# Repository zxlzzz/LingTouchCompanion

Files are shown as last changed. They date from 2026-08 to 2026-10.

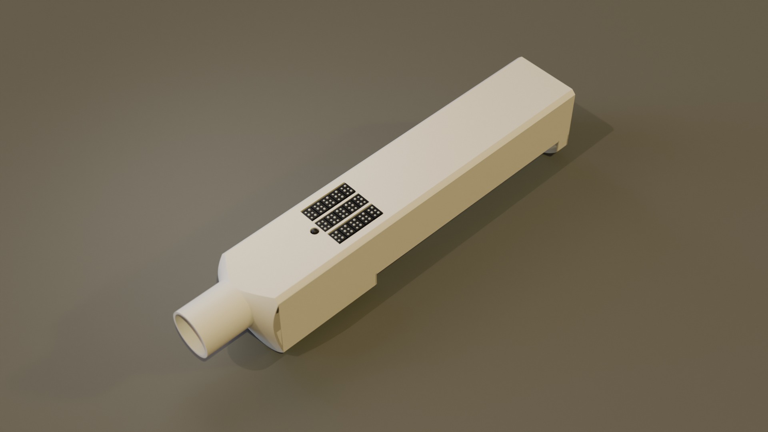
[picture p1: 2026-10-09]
BrailleModule_Video/ArrayPreview/EnclosureOverview.png

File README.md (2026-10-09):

# 灵触·随行 · LingTouch Companion

将视觉信息转换为触觉阵列反馈的辅助感知项目。当前实验使用手机摄像头、电脑端深度推理和 ESP32-S3，输出为 15 个六点模组，共 90 个触点。

给 Claude 的近期工作与审阅入口见 [CLAUDE.md](CLAUDE.md)。其中 PCB 布局和渲染外观仍待修正，验证记录不代表已经验收。

## 项目入口

| 目录 | 用途 |
|---|---|
| [visionss/](visionss/README.md) | 当前实验：米制深度、俯视栅格、BLE 传输与日志 |
| [single_point/](single_point/README.md) | 共用实验通路的单点告警对照条件 |
| [firmware/](firmware/README.md) | ESP32-S3 固件、引脚与通信协议 |
| [app/frontend/](app/frontend/README.md) | uni-app 手机应用 |
| [app/backend/](app/backend/README.md) | 地图、命令解析与视觉帧转发服务 |
| [vision/](vision/README.md) | 旧图像平面视觉管线，保留作回退 |
| [3mf/](3mf/README.md) | 前件、后件与两件式手柄的模型、完整生成代码及必要输入 |
| [PCB 修订稿](PCB_REDESIGN_2026-10-08/README.txt) | 五页原理图及实际板、98×98 mm 测试板的未布线布局草稿 |
| [阵列编排与渲染](BrailleModule_Video/ArrayPreview/README.md) | 离线网页编排与 Cycles 渲染流程，外观仍待修正 |

## 运行实验

在仓库根目录、配置好依赖的 Python 环境中运行：

```powershell
python visionss/phone_server.py
```

本机已验证环境为 `D:\anaconda\envs\LING\python.exe`。模型准备、手机连接与操作见 [实验说明](visionss/README.md)。

## 浏览器工具

| 文件 | 用途 |
|---|---|
| [depth_preview.html](depth_preview.html) | 图片深度预览；先运行 `python visionss/depth_server.py` |
| [ble_mobile_controller.html](ble_mobile_controller.html) | 手机 BLE 点阵控制，使用 ROT180 映射 |
| [ble_testbench.html](ble_testbench.html) | 点阵与帧数据调试，保留旧 PROD 映射 |

BLE 页面需要浏览器提供 Web Bluetooth；两种映射不同，须与实际装配方向对应。

离线标定和距离验证见 [TOPDOWN_VALIDATION.md](TOPDOWN_VALIDATION.md)，工具为 `validate_distance.py`、`check_balloon_depth.py` 和照片复制脚本 `prep_new_pics.py`。

模型、测试照片、实验输出、论文材料和本地协作记录不随 Git 上传；源码、HTML 工具与必要配置保留在仓库中。

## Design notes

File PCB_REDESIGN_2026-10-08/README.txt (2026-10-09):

灵触随行｜原理图与两款 PCB 摆件稿
基准：2026-10-08 读取的云端 test / PCB1_5；交付日期：2026-10-09。

审阅状态（2026-10-09 更新）
这两块板仍是待修正的布局草稿，尚不适合直接开始布线。后续复查已撤回“布局优化完成”的结论：
- U49的R7/R8反馈端焊盘距FB脚约9.6/11.5mm，两板均沿用该排列，需要重新组织反馈区。
- J1 USB与U53充电芯片中心距离，实际板约53mm、测试板约68mm，需要复查充电路径与局部摆放。
- 测试板的U50/L2等仍位于ESP下方，不利于探测、观察和返修；至少4mm净高尚未实物确认。
- 模组插座型号、插拔空间、螺钉头与支柱占位尚未落实。二维不重叠不能证明实物装配可行。
这些是后续检查指出的待解决项，本文件包尚未按它们修改。validation.json保留此前数字核对记录，
不表示上述问题已经解决，也不代表完整DRC、制造、载流或装配签核。

文件
Revised_Schematic.epro：嘉立创原生工程，包含全部五页修订原理图。
Actual_Placement.epro2：实际板，191.7065 × 35.7505 mm。
Test98_Placement.epro2：测试板，98 × 98 mm。
actual_placement.png、test_placement.png：正反面布局预览；背面已按从板底观察的方向翻转。
schematic_1 至 schematic_5：嘉立创导出的五页原理图预览。
validation.json：网络、布局、导出文件核对记录。

云端位置
项目 test；原理图 Revised_Schematic_20261008。
实际板 Actual_Placement_20261008；测试板 Test98_Placement_20261008。
两个 PCB 均为新增副本，原 PCB1_5 保留。实际板关联修订原理图；测试板是同一电路的独立 PCB 版本。
两板均保留六层：内层1 GND 平面、内层4 VCC 平面，其他四层供后续布线。
本稿仅摆件，未布线、未铺铜；Q1 封装自带的4个过孔保留。

原理图修改
1. 分为输入与充电、电源轨、ESP与控制、驱动1–8、驱动9–16五页；以功能框和明确网络名组织。
2. 增加 R40/R41/R42：SER、SRCLK、RCLK 的47kΩ下拉，避免上电阶段信号悬空。
3. 增加可选 J_NTC 接口。默认不焊，R22仍为51kΩ，温度检测仍处于禁用配置。
   若以后接100kΩ/B4100电池温度传感器，须同时把R22改为82kΩ；当前文件未替你改成该装配方案。
4. 保留现有16级595＋ULN、15个正式模组和U48实验位，保留既定电源、反向阻断、欠压与OE门控架构。
   U48、SW1、J_test、J_NTC按可选位标记不进BOM，焊盘全部保留；两板器件集合相同，共179件。
5. 主要电源选值保持当前版本：U49的R1=6.65kΩ、L1=1µH、MODE电阻30.1kΩ；VCC约3.53V；
   U50输出约2.00V、L2=2.2µH；U51固定5V、L3=1µH；IP2326约8.3V/1A配置。
   R23的0.5Ω仅位于充电芯片VIN滤波支路，L4主电流入口仍直接接VIN_C。

布局考虑
实际板保留原板框、U31–U45/U48的位置与方向，短边不加宽；ESP两排插座间距仍为25.4mm。
ESP与两排插座作为整体旋转180°并向板端平移，让天线伸到板外。充电接口和拨动开关移离天线端。
电源按各转换器局部成组，输入旁路、开关电感和控制小器件分区；595与ULN分布在正反面。
测试板保留全部16组，按4×4展开，留出模组插座与焊接空间；电源和ESP位于板的另一侧，外设接口靠边。
两板均保留原来的电池大焊盘、Q1封装过孔、每组595去耦与模组电容。
USB端C66与充电端C65分别保留局部旁路。后续VIN_C、电池入口和线圈电源的线宽/铜面仍须按实际电流完成布线。

已核对与仍待确认
已核对：179件一致；1062项已连接引脚的网络对应；原模组固定位置；ESP间距；板框尺寸；
焊盘间距、板边间距、跨面通孔与器件外形、安装孔；原生导出中的器件、封装和层设置；保存后重新打开。
原理图检查保留一组触觉模组的ATTRMATCHCODE警告，来自原有借用器件属性。模组应按真实触觉模组选用，不能按借用料号采购。
PCB原生DRC在后台未返回结果；上述核对不等于整板DRC或制造签核。当前未进行满载、温升、环路或BLE实测。

装配尺寸待确认：底板表面到ESP开发板底部最低器件需至少4mm净高，给其下约3mm高的L2留出余量。
该净高尚未得到实物确认；检查本稿时请优先核对排母高度。触觉模组插座仍须按原模组引脚尺寸选型，不能默认使用普通2.54mm排母。
本次未改固件。保留16级链，启用输出前应正确清零全部16级；最终固件适配另行处理。

主要查证资料
YD-ESP32-S3厂商尺寸与引脚资料：https://github.com/vcc-gnd/YD-ESP32-S3
IP2326手册：https://m5stack-doc.oss-cn-shenzhen.aliyuncs.com/1132/IP2326.pdf
RT6253A手册：https://www.richtek.com/assets/product_file/RT6253A=RT6253B/DS6253AB-04.pdf
TPS63070/701手册：https://www.ti.com/lit/ds/symlink/tps63070.pdf

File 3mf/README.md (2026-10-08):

# Complete 3D model generators

This folder contains the retained printed front, final rear, two-object handle,
all required source inputs and their generation code. Keep this folder together.
The desktop originals and former repository-root model directories are not
required. Installed dependencies are separate from the portable source set.

From the repository root, reproduce and verify all models with the local runtime:

```powershell
./3mf/.runtime/structural-runtime/Scripts/python.exe -B 3mf/regenerate.py --require-baseline
```

On another machine, use Python 3.11 and install the retained dependency versions:

```powershell
python -m pip install -r 3mf/requirements.txt
python 3mf/regenerate.py --require-baseline
```

Final model files:
- [Printed front](Headset_WOAD_Front_2026-10-03/camera_mount/Front_CS30_Mount_Print.3mf)
- [Printed rear](Headset_Rear/revised/Rear_Revised_Print_Ready.3mf)
- [Rear with head/battery references](Headset_Rear/revised/Rear_Revised_Wearing.3mf)
- [Two-object handle print project](Handle/Handle_Print.3mf)
- [PCB with U31-U45 and U48 socket models removed](PCB/3D_PCB1_5_2026-09-15_no_U31-U45_U48_headers.step)

The PCB STEP copy has its own [regeneration and verification instructions](PCB/README.md).

The original manual handle 3MF already has two model objects. Both are retained
with their original local meshes, component links, build transformations, assembly
metadata, printing settings and thumbnails. No new cut or inferred assembly pose
is introduced. The unchanged generated handle archive is byte-identical to the
supplied desktop `1.3mf`; the printed front is likewise byte-identical to its
supplied final source. Both geometries remain mesh-based because 3MF carries no
CAD construction history.

Entry points for later edits:
- Front: `Headset_WOAD_Front_2026-10-03/camera_mount/build.py`, `modify_front()`.
- Rear: `Headset_Rear/build.py` and `Headset_Rear/revised/build.py`.
- Handle: `Handle/build.py`, `modify_part()` for `housing` or `cover`, in each
  original native mesh coordinate frame (millimetres).

Front-only, rear-only and handle-only `regenerate.py` scripts live in the
corresponding folders. `--verify` validates edited front/handle meshes against
the generated outputs; `--require-baseline` also requires unchanged source
identity. The rear construction retains the original array-hash, topology,
contact-surface and preserved-region checks.

Required geometry inputs are in `Headset_Inputs`, `Headset_Rear/inputs` and
`Handle/inputs`. `requirements.txt` is shared. `.runtime` contains this machine's
reusable dependency environment and is excluded from Git; use its Python directly
or `python -m pip`, since moved virtual-environment launcher scripts may retain
their original installation paths. No existing intermediate is required.
Generated `geometry` and `checks` folders may be removed after running.
Digital identity confirms reproduction of the supplied data, not physical fit.

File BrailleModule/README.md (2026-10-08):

# Braille module - static exterior model

This folder is independent of `3mf/`. The model follows the supplied module PDF
and Hsinlung's material instructions: a black housing and slightly grey white
tactile dots. It includes the housing, lower collar/carrier, locating tab,
twelve stamped terminals and six individually named dots.

## Files

- `BrailleModule.blend`: editable Blender 4.5 scene, materials and preview lighting.
- `BrailleModule.glb`: portable model with materials and separate parts; no studio objects.
- `BrailleModule.step`: millimetre CAD assembly with the same parts and colours.
- `Preview.png`, `Preview_Back.png`, `Preview_Top.png`, `Preview_Dots.png`: rendered views.
- `parameters.json`, `build.py`, `requirements.txt`: retained editable generator.
- `inputs/Braille_Module_Reference.pdf`: unchanged supplied reference.
- `inputs/Touchpoint_Reference.jpg`: supplied physical-module photograph.
- `Verification.json`: geometry, dimensions and export readback checks.

## Dimensions and interpretation

The PDF explicitly dimensions the body as 8.2 x 6 mm, with a height of 20 mm
excluding the terminals. The maximum base width is 10.82 mm, including the
asymmetric tab. Terminals extend 3.8 mm below the base. Their pitch is 1.25 mm,
tail width 0.30 mm and sheet thickness 0.10 mm. The 4.96 mm drawing dimension
spans the inner faces of the two terminal sheets, giving 5.06 mm centre spacing.
The two rows use the 2.05 and 2.65 mm opposite-view end offsets and are staggered.

Unmarked dimensions, including dot diameter/pitch, recesses, collar height and
terminal shoulders, are reconstructed from drawing proportions. Shell wall and
cap thickness are visual construction choices. These are recorded separately
from dimensioned values in `parameters.json`. The interior actuator mechanism
is not established by this document and has not been invented in the model.
Actual lower carrier colour and plating appearance remain unverified.

All six dots have spherical-cap heads, matching the curved tips in the PDF
and the two raised points in the supplied photograph. The former flat-topped
visible cylinders have been replaced. The 0.45 mm cap height is an exterior
estimate, not an explicitly dimensioned value: the PDF's 0.4-0.5 mm figure is
the raised-point height above the housing. Cap diameter and dot spacing retain
the initial model values. Housing, base, terminals, positions and materials
remain unchanged.

All six dots are in the same retracted static state, with their apices flush
with the 20 mm tactile face and their curved sides inside the openings. There
are no keyframes or raised-dot states. In a top view with the locating tab at the top, dots 1/2/3
form the left column and 4/5/6 the right column, following PDF page 6. Each dot
has its own origin and can later move along its local +Z axis. Terminal names
`Pin_01` through `Pin_12` are geometry indices, not a verified electrical map.

Blender and GLB store metre coordinates, with Blender displaying millimetres.
STEP uses millimetres. The overall assembly is 10.82 x 6 x 23.8 mm.

## Regenerate

On this machine, from the repository root:

```powershell
& '3mf/.runtime/structural-runtime/Scripts/python.exe' -B 'BrailleModule/build.py'
```

This uses the existing modelling runtime without writing model outputs into
`3mf/`. On another machine, install `requirements.txt` in a Python 3.11
environment and run `python -B build.py`. `--no-render` skips the preview images.

Verification checks each CAD solid and tessellated mesh, reloads the STEP/GLB,
checks the overall dimensions and ensures all six dot apices remain flush. It does
not establish exact agreement of unmarked details with the physical module.

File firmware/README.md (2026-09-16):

# ESP32-S3 触觉固件

通过 SPI 驱动15个六点模组，BLE接收15字节触觉帧。

## 烧录

Arduino IDE 安装 **esp32 by Espressif Systems**，选择 **ESP32-S3 Dev Module**，打开 [当前 V2.8 固件](braille_15module_prod/braille_15module_prod.ino) 并烧录。

`braille_15module_reverse/` 为旧 V2.3 版本，保留作历史参考，不是当前默认入口。

## 引脚与协议

| 信号 | GPIO |
|---|---|
| SER / SRCLK / RCLK | 11 / 12 / 10 |
| OE# / SRCLR# | 9 / 8 |
| 按钮 | 6 |

BLE 服务 `FFE0`：写入特征 `FFE1` 接收15字节，每字节低6位对应一个模组；通知特征 `FFE3` 中，`0x01` 为刷新完成，`0x04` 为按键扫描请求。

V2.8 默认全量刷新约220 ms。电脑端实验通路见 [visionss](../visionss/README.md)；浏览器调试可使用根目录两个 BLE 工具，注意其 ROT180 / PROD 映射差异。

[PCB历史摘要](PCB历史检查摘要.md) 与 [早期改版记录](pcb_v2_revision.md) 仅供追溯，不代表当前生产板状态。

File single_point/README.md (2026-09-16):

# 单点告警对照条件

共用 [实验视觉通路](../visionss/README.md) 的拍摄、深度推理、调度、日志和 BLE，仅将空间栅格输出替换为二值告警。

在仓库根目录运行：

```powershell
python single_point/alert_server.py
```

默认 HTTPS 8761；加 `--no-ble` 可不连接设备运行。终端操作与空间触觉条件一致。

`alert_pipeline.py` 检测前方0.5–2.5 m、左右各0.35 m、离地0.10–1.80 m范围；占据比例阈值0.035，至少8点。触发时点亮 M11 整个模组，输出位置由 `visionss/experiment_server.py` 中的 `ALERT_MODULE` 定义。

正式实验前需用实际障碍物核对阈值与检测范围。

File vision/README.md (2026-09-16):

# 旧视觉管线

早期图像平面相对深度 / 边缘检测方案，保留作回退。当前米制深度实验使用 [visionss](../visionss/README.md)。

## 运行

依赖见 [requirements.txt](requirements.txt)。以下命令在仓库根目录运行：

```sh
python vision/phone_server.py --no-ble
python vision/main.py --mode edge --camera 0 --debug
```

`phone_server.py` 提供手机拍摄与 BLE 通路；去掉 `--no-ble` 可连接设备。`main.py` 支持 `depth` / `edge` 模式及文件、串口、HTTP等输出，完整参数见 `--help`。

## 工具

| 文件 | 用途 |
|---|---|
| `live_preview.py` | 摄像头实时预览 |
| `bench_test.py` | 驱动链调试 |
| `export_sample.py` / `generate_comparison.py` | 样本导出与对比图 |
| `calibrate_balloon_color.py` / `color_bias_test.py` | 旧颜色检测与偏差验证 |
| `frame_converter.py` / `scan_link.py` | 15字节帧转换与 BLE 连接 |

旧串口等输出路径与当前 BLE 固件不一定使用相同帧格式，接硬件前核对对应输出实现。生成数据位于 `data/`，不提交。

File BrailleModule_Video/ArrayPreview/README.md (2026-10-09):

# Array preview and Cycles production rendering

`index.html` is the offline point-pattern editor and interactive preview. Final pictures and video come from **Cycles in `EnclosedArray.blend`**. Browser shadows, aperture shading and materials are preview approximations.

## Review status — 2026-10-09

Hsinlung has viewed these stills and judged the appearance insufficiently realistic. Raised and retracted dots are similarly bright, and the module top does not match the supplied physical references. The files below are retained for review, not approved production output. No full animation is approved.

The latest discussion proposes matching the photograph on one module first: camera and state, grazing directional light and ambient fill, separate retracted depth and raised exposure, then dot subsurface appearance and top-face shading. Fine texture follows those checks. This revision has not been implemented. A suggested −0.3 mm rest offset is an unmeasured trial value; shifting the whole existing animation would also lower its raised exposure.

`assets/textures/Plastic003/` retains Hsinlung's selected procedural material candidate, with its source, CC0 license and hashes. Its maps are not applied to the current scene. The unselected Plastic012A download was removed. See the repository's `CLAUDE.md` for the wider review handoff.

## Current stills

- `PinCloseup.png`: the browser's tactile-array preset, with the checker pattern.
- `SwitchPreview.png`: the browser's enclosed-switch preset.
- `EnclosureOverview.png`: the browser's whole-handle preset.

These replace the preceding browser screenshots: 1920 × 1080, 192 samples, environment lighting, depth of field and light monochrome grain. Revised stills require Hsinlung's acceptance before a full shot is rendered. No full animation has been rendered during this migration.

## Edit and render

Open `index.html`, edit or import a 10-row × 9-column sequence, then choose **导出 JSON**. The page is self-contained and needs no network. `launch.cmd` optionally serves it at `http://127.0.0.1:8867/`.

Run the retained runtime from the repository root:

```powershell
# Update the existing scene and render three review stills.
& '3mf/.runtime/structural-runtime/Scripts/python.exe' -B 'BrailleModule_Video/ArrayPreview/render_cycles.py' stills

# Import a newly exported browser sequence and rebuild the stills.
& '3mf/.runtime/structural-runtime/Scripts/python.exe' -B 'BrailleModule_Video/ArrayPreview/render_cycles.py' stills --sequence 'C:/path/frames.json'

# Only after still approval: render lossless 16-bit PNG sequences.
& '3mf/.runtime/structural-runtime/Scripts/python.exe' -B 'BrailleModule_Video/ArrayPreview/render_cycles.py' render

# Compose PNG sequences into H.264 MP4 with changing monochrome grain.
& '3mf/.runtime/structural-runtime/Scripts/python.exe' -B 'BrailleModule_Video/ArrayPreview/render_cycles.py' compose
```

`prepare` updates the existing scene without rendering. `verify` checks the saved animation. `--shot near|switch|whole|all` selects a shot; `--width`, `--height`, `--samples` control quality. `--frame` selects a still frame. `--fps` and `--tail` configure the timeline during preparation. Defaults: 1920 × 1080, 192 samples, 30 fps, one second after the final JSON command.

`assets/sequence.json` is the active sequence. The current five-frame sequence is exactly the browser's built-in demo: off, checker, cross, all on, off. The review still uses frame 46, 1.5 seconds into the sequence: 45 raised points at maintained height. This is an appearance demo, not an experiment log. Timestamps are milliseconds; the first timestamp becomes time zero. JSONL, a `{frames: [...]}` object, a single record and a single 10 × 9 matrix are also accepted.

Full shots write `frames/<shot>/frame_0001.png` onward. Composition writes `Array_near.mp4`, `Array_switch.mp4` and `Array_whole.mp4`. The Blender runtime includes the FFmpeg encoder; no separate installation is needed. Optional `--ffmpeg` selects an external encoder. The original PNGs remain unmodified during composition.

## Scene and material sources

The existing assembly is retained: 15 modules, 90 independently moving complete pins, the two original handle meshes and the bullet-head switch. Original vertices, topology, module placements and handle placements are preserved. Three-segment bevel modifiers round module edges by 0.06 mm and handle edges by 0.18 mm. Smaller shader bevels soften microscopic highlights.

Blender's bundled `interior.exr` is packed into the world, with one soft window light. The grey tabletop extends beyond the camera frustum. Module black plastic uses dielectric reflection with no metallic or emissive shading. `assets/textures/MouldDetail.png` is extracted from `../inputs/Touchpoint_Reference.jpg`: perspective correction, pin/rim masking and removal of broad lighting. Grayscale detail controls narrow roughness variation and microscopic bump rather than baking photographed highlights into the black colour. `../inputs/PhysicalMotionReference.mp4` is also the visual reference. The photograph has limited detail; this is an appearance reconstruction, not a measured PBR scan.

Ivory PLA printing detail keeps the browser's existing settings: 0.2 mm side layers, 0.42 mm diagonal top paths, 0.0035 mm side relief and 0.0014 mm top relief. These are visual settings. All image assets needed by Cycles are packed into the .blend.

The three cameras use `viewer3d.js` `setView` directions, bounds fitting and horizontal field of view, adapted to 16:9. Focus is on the tactile face, switch nose or device centre; apertures are f/22, f/32 and f/8. Motion blur uses a half-frame shutter. Cameras stay fixed; dot motion supplies motion blur.

## Motion and mapping

`assets/motion.json` is the shared source: 0.7 mm peak, 0.45 mm hold, 33.333 ms rise, 66.667 ms peak pause, 50 ms settle and 50 ms retraction. These remain provisional visual settings informed by the supplied 30 fps clip. Fractional linear keyframes preserve short stages and let Cycles evaluate shutter subframes. Repeated identical commands leave an ongoing stroke alone. Mid-stroke commands reverse from the current height.

M1–M15 go left to right, then top to bottom. Each module's upper row is dots 3/2/1 and lower row is 6/5/4. The PCB arrangement stays three columns by five rows: approximately 11 mm horizontal and 6.5 mm vertical centre spacing, including the first column's 0.127 mm offset.

`CyclesVerification.json` records mesh preservation, references, cameras and animation checks. Motion is compared directly against the actual `controls.js` function, including mid-stroke reversals; all 90 saved animations are checked at fractional frames. This verifies migration and timing, not perceptual realism or manufacturing fit.

## Geometry and browser maintenance

`ModuleArray.blend`, `build_array.py` and `surface_finish.py` retain the source array. `build_enclosure.py` is only for an intentional geometry rebuild; it reapplies production materials and animation after exporting the preview GLB. Routine appearance or sequence changes use `render_cycles.py` on the existing scene.

The enclosure source stays `../../3mf/Handle/inputs/Handle_Original.3mf`, with 71,860 housing and 670 cover triangles. STEP offsets recover the assembly frame. The 30.7 mm array translation, original slots and 90 crown clearances are retained; see `EnclosureVerification.json`. These checks do not establish PCB mounting fit.

The switch retains the user-directed 20 mm height excluding terminals, and smooth 4.2 mm wide, 2.6 mm high bullet nose. Its tip stays 1.2 mm above the faceplate; it differs from the BOM's 25 mm TSA06131 variant. It is static and does not control BLE. Dimension provenance remains in `SwitchVerification.json` and `../inputs/Khon_TSA06131_Reference.pdf`.

Browser sources are `viewer3d.js`, `controls.js` and `index.template.html`. Run `npm run build` to regenerate the self-contained HTML. Dependencies remain pinned, with licenses in `vendor/`. The page has no real-hardware control.

When only the template, JSON or preview GLB changes, `node build_web.mjs --page-only` reuses the existing viewer bundle and updates the embedded page assets.

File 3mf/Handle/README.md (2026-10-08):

# Manual two-object handle recovery

`inputs/Handle_Original.3mf` is the unchanged manual source supplied on 2026-10-06.
SHA256: 25cd55ec492a72cccf81dd1d16a50490106574b93a2b63005601ec6ab786d6c6.
`Handle_Print.3mf` contains the original two separately selectable model objects;
no added split plane or new joint is constructed.

Run `python 3mf/Handle/regenerate.py --require-baseline` from the repository root.
`source.py` resolves the archive's external production-model links and all build
and component transforms. `build.py` recovers each native mesh and print mesh;
`export.py` preserves the whole source archive for an unchanged build. Verification
compares every vertex, triangle, transform and ZIP member, including print settings
and assembly metadata.

The housing has 35,944 vertices and 71,860 triangles. The cover has 329 vertices
and 670 triangles. Both have closed manifold meshes. The housing's original mesh
contains eight constituent solid components; the cover contains one. These
source components are retained exactly, without welding or automatic repairs.
This is an exact recovery of the source model objects, not a new physical
connectivity or manufacturing certification.

For future changes, edit `modify_part()` in `build.py`, using each original native
mesh frame. `--verify` accepts deliberate edits while reporting baseline changes;
`--require-baseline` requires the entire finished archive to remain identical.

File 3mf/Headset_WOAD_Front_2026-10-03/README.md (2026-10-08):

# Retained front and rear

This directory is part of the complete `3mf` source set. See [../README.md](../README.md)
for dependency setup, all final outputs and the combined regeneration command.
From the repository root:

```powershell
python 3mf/Headset_WOAD_Front_2026-10-03/regenerate.py --require-baseline
```

This rebuilds the retained rear and the actual printed front. Front-only entry:
`camera_mount/regenerate.py`. The front is edited through `modify_front()` in
`camera_mount/build.py`; it uses the source print axes with bed centre
(165, 160, 0) removed. The immutable finished front archive is retained in
`../Headset_Inputs/Front_CS30_Mount_Final.3mf`.

The unchanged front archive is reproduced byte for byte. Old camera/head fit
assemblies are not reused. The rear uses the anatomical tray/fill inputs in
`../Headset_Rear/inputs`, its construction scripts and provenance. Its wearing
reference also requires the original head STL and registration in
`../Headset_Inputs`. No deleted file or desktop original is required.

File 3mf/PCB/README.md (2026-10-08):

# PCB STEP with module sockets removed

Use `3D_PCB1_5_2026-09-15_no_U31-U45_U48_headers.step` for the modified PCB assembly.
The original 2026-09-15 export is retained unchanged under `inputs/`.

Only the 16 female socket models at U31-U45 and U48 are removed. U46 and U47
are chips in this export and remain unchanged. PCB copper, holes,
other components, colours and placements are preserved.

Regenerate from the repository root:

```powershell
python 3mf/PCB/remove_module_headers.py
```

The generator requires only Python's standard library. To repeat the CAD check,
install `cadquery-ocp==8.0.1.1.0` and run with `--verify`. This machine already
has that dependency in `3mf/.runtime/structural-runtime`.

Verification requires the original source SHA256, validates all STEP references,
and checks that all retained entity records except the root placement list are
byte-identical. The unused shared socket definition is also removed to prevent
it from appearing as an unattached object. CAD import confirms 179 to 163 top-level objects,
with unchanged solid/face/edge counts, volumes, centres and bounds for every
retained object. This edit changes the exported 3D assembly only.

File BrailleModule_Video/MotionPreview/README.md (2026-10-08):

# Module motion preview

Run `launch.cmd`, then open <http://127.0.0.1:8866/> in Chrome or Edge. If the
preview is already running, open that address directly. The launcher uses the
existing project Python runtime and serves this folder on the local computer.

Click the picture to focus it, then press **1–6** or the corresponding numeric
keypad keys. Each key controls its own dot: retracted → higher peak → lower
maintained position. Press the same key again to retract it. The six buttons
provide the same controls. **全部收回** retracts all dots; **显示编号** identifies
their positions. Held keys do not repeatedly toggle a dot.

The current visual settings are:

| Stage | Height / duration |
| --- | --- |
| Retracted | 0 mm |
| Rise | 33 ms, reaching 0.70 mm |
| High peak pause | 67 ms |
| Settle | 50 ms, reaching 0.45 mm |
| Maintained | 0.45 mm, until toggled off |
| Retract | 50 ms |

These heights and timings are provisional preview choices, not measured
manufacturer specifications. The three-stage behavior follows Hsinlung's
requirement. Both the browser and Blender scene read the same
`assets/motion.json` profile and use firm linear strokes, followed by a stable
hold. The fixed-camera preview uses actual 3D-rendered height samples
from the approved photographic scene, including changing occlusion, shadows,
and highlights. It displays one nearest rendered height per frame to retain a
single sharp moving contour. The dots lift along their axes without elastic
wobble. The six pins now use one neutral grey-white finish for the complete
round head and straight shaft, with a small smooth join instead of a sharp
shading boundary. Their camera-visible body colour is kept uniform following
Hsinlung's correction. The photographic lighting and housing remain intact.

`build_appearance.py` creates `AppearanceStudy.blend` from the archived
photographic setup; `build_motion.py` adds the existing motion to this corrected
appearance. `render_assets.py` renders the corresponding preview poses.

The approved static scene is archived in
`../Archives/PhotoStudy_2026-10-07/`, including `ReferenceStudy.blend` and its
photographic previews. The source `../PhotoStudy/` remains available.

`ModuleMotion.blend` contains the editable 3D scene and a 60 fps sample timeline
(frames 1–430): each dot rises in turn, all remain raised, then all retract.
Select the root object **BrailleModule** to find `Dot_1_height_mm` through
`Dot_6_height_mm` under Object Properties → Custom Properties. Their animation
curves can be adjusted in the Graph Editor; timeline playback applies the
existing height keys. The browser provides the live keyboard controls.

The [user-provided Dot Pad video](https://www.youtube.com/watch?v=iSmRM2PUBzA)
was inspected around 6–8 seconds for axial movement and changing hole
occlusion. Revision 2 primarily follows Hsinlung's supplied physical-module
video (`../inputs/PhysicalMotionReference.mp4`, 11.4 seconds, 30 fps). In that
clip, lift is visible between frames
69–70 (2.300–2.333 s) and 256–258 (8.533–8.600 s); release is visible between
frames 300–302 (10.000–10.067 s). These observations support short strokes
and firm stops. Camera movement, compression, and the frame rate prevent
precise measurement of the high-to-maintained drop. Its height difference and
timing remain provisional choices for the requested three-stage effect.

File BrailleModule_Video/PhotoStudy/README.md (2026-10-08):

# Photographic module study

One clean photographic material and lighting setup, with two camera views:

- `ReferenceStudy.png`: 1200 x 1600, composition based on the supplied physical-module photograph.
- `VideoCloseup.png`: 1920 x 1080, a closer horizontal view for assessing later video footage.
- `ReferenceStudy.blend`: editable, self-contained scene containing both cameras.
- `Verification.json`: geometry, source and render checks.
- `build.py`: reproducible scene setup.

The study uses the accepted model in `../BrailleModule.blend`. Its 22 component
meshes and local positions remain unchanged. All six dots stay retracted and
independent. There is no animation, dirt, wear or image compositing. The whole
assembly rests on its back broad face on a pale laminate table.

Clean moulded-polymer roughness and microrelief, grey-white smooth tactile
heads, directional lighting and the table's reflected light determine the
appearance. Perspective cameras and optical depth of field provide the two
views. The top's grey reflection does not represent a change to a metal shell.
These are appearance trials; single-image evidence does not establish the exact
physical material, roughness or lens of the reference.

References: the supplied `../inputs/Touchpoint_Reference.jpg`, the supplier PDF
for geometry, and [Dot Inc's supplied video](https://www.youtube.com/watch?v=iSmRM2PUBzA).
The video was inspected in the browser at 6, 12, 18, 25, 32, 45 and 51 seconds;
the low-angle view around 6 seconds was especially useful for surface highlights.
Dot Pad imagery informs photography only, not this module's design.

Rebuild from the repository root using the existing Blender runtime:

```powershell
& '3mf/.runtime/structural-runtime/Scripts/python.exe' -B 'BrailleModule_Video/PhotoStudy/build.py' --final
```

The original `BrailleModule/` and frozen parent-folder source files are preserved.

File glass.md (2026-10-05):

# 国赛眼镜硬件方案 v10（2026-10-02）

本文件记录当前硬件组成、用途和连接依据。部件类别与功能分工已基本明确；没有查到必须推翻整体架构的硬件冲突，但尚未完成整机验证。当前不继续搜索具体商品型号，也不展开固件、采集参数或算法实现。

## 已定方向

- 继续采用 **CS30＋Radxa ZERO 3W**，相机、主板、电池等都放在眼镜上。
- **预警和障碍分析都用这副眼镜的数据。计算位置仍在权衡：** 眼镜采集后经 Wi-Fi 发手机计算，或眼镜本地计算、只把结果发手机。两种做法眼镜上的器件相同；外壳散热按眼镜本地计算的满负荷预留，计算位置最后怎么定都不用改壳。
- **全机免焊：** 优先购买成品模块、成品电源及预制线束，需要焊接或装配的部分尽可能由卖家或代工完成；不自行制作电池组，不另做自研主控 PCB。
- **电池尚未定型，已查资料保留在第四节。** 整机以单个Type-C接口输入稳定5V供电为目标，优先5V/3A成品电源；内部向主板及相机分电的成品连接方案尚未定完整。成品候选、代工入口和续航估算用于后续比较，不代表已经选定或完成装机验证。
- **整机约300g可接受；电池位置不受限，必要时做成头环、电池放后脑。**
- 学生项目，支持一定的室外使用，不要求覆盖强烈日光下的所有场景。
- **声音和麦克风改用单独的蓝牙耳机，直接连手机；头戴件上不放麦克风、功放、喇叭。**

## 硬件分工与 WOAD 参考边界

| 部件 | 用途 | 是否另需驱动板 |
|---|---|---|
| CS30成品相机 | 获取深度、红外和彩色数据 | 已包含相机内部电路，不另加相机或红外发射驱动板 |
| ZERO 3W | 读取传感器、处理数据、通过Wi-Fi与手机通信 | 本身就是主控板；本地全部算法的性能尚未验证 |
| IMU模块 | 测量头部转动与倾斜，为姿态补偿提供数据 | 3.3V接口匹配的成品模块可直接接I²C，不另加电平转换板 |
| USB连接与供电分配件 | 连接相机和主板，并向各部分分电 | 需要匹配的成品连接方案；单个Type-C入口不等于内部无需分电 |
| 散热件、外壳、支架、线束 | 散热、固定器件、保持安装关系、保护连接 | 按实际器件和佩戴条件落实 |

[WOAD论文](https://www.nature.com/articles/s41467-025-58085-x)采用CS30、ARM板、用于压缩策略加速的FPGA，以及耳机和三颗贴肤振动马达。我们保留CS30＋ARM主板的基本分工；基础采集与传输不以增加FPGA为前提，但不能据此继承WOAD的整机功耗、延迟和续航结果。触觉输出沿用本项目已有的独立触觉装置，当前清单不新增额头/太阳穴振动马达。外接Wi-Fi天线暂为可选件。

## 一、眼镜上必须有的东西

| 器件 | 当前选型 / 数量 | 用途与安装要点 |
|---|---|---|
| 深度＋彩色相机 | **Synexens CS30 ×1** | 提供深度、红外和彩色数据。带壳约 **89.94×30×25mm、74g**；已有官方 STP。前部安装，**镜头整体下倾约20°**：按镜头离地约1.6m计算，深度视场（上下75°）下沿可见脚前约1m的地面，上沿高出水平线约17°；彩色视场（上下59.5°）上沿高出水平线约10°。这是几何覆盖估算，不是障碍检测保证；IMU能提供姿态补偿依据，但不能补回视野外的图像。**镜头正前方直接开孔，不加普通透明罩**，避免ToF内部反射干扰。平均约3W。 |
| 采集与无线主板 | **Radxa ZERO 3W ×1，2GB＋16GB eMMC、已焊排针；原候选SKU RS107-D2E16H1W15** | USB读取相机、读取IMU、Wi-Fi通信。采购时另核实双频无线硬件版本：官方说明早期AP6212仅2.4GHz，V1.12I为双频Wi-Fi 6，不能仅凭内存/SKU认定无线版本。板面 **65×30mm**。USB2.0 OTG口作供电口，USB3.0主机口接相机。主机口标称500mA不足以覆盖CS30平均约0.6A需求，相机需另安排供电路径。排针与杜邦头高度按实物留位，原估算含线弯约20mm。 |
| IMU | **ICM-42688-P成品模块 ×1；具体商品暂不定** | 保留已核对接口的 [LogicalEdges Qwiic板](https://www.elecrow.com/icm-42688-p-ultra-low-power-imu-breakout.html) 作为参考，不视为必购商品。若采用该接口，可用Adafruit 4397（Qwiic转杜邦母头，150mm）：红3.3V、黑GND、蓝SDA、黄SCL。拟接 **I2C4-M0：物理27脚SDA、28脚SCL**。IMU与相机固定在同一刚性支架上；不能靠IMU单独长期准确估计位移。 |
| 相机数据与独立供电 | **需要此功能；8086 Consultancy USB-C/PWR Splitter作为已研究候选** | [厂商接线表](https://lectronz.com/products/usb-c_pwr-splitter)：DATA口只通D+/D−与GND，CC为5.1k下拉，5V不与主机相通；DATA/POWER口带5V，CC为10k上拉，接CS30；POWER口进5V。仅用于5V设备，厂商明确其不属于标准USB方案，与本机组合尚未验证。它负责相机的数据/电源合路，不能单独解决整机一个入口向多路分电。 |
| USB线 | **支持USB2.0数据的成品线；数量、接头及长度随分电方案确定** | 相机数据链路不能使用仅充电线。主板与相机附近优先短线，弯头方向及插头占用空间按实际安装确认。 |

## 二、外壳先预留，具体安装待验证

| 器件 | 候选 | 当前状态 |
|---|---|---|
| 散热件 | **Radxa Heatsink 5519A ×1** | [官方适配ZERO 3W/3E的散热件](https://radxa.com/products/accessories/heatsink-5519a/)。完整尺寸以实物为准。有用户反映装了它仍明显发热；外壳散热按眼镜本地计算的满负荷预留，CS30 与 Radxa 都不整体封死。 |
| 外接 Wi-Fi 天线 | **Taoglas FXP830.07.0100C ×1，可选** | [官方产品](https://www.taoglas.com/product/freedom-fxp830-2-44-9-6-0ghz-flex-pcb-antenna-ipex-mhfi-2/)。FPC约42×7mm、100mm馈线、U.FL/IPEX MHF1，覆盖2.4/5GHz。是否装用由佩戴传输测试决定；使用时按[Radxa外置天线说明](https://docs.radxa.com/en/zero/zero3/accessories/zero3w-antenna)切换配置。避开电池及散热金属遮挡。 |

## 三、接线（全部插接，不焊）

### 电源与 USB

| 从 | 线 | 到 |
|---|---|---|
| 整机Type-C 5V入口 | 成品分电件，待定 | 主板与相机供电分支 |
| 主板5V分支 | 接头/线束待定 | Radxa USB2.0 OTG口（供电） |
| 相机5V分支 | 接头/线束待定 | 候选Splitter POWER口 |
| Radxa USB3.0 主机口 | C对C短线 | Splitter DATA 口 |
| Splitter DATA/POWER 口 | C对C短线 | CS30 |

此表是目标连接关系，不是已落实的完整单口供电装配方案。原PB2S两口分别给主板和相机供电的接法不再作为当前默认方案。外部电源、内部电流余量、充电与开关机方式留待供能讨论恢复后确定。

### Radxa 40针排针（物理脚号）

| Radxa 脚 | 接到 |
|---|---|
| 1（3.3V） | IMU（Qwiic 红） |
| 6（GND） | IMU（Qwiic 黑） |
| 27 | IMU SDA（Qwiic 蓝） |
| 28 | IMU SCL（Qwiic 黄） |

## 四、电池与供电选型资料（已研究，尚未定型）

以下保留本轮查到的可用资料及链接，核对日期为2026-10-01。研究比较以轻量成品电源和厂家整包代工为主；没有选定电池、下单或联系厂家。已有候选不因“暂不定型”而删除，也不把尚待核实的商品当成直接可用的最终方案。

### 4.1 对成品电源的要求

| 项目 | 本项目要求或比较方法 |
|---|---|
| 交付范围 | 厂家完成电芯组装、充电、保护、5V稳压输出、封装及测试，我们只插线和安装。单卖裸电芯、保护板或升压板不算完整交付。优先国内成品或接受少量打样的OEM。 |
| 输出电压 | 稳定5V；主板和当前相机供电链路不使用9V/12V。电源可以具备快充功能，但本机连接只用5V，不增加高压诱骗模块。 |
| 输出能力 | **优先5V/3A连续输出**，为启动、无线发射峰值留余量。这是电源能力筛选值，不是整机平均功耗15W。只有5V/2A的轻量款保留为条件候选，须确认实际峰值和低电量下仍有余量。 |
| Type-C行为 | 必须支持对外供电而非仅输入充电，能通过C对C线正常启动、持续运行；明确低负载自动关断、唤醒及低电量关机行为。无需电池数据通信或专有系统绑定。 |
| 内部分电 | 目标为一个整机Type-C入口，内部再分给主板及相机。现有8086 Splitter是相机数据/电源合路件，不是完整多路分电器；分电件需适配Type-C识别、线缆载流与电压降，并避免向主机USB电源回灌。 |
| 能量口径 | 同时记录电芯标称Wh和**5V端额定/实测输出Wh**；不能把3.6V或3.7V标称mAh直接按5V计算。比较实际输出时注明测试电流、模式和地区版本。 |
| 重量与形状 | 统计完整电源的电芯、保护、充电/稳压电路和外壳重量；线材与固定件另计后纳入整机。可用扁平或圆柱形、后脑头带安装；约300g是整机接受方向，电池暂无硬性80g指标。 |
| 保护与机械 | 成品应有过充、过放、过流、短路及温度保护说明，接口和封装适合随身固定。OEM提供完整尺寸、重量、接口位置、持续/峰值输出和测试报告。不能用裸电芯指标代替电源包指标。 |
| 暂非必需 | 不要求边充边用、UPS不断电、无线充电、9V/12V输出；未确认充电时输出连续性的产品按停机充电考虑。 |

要求依据：[Radxa 5V供电及接口说明](https://docs.radxa.com/en/zero/zero3/hardware-design/hardware-interface)、[CS30厂家对ARM主板外接供电的建议](https://tofsensors.com/products/rgbd-3d-camera)、[8086 Splitter连接表](https://lectronz.com/products/usb-c_pwr-splitter)。相机平均约0.6A；主板的实际瞬态负载仍需整机测量，不以旧的平均电流相加代替峰值检查。

### 4.2 已查成品候选

| 候选与来源 | 完整电源重量 / 外形 | 能量与5V输出 | 对本项目的价值与限制 |
|---|---|---|---|
| **[NITECORE NB10000 Gen4 国内版](https://www.nitecore.cn/product/nb10000gen4)** | **143±5g**，117×47×15mm，不含配件 | 电芯39Wh（等效10000mAh）；额定输出6800mAh@5V/3A，即**34Wh**；节能模式7200mAh@5V/1A，即36Wh。双USB-C，单口列有5V/3A，双口总输出5V/3A。 | 当前研究的轻量成品比较基准，未定为最终采购。扁平、比原PB2S组合轻；不能把22.5W快充功率当成5V档功率，也不能把36Wh节能模式数据套到任意负载。 |
| **[ISDT 艾斯特 PB40 mini / PB40C2M](https://www.isdt.co/pb4020mini.html?lang=hk)** | **165±10g**，64×47.5×28mm | 等效10000mAh，标称38.7Wh；额定6240mAh@5V/2A，即**31.2Wh**。双USB-C，输出规格含5V/3A。 | 较短、较厚，可比较后脑安装空间；双口同时输出上限、启停行为需按实际版本确认。不要与同页5000mAh的PB20 mini混淆。 |
| **[NITECORE Carbon Battery 6K 国内版](https://www.nitecore.cn/product/carbon_battery_6k)** | **88g**，直径22.8×90mm | 6000mAh/3.6V，即21.6Wh；国内页额定3500mAh@5V、典型1A，即**17.5Wh**。单USB-C充放电，最高**5V/2A**。 | 重量接近WOAD所称80g，圆柱适合头带侧后方；能量更少，且不满足优先3A的筛选值，只有负载验证有余量后才适合使用。海外资料曾列18.5Wh，本表统一采用国内17.5Wh口径。 |
| **XTAR PB2S＋两颗Vapcell N40，原方案比较基准**：[PB2S原始实测](https://lygte-info.dk/review/Review%20Charger%20Xtar%20PB2S%20UK.html)、[N40厂家规格](https://www.vapcelltech.com/h-pd-193.html) | 盒体原记录约85g，测试样品86g；N40约48g/颗，合计约**181–182g**。测试盒体125×58×27.7mm。 | 两颗N40典型合计8000mAh/3.6V，即28.8Wh电芯能量，**没有这套组合已确认的5V输出Wh**。被测PB2S在5V可带额定2A，过载约2.7A；这不等于额定3A。 | 可更换电芯、免焊，但盒体重，不再作为默认方案。实测USB-C输出仅5V，使用C口时高压档关闭；双口合计额定能力未核实。测试还显示充电时输出不能保持正常5V，因此不作为UPS。PB2S/PB2SL及批次参数不能混用。 |
| **[微雪 Solar Power Manager (B)](https://www.waveshare.com/product/modules/solar-power-manager-b.htm)** | 先前查到108×71×25.2mm、金属外壳；完整重量待确认 | 内置10000mAh电池、充电管理和5V/3A输出；可用输出Wh未确认。 | 属于开发商城的完整供电产品例子，体积没有比上述轻量成品更适合头戴；保留作备选，不因带太阳能输入而增加太阳能板。 |

国内渠道：[奈特科尔天猫旗舰店](https://nitecore.tmall.com/)、[京东旗舰店](https://nitecore.jd.com/)来自国内官网入口；ISDT保留上述官网及[PB40C2M国内评测/购买跳转](https://chargedb.cn/PB40C2M)作为购买线索，成交价与库存未核实。XTAR、Vapcell和微雪可按品牌型号在国内官方渠道核对。此前淘宝搜索页被浏览工具的站点安全规则拦截，**没有核验具体淘宝店铺、销量或在售价格**。

### 4.3 续航与重量比较

计算式：**续航小时≈5V输出可用Wh÷整机在5V入口的平均W**。以下4/5/6W只是比较情景，不是我们已经测得的整机功耗；手机自行供电，其耗电不包含在眼镜电源预算中。既然使用5V输出能量，就不再重复乘一次电池升压效率；实际线损、截止条件、模式及负载变化仍影响结果。

| 候选 / 计算所用能量 | 平均4W | 平均5W | 平均6W |
|---|---:|---:|---:|
| NB10000 Gen4，常规模式额定34Wh | 约8.5h | 约6.8h | 约5.7h |
| PB40 mini，额定31.2Wh | 约7.8h | 约6.2h | 约5.2h |
| Carbon Battery 6K，额定17.5Wh | 约4.4h | 约3.5h | 约2.9h |
| PB2S＋两颗N40，**假设**28.8Wh×90%=25.9Wh | 约6.5h | 约5.2h | 约4.3h |

各厂家额定能量的测试电流不同，上表用于初筛，不是统一条件实测排名。PB2S行的90%仅是假设；原7000mAh容量预算同样按3.6V与90%计算时是22.7Wh，不应误写为N40组合实测容量。NB10000的36Wh节能档只在相应输出模式和负载允许时另行考虑。

若争取10h，4W平均负载需要至少40Wh的实际输出能量，5W需要50Wh，另外还要留实际损耗余量。34Wh电源要达到10h，平均入口功耗需约不高于3.4W；所以换轻量成品可以改善重量和容量，但不能单凭10000mAh标签承诺10h。

原PB2S＋N40约181–182g，对比NB10000 Gen4约143g，可减约38–39g，标称电芯能量由28.8Wh增至39Wh。与74g相机合计后，原组合约255–256g，新候选约217g；距离300g分别剩约44–45g与83g供其他器件、线束和外壳使用，**均不是整机最终重量**。后脑安装借鉴WOAD的前后配重思路，改善重心而非减少总重。

### 4.4 整包代工入口及交付要求

| 厂家 / 原始链接 | 已查到的能力 | 尚未确认的条件 |
|---|---|---|
| **[深圳沃尔德新能源](https://www.wpbattery.com/dianchipackdingzhi/)** | 官网给出电芯与BMS选型、结构/外壳/接口设计、打样、送样测试及批量交付流程，并说明随样提供规格书与测试报告。 | 是否接本项目一两套完整5V电源、输出升压/充电集成范围、成品重量、开发费、起订量与交期。仅有“支持定制”不能算已答应小单。 |
| **[援通电子](https://www.batteryodm.com/ldc/57.html)** | 页面列出带保护、5V输出、Type-C充放电的电池包定制。 | 写有100组起订，其他位置又列不同数量；小样条件不清。不是当前少量样机的优先入口，不能将宣传报价直接用于预算。 |
| **[PAC Battery 9000mAh / 5V USB电池包](https://www.pacbattery.com/rechargeable-lithium-polymer-battery-pack-9000mah-5v-with-usb-port-for-power-bank.html)** | 提供USB 5V输出电池包例子，尺寸和容量可定制；表中电芯为3.7V、9000mAh。 | 完整重量、USB端额定电流/输出Wh、Type-C接口、起订量和完整充电交付条件未确认。表中电芯侧18A参数不能当成USB输出能力。 |
| **[CM Batteries定制服务](https://cmbatteries.com/custom-battery-packs/)** | 提供电池包设计、组装、保护和测试；部分[产品页](https://cmbatteries.com/project/high-temperature-3-7v-4000mah-21700-battery-pack/)有样品/小批量线索。 | 是否愿接本项目、完整5V稳压及Type-C充电输出、最低数量、费用和交付重量仍需询价，不等于已验证供应商。 |

后续给厂家询价时，交付对象应明确为**可直接插接的完整5V电源包**。询价内容包括：5V/3A连续输出及启动峰值能力、所需5V输出Wh、头带允许尺寸与接口方向、全包重量、保护项目、C对C启动/自动关断行为、充电方式、样品数量、开发费、单价、交期、配套线束和测试报告。电芯内部串并联由厂家按目标设计；我们不限定必须两颗18650，也不接受让我们自行焊接集成的“半成品”。目前没有联系或下单。

### 4.5 WOAD电池证据与其他方向

- **WOAD可借鉴的是安装方式，电池型号仍未知。** [图2a](https://www.nature.com/articles/s41467-025-58085-x/figures/2)展示后脑位置的长条包膜电池并标注12000mAh，正文称电池约80g、眼镜约400g、续航约11h。本轮已查正文、补充材料、审稿回复和仓库，未找到电芯型号、完整电源电路及重量口径。若假设按3.7V计算，12Ah为44.4Wh，除以80g得到555Wh/kg；这是对标注的条件核算，不是已确认电池参数。因此不把“80g、10h+”写成现成采购指标。[论文](https://www.nature.com/articles/s41467-025-58085-x)、[公开仓库](https://github.com/MMCNJUPT/WOAD)
- **[Vapcell P2160B](https://www.vapcelltech.com/h-pd-256.html)**：此前找到的带USB充放电圆柱电源方向，保留厂家入口。使用者约79g、约15.4Wh的[原始测量记录](https://www.reddit.com/r/Ultralight/comments/1huwxgz)仅作线索，不作为额定保证；完整输出能力未补齐，不列为首选。两颗分别供电也不能不考虑负载分配就相加承诺续航。
- **[DFRobot DFR0446 / MP2636](https://www.dfrobot.com/product-1613.html)**：此前研究过的小型充电升压模块。它本身不是完整电源，不能恢复为让用户自行集成的方案；只可供代工方评估内部实现，最终仍须交付完整包。
- **[Amprius SiMaxx SA80初步规格](https://amprius.com/documents/Amprius_Product_Portfolio_0824_website.pdf)**：此前查到高能量密度硅负极电芯方向，但裸电芯之外还需夹持、保护、充电、稳压与封装，小批量成品渠道未确认。保留[可穿戴电池项目实例](https://amprius.com/amprius-to-integrate-safe-cells-into-next-generation-u-s-army-wearable-battery-pack/)作技术线索，不列入本项目直接采购清单，也不能据此推定WOAD使用这种电芯。

当前比较方向仍是：以NB10000 Gen4作为轻量成品基准，PB40 mini比较短厚外形，Carbon Battery 6K比较更轻但能量较少的取舍；若成品形状不合适，再按同一完整电源要求比较OEM。最终选择待整机负载与安装安排确定。

## 五、硬件检查结果与边界

| 检查项 | 本轮结论 |
|---|---|
| 相机与主板 | USB数据接口匹配、ARM64 SDK有支持路径；不另加相机驱动板。候选Splitter和整机连续出帧尚未实测。 |
| IMU | 电平和拟用引脚能对应，不需要通用电平转换板；联合运行未验证。 |
| 无线版本 | 需核实ZERO 3W实物为支持5GHz的版本，不能只凭板名、内存容量或外接双频天线推定。 |
| 供电连接 | 单个Type-C入口的内部成品分电方案尚未闭合；第四节已保留供电要求、成品/OEM候选和估算，电池仍未定型，整机供电余量未实测。 |
| 重量与体积 | 约300g是可接受方向，不是当前实测总重；电源未定，不能冻结其占位。其余安装位置、接头空间、散热及线束固定需实物核对。 |
| 采购完整度 | 部件类别与功能分工基本齐全；IMU和线束的具体商品暂不继续搜索，不能称作已完整验证的下单清单。 |

**阶段结论：保留CS30＋ZERO 3W、IMU的硬件组成。部件用途已明确，暂未发现要求推翻架构的硬性冲突；这不等于整机已经验证无误。下一步硬件讨论集中于连接关系和结构安排，不展开固件，不因尚未装机而继续泛搜更多器件。**

## 六、接入时保留的验证项

- **实现路径：** 已下载并静态检查ARMv8 SDK 4.2.5.0，资料见 `glasses_refs/cs30_radxa/`；尚未在Radxa＋CS30实物运行。当前只记录有支持路径，不指定软件版本组合、采集参数或编码实现。
- **联合工作：** 相机持续出帧、IMU及无线通信需同时测试；单项能工作不代表整机通过。
- **结构与佩戴：** 已有CS30和Radxa官方STP；小模块、接头与线束高度按实物确认，并验证装壳后的散热和无线效果。相机与IMU保持刚性安装关系。

## 七、器件与采购参考（具体商品暂不继续搜索）

| 器件 | 数量 | 型号 | 在哪买 / 怎么搜 |
|---|---:|---|---|
| 深度＋彩色相机 | 1 | Synexens CS30（DFRobot SEN0673） | DFRobot；淘宝搜“Synexens CS30” |
| 主板 | 1 | Radxa ZERO 3W，2GB＋16GB eMMC，已焊排针，另核实双频无线版本 | [ARACE](https://arace.tech/products/radxa-zero-3w)；原SKU RS107-D2E16H1W15仅作候选信息 |
| 散热片 | 1 | Radxa Heatsink 5519A | ARACE 同店 |
| 成品电源及内部分电件 | 待定 | 单Type-C 5V输入，优先5V/3A；NB10000 Gen4、PB40 mini等作候选，详见第四节 | 成品/OEM，不自行制作电池组；购买与代工链接已保留，尚未定型 |
| 相机USB转接板 | 候选1 | 8086 Consultancy USB-C/PWR Splitter，不带圆口座 | [Lectronz](https://lectronz.com/products/usb-c_pwr-splitter)，待整体连接方案确认 |
| USB线 | 待定 | 支持USB2.0数据；接头、长度和数量随分电方案确定 | 成品短线/弯头线，核实可传数据 |
| IMU | 1 | ICM-42688-P成品板；Qwiic方案已查，具体商品暂不定 | [LogicalEdges参考板](https://www.elecrow.com/icm-42688-p-ultra-low-power-imu-breakout.html)，不锁定为必购 |
| IMU连接线 | 1 | 若选Qwiic板，可用Adafruit 4397（150mm） | 随实际模块接口配套 |
| 外接天线 | 1（可选） | Taoglas FXP830.07.0100C | 立创/Mouser |
| 耗材 | 若干 | M2 螺丝 | 淘宝 |

## 主要来源

- [CS30 手册：尺寸、重量、分辨率、功耗](https://dfimg.dfrobot.com/wiki/17502/SEN0673_rgbd-depth-camera_datasheet_V1.0.pdf)；[CS30 视场与测距范围](https://support.tofsensors.com/product/CS30.html)；[CS30 产品与 ARM 开发板供电说明](https://tofsensors.com/products/rgbd-3d-camera)
- [Synexens SDK 4.2.5.0 使用说明](https://support.tofsensors.com/sdk/4.2.5.0/docs/CN/SynexensSDK4_Instructions_for_use_v2.0-CN.pdf)
- [Radxa ZERO 3W 产品简介（SKU、主机口500mA）](https://dl.radxa.com/zero3/docs/hw/3w/radxa_zero_3w_product_brief.pdf)；[版本与无线说明](https://docs.radxa.com/zero/zero3/faq)；[Radxa官方40针接口表](https://docs.radxa.com/zero/zero3/hardware-design/hardware-interface)
- [RK3568系列引脚复用定义](https://github.com/torvalds/linux/blob/master/arch/arm64/boot/dts/rockchip/rk3568-pinctrl.dtsi)；[Radxa I2C4-M0 overlay](https://github.com/radxa-pkg/radxa-overlays/blob/main/arch/arm64/boot/dts/rockchip/overlays/rk3568-i2c4-m0.dts)。Radxa参考配置本地副本：`glasses_refs/cs30_radxa/radxa_zero3_reference.dtsi`。
- [WOAD论文：相机、ARM/FPGA分工与反馈硬件](https://www.nature.com/articles/s41467-025-58085-x)
- [8086 USB-C/PWR Splitter 接线表](https://lectronz.com/products/usb-c_pwr-splitter)
- [ICM-42688-P Qwiic 小板](https://www.elecrow.com/icm-42688-p-ultra-low-power-imu-breakout.html)；[Adafruit 4397](https://www.adafruit.com/product/4397)

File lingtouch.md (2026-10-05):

# 灵触·随行 项目现状（队友版）

更新日期：2026-09-16

这份文档只写已经做出来、测过、定下来的真实情况，供答辩准备和分工参考。答辩用的视觉方案正在重新设计，不在本文范围内；旧 PPT 里的视觉内容不作数。

---

## 1. 项目在做什么

灵触·随行是给视障者用的出行辅助设备：用摄像头看前方环境，把"前方哪里有障碍"转换成白杖手柄上一块可刷新的触觉点阵，用户用手摸就能知道前方障碍的大致布局。白杖本身保留，设备是在白杖之外补充"提前知道前面几米有什么"的信息。

- 参赛项目：中国国际大学生创新大赛。
- 分工：
  - 硬件、PCB、固件由项目负责人负责。
  - 摄像头/感知前端另有一名负责人。
- 触觉模组由外部厂家"无界"提供，模组内部机理和参数以对方（郦铖）的说法为准。

---

## 2. 需求依据：视障者访谈

做过 3 名视障人士的半结构化访谈。和设计直接相关的结论：

- 受访者出行只用高德导航加白杖，不用专门的助盲 App（不知道或不喜欢用）。
- 高德只给路线级信息（往哪走、在哪转弯），不告诉用户前方障碍怎么分布。这正是本项目要补的空缺。
- 受访者大多明确不喜欢把摄像头绑在胸前，主动提出希望做成眼镜形态。
- 受访的几位本身完全不戴眼镜，所以把摄像头集成进墨镜不存在"和原有眼镜冲突"的问题。
- 受访者出行时一手白杖、一手手机。

据此已经拍板：**摄像头形态改为智能眼镜。** 对眼镜的要求：
- 视场要大，最好能看到身体左右两侧。
- 一直开着，不需要人去触发。
- 可充电，单次能用一两个小时。

"过马路时看左右来车"作为已知诉求记录下来，但暂不作为核心：这类紧急情况用声音提示不一定比触觉差。

---

## 3. 触觉阵列（核心硬件）

### 3.1 阵列布局
- 15 个触觉模组，排成横 3 列 × 竖 5 行。
- 每个模组 6 个点，排成 2 行 × 3 列。
- 拼起来共 90 个点，按 **10 行 × 9 列** 使用。

### 3.2 实测几何（2026-09-07 用实物量的）
- 模组内点距 2.5mm，和标准盲文点距相同。
- 点凸起高度 0.5mm。
- 竖直方向：模组紧密相接，点距连续 2.5mm。
- 横向：模组之间有略小于 4mm 的缝，所以横向点距不均匀。这道缝把阵列天然分成**左、中、右三块**，手指一摸就能分出障碍偏哪边。

### 3.3 一个点是怎么升起、怎么保持的（无界提供的机理）
- 每个模组里有 **6 个独立的小线圈**（每个点一个），但只有 **1 根共用的记忆合金丝（SMA）**。
- **记忆合金是锁**：通电发热时锁松开，断电冷却后锁重新夹紧。
- **线圈只负责往上推针**，每个点单独控制。
- **针落下靠弹簧或磁铁**，不靠重力。倒过来拿做过实验，照样工作。

一次刷新分四步，时长写在固件里：

| 阶段 | 时长 | 记忆合金 | 线圈 | 作用 |
|---|---|---|---|---|
| A 解锁 | 10ms | 通电 | 断 | 锁松开 |
| B 推起 | 50ms | 通电 | 要凸起的点通电 | 把针推上去 |
| C 等锁夹紧 | 150ms | 断电 | 继续通电 | 记忆合金冷却，锁把针夹住 |
| D 全断 | 10ms | 断 | 断 | 所有输出关闭 |

- 一次完整刷新约 **220ms**。线圈连续通电 200ms，记忆合金通电 60ms。
- 刷新完所有电都断开，图案靠机械锁保持。
- 因为锁是整个模组共用的，**同一个模组里"部分点坏、部分点好"不可能是记忆合金或供电的问题**，只能是单个点本身的问题。

### 3.4 电气参数
- 线圈电阻：万用表实测约 15Ω 稍多。
- 厂家设计的供电（设计意图，不是过压）：
  - 线圈电源 **VCC 3.3V**，经驱动芯片压降后，线圈上约 2.5V。
  - 记忆合金电源 **VCCS 2.0V**，经驱动芯片压降约 0.9–1.1V 后，记忆合金上约 1.1V。
- 模组封装名 "HC-PM127" 只是借用的封装名，不是真实型号，查不到。

### 3.5 焊接注意
- 按无界的说法，模组引脚约 300°C 快速过一遍。
- 模组装上板之后不能再用热风枪，只能用烙铁点焊。

### 3.6 模组可靠性
- 早期板子上出现过部分点不动的情况。排查结论：模组内部的**逐点锁死机构卡住**，电气正常，外部修不了，已反馈给无界。

---

## 4. 驱动板

### 4.1 驱动架构
ESP32-S3 用三根线（数据、时钟、锁存）把数据推进 **16 片串联的移位寄存器（74HC595）**，每片后面接一片**达林顿驱动芯片（ULN2003 类）**。

- 每片移位寄存器用 7 路输出：6 路给线圈，1 路给记忆合金。16 片共 112 路独立输出。
- 板上有 16 个模组位：
  - 15 个正式使用。
  - 第 16 个是测试位，暂时没有用途。
- **所有输出独立、可以同时驱动，不做轮流扫描。** 原因：一个模组的 6 个点必须在同一次"锁松开"的窗口里一起设好；如果轮流扫描，一帧刷新要拉长到 0.4–0.9 秒，就不实时了。这个方案已经否决。
- **驱动芯片沿用达林顿**，没换成 MOS 管驱动。这是为了在等无界回复期间不改驱动方案、减少变量，并不是已经证明达林顿更好。

### 4.2 电源
- **电池**：两节 18650 串联（2S）。
  - 手上有魔力 P28A 和 P30B 两种电芯，各组了一个 2S 包，配杂牌 2S 保护板。
  - 保护板标称 20A 连续放电、10A 连续充电、25A 启动。
  - 电池内阻和保护板带载时的实际门限还没有可靠资料，待验证。
- **板上三路电源**，互相分开：
  - **线圈电源 VCC 3.3V**：大电流同步降压芯片 MPQ8633B（U49），配大容量固态电容。
  - **记忆合金电源 VCCS 2.0V**：单独一颗小降压芯片（U50）。
  - **ESP32 电源 5V**：升降压芯片 TPS63070（U51）。
- **充电**：USB-C（U53）。
- **峰值电流**：固件允许 90 路线圈同时通电，没有数量限制，所以电源按"全部点同时抬起"来设计，峰值在 15A 量级。
- **大容量储能必须用聚合物或固态电容**，普通电解电容内阻太大，这么大的电流下会造成严重压降。

### 4.3 板子版本历史
- **V1 暴露的问题**（V3 已针对性修改）：
  - 逻辑芯片的电源是从线圈电源经一颗磁珠分出来的，线圈一动作，逻辑电压就跟着塌。
  - 记忆合金电源用的 AMS1117 线性稳压，发热约 2.1W，会热关断。
  - 线圈电源没有本地去耦电容。
  - 90 个点里约 33 个点失效，当时没有办法区分是来料问题还是焊接问题。
  - 模组焊死，坏了没法单独更换。
  - 板子装进手柄时是旋转 180° 装的，软件里要做对应的映射翻转（见第 5 节）。
- **PCB1_4（上一版）**：
  - 模组在这块板上一次都没有成功升起过。
  - 出现过一次原因不明的过应力事件，之后实测多处异常：OE# 对地约 2.3Ω、VCC 对地约 58Ω、U11 发热。
  - 无法证明只坏了一处，已决定**不修，重新打板**。
- **V3（当前）**：
  - 原理图正在重画，最新网表日期 2026-09-12。
  - 2026-09-14～15 导出的 PCB 版本是 6 层板，Gerber 几何检查没有发现网络短路或断路。但这不等于载流、温升和实机已经验证通过。当时还发现电源主通路（电池入口、线圈电源降压输出、USB 充电输入）走线偏细，需要加粗。
  - 流程：画原理图 → 无界协助 → 打板 → 找人贴片焊接（含通路检查）→ 自己装模组。
  - 最慢预估约一个月：备料加打板一周、贴片两周、到手验证一周。**板子预计 11 月到。**

### 4.4 新板装配和验证顺序
1. 先焊所有 595（背面）、驱动芯片（正面）和电源部分。
2. 上电，通过测试接口 J_test，把移位寄存器链末端的输出读回来，验证整条链是通的。
3. 最后再焊模组。
- U49、U53、Q1 是底部焊盘封装，只能热风加锡膏焊，锡丝焊不了。

### 4.5 续航
- 目标：触觉部分单独做到 10 小时以上。
- 现状：
  - 没有实测过续航。
  - 固件没有电池电压采样，也没有低电判断和低电关机。
  - 线圈电源芯片 MPQ8633B 的 MODE 脚经 30.1kΩ 接地，按数据手册是"轻载强制连续、800kHz"模式。这个模式在不刷新的空闲时间里仍有明显损耗，对续航不利；改一颗电阻就能切到轻载省电模式，还没决定。
  - 记忆合金的工作电流还没量过。
- 待定：低电时关哪几路电源；线圈电源和记忆合金电源的上电、关断顺序；记忆合金电源要不要和线圈电源合并。

---

## 5. 固件与通信

当前固件版本 **V2.8**（仓库 `firmware/braille_15module_prod/`），用 Arduino IDE 选 ESP32-S3 Dev Module 烧录。

### 5.1 引脚
| 信号 | GPIO |
|---|---|
| 数据 SER / 时钟 SRCLK / 锁存 RCLK | 11 / 12 / 10 |
| 输出使能 OE# / 清零 SRCLR# | 9 / 8 |
| 按键 | 6 |

### 5.2 蓝牙协议
- 服务 UUID `FFE0`。
- **写入特征 `FFE1`**：每次写 15 个字节，一个字节对应一个模组，低 6 位是该模组 6 个点的凸起/平。
- **通知特征 `FFE3`**，事件类型：
  - `0x01` 刷新完成
  - `0x02` 模式切换
  - `0x03` 电池（只定义了编号，没有实现采样）
  - `0x04` 按键请求
- 驱动层每个字节的第 6 位控制该模组的记忆合金，由固件内部生成，手机不用管。

### 5.3 刷新行为
- 每收到一帧，15 个模组**全部刷新一遍**，不做变化检测，约 220ms。
- 刷新途中收到新的一帧，会**立刻中止**当前刷新、关闭输出，改刷新的一帧。
- 刷完通过 `FFE3` 发"刷新完成"。
- 断连后自动重新广播。
- 固件里有两个模式编号：快速避障、局部放大。按键目前只发出"按键请求"事件。

### 5.4 电脑端实验程序的节奏
- 默认约 1 秒发一帧。
- 等收到"刷新完成"再发下一帧；0.8 秒没收到算失败，连续 3 次失败自动暂停。

### 5.5 映射方向
板子是旋转 180° 装进手柄的，所以数据和实际点位之间有一层翻转映射。仓库里两个浏览器调试工具的映射不同：
- `ble_mobile_controller.html` 用 ROT180 映射，对应当前装配方向。
- `ble_testbench.html` 保留旧的 PROD 映射。

用错工具，点位会整个反过来。

---

## 6. 视觉（当前实验原型）

**这是现在真实跑通的原型链路，不是最终的眼镜方案。** 代码在仓库 `visionss/`。

### 6.1 链路
1. 手机（华为 Mate 50 Pro 主摄）挂在胸前 1.40m 高度拍照，上传到电脑。
2. 电脑用 **Depth Anything V2** 米制深度模型（metric hypersim vitl 权重）算出每个像素的距离。
3. 把深度图还原成三维点，在画面底部 25% 找地面并拟合出地面平面。
4. 用"真实相机高度 ÷ 拟合出的相机高度"做尺度校正（这个模型在真实照片上有系统性的尺度偏差）。
5. 保留离地 0.10–1.80m 的点，投影到俯视图，生成 10×9 占据栅格。
6. 转成 15 字节，经蓝牙发给点阵。

### 6.2 栅格的真实几何
- 前方 1 米以内不编码，交给白杖。
- 1 米之后每格 40cm × 40cm：10 行覆盖前方 1.0–5.0m，9 列覆盖左右各 1.8m。
- 输出时行序从远到近，发送前做左右镜像（配合穿戴方向）。
- **注意**：旧路演 PPT 里写过 ±2.0m、0.45m、0.5–5.0m，这些数字不对，已作废，以上面为准。

### 6.3 标定与实测精度
- 相机焦距标定 fx = 3260 像素：用 2.0m 外、宽 0.90m 的门扇测得，和手机主摄理论值偏差约 6%。
- **黑布地面**测试集，椅子距离估计误差：

| 真实距离 | 估计距离 | 误差 |
|---|---|---|
| 2m | 1.66m | −17.0% |
| 3m | 2.58m | −14.0% |
| 4m | 3.50m | −12.5% |
| 5m | 4.09m | −18.2% |

- **换成浅色地面**后，3 米处的椅子误差降到 **−2.1%**。
- 结论：误差主要来自深色、反光地面，让模型近距离的尺度判断失准，不是算法本身的问题。

### 6.4 已知限制（实验得出）
- **障碍物至少要约 0.5m 宽**。气球这类小目标产生的点数比判定门槛低约 3 倍，怎么调参数都检测不到。
- **地面必须浅色、不反光**，而且画面最下方（相机脚下那一段）也不能有深色材质。
- **判断一格有没有障碍要按"填充比例"**，不能按点数多少排序。离得越近点越密（点数和距离平方成反比），按点数排序会被近处地面垄断。
- 输出时左右各多扩一列，方便手指找到。

### 6.5 其他
- 手机浏览器拍摄只能拿到横向 4096×3072 画面，拿不到竖屏，由电脑端旋转。
- 仓库 `vision/` 是更早的图像平面方案，保留作备用，当前不用。

---

## 7. 手机 App

代码在 `app/`，前端 uni-app（Vue），后端 Node.js + Express。**目前是界面原型，多数设备功能是模拟的。**

- **页面**：首页、步行导航、地图、设备（蓝牙连接与点阵控制）、设备诊断。
- **地图**：前端配置的是高德，后端接口用的是百度，两边不一致。所有地图 Key 都是占位值，不能直接调用。
- **语音命令**：后端是规则匹配解析，大模型解析只预留了接口，没有接入。
- **设备状态**：电量固定从 78% 开始显示，连接和断开是模拟的。
- **视觉帧转发**：后端有接收视觉帧（HTTP）和推送给手机（WebSocket）的接口。但当前视觉实验程序是独立运行的，不经过这个后端。

---

## 8. 答辩相关

### 8.1 校内预答辩意见（2026-09-16）
老师提出：用户摸到"左侧 2 米有障碍"，很可能根本没有"2 米"的概念，这需要用户有很强的空间感。

项目负责人的立场：用户不需要准确知道 2 米在哪，知道大概近处有障碍、哪边有障碍就够了。PPT 里是否去掉具体距离、改用远近说法，还没定。

### 8.2 现有材料之间对不上的地方
来自 2026-09-16 的 140 题问辩手册，PPT、商业计划书、答辩稿三份材料在这些地方说法不一致，统一之前答辩时不要随口引用：

| 事项 | 材料 A | 材料 B |
|---|---|---|
| 系统架构 | PPT 第 16 页：眼镜 → 手机 → 点阵 | 计划书 2.1：肩部摄像头 → 树莓派 → 手机 → ESP32-S3 |
| 蓝牙帧长 | PPT：15 字节 | 计划书：18 字节（15 字节点阵 + 1 字节模式 + 2 字节序号） |
| 时间指标 | PPT：约 1Hz、220ms 全刷新、响应小于 100ms | 计划书：500ms 端到端、2–4Hz |
| 距离映射 | PPT：40cm 等距 | 计划书：近密远疏 |
| 高度范围 | 技术页：0.10–1.80m | 功能页：2m |
| 语音 | PPT 第 14 页：大模型已具备 | 计划书 2.1.5：当前规则匹配，大模型是后续方向 |

对照真实情况：
- 固件实际收的是 15 字节。
- 全量刷新约 220ms，实验程序约 1 秒一帧。
- 栅格是 40cm 等距，高度过滤 0.10–1.80m。
- 语音目前是规则匹配。

---

## 9. 资料在哪

| 内容 | 位置 |
|---|---|
| 全部代码（固件、视觉、App） | GitHub 仓库 `zxlzzz/LingTouchCompanion` |
| 固件 | `firmware/braille_15module_prod/`（V2.8） |
| 视觉实验程序 | `visionss/`，入口 `python visionss/phone_server.py` |
| 视觉标定与测距验证记录 | 仓库根目录 `TOPDOWN_VALIDATION.md` |
| 蓝牙调试网页 | `ble_mobile_controller.html`（当前装配方向）、`ble_testbench.html`（旧映射） |
| 手机 App | `app/frontend/`（HBuilderX 打开）、`app/backend/` |
| 原理图、网表、BOM | 立创 EDA 工程 |
| 模组内部问题 | 无界（郦铖） |

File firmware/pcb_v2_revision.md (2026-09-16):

# 灵触·随行 — PCB V2 改版报告

> 文档版本：**v3**（板子仍是 PCB V2；v3 指本报告的第三版）
> 建立日期：2026-08-10　｜　本版日期：2026-08-13
> 前版板：PCB1 / 181.93 × 36.26 mm / 4 层 / 2026-08-01 netlist / 2026-08-13 坐标文件
> 本版主要变更：电源架构按 **12V 电池母线** 重写；可测性砍到无示波器可执行的范围；充电移出本版；**新增 §11 增删清单**

---

## 0. 本文档的用途

记录 **V1 板暴露的问题** 与 **V2 必须落实的改动**，供画板时逐条勾选。

原则：**V2 的第一目标不是加功能，而是消除「不可测、不可换、不可验证」三个结构性缺陷。**

阅读约定：
- **[必改]** — 已确认成因，V2 必须解决
- **[待定]** — 依赖无界现场调研结果，暂不定稿
- **[预留]** — 零成本或近零成本的可改性设计

**画板时只看 §11。** §1–§10 是理由，§11 是动作。

---

## 1. V1 问题清单

### 1.1 已确认成因

| # | 问题 | 成因 | 证据 |
|---|---|---|---|
| P1 | VCCS 轨在刷新期间塌陷 | U50 (AMS1117, SOT-223) 输入 5V 输出 2.0V，压差 3V；step=8 时约 0.7A → 功耗 2.1W；θJA 60–100°C/W → 结温升 126–210°C，撞 150°C 热关断 | 计算 + 固件作者自注 "step>12 时可能超 AMS1117 1A 极限" |
| P2 | 逻辑电源随线圈脉冲波动 | netlist：`VCC`(线圈) → FB1 磁珠 → `VCC_LOGIC`(15× 595 pin16)。磁珠只滤高频不隔直流，线圈一通电逻辑轨跟着掉 | Netlist_PCB1_2026-08-01 |
| P3 | 主电源路径串了 0603 磁珠 | FB1 (L0603) 额定 0.5–2A、DCR 0.05–0.5Ω，下游挂 15 个模块线圈 | 同上 |
| P4 | 电源模组用排针插接 | J_BOOST / J_BOOST_IN / J_BUCK / J_BUCK_IN 四组 2.54 排针，插接式接触电阻在振动/按压/行走时变化 | 用户实测现象 |
| P5 | 无电源开关 | 设计遗漏，目前靠拔插电池 | — |
| P6 | 无充电接口 | **本版不处理**，见 §6 | — |
| P7 | 模块焊死不可换 | 6.5mm 水平 / 11mm 垂直中心距、12 脚通孔，拆一个必伤邻位与焊盘 | 坐标文件确认：U31–U45，X 间距 6.5mm、Y 间距 11mm |
| P8 | 焊接前无法验证模块好坏 | 无测试工装 | 90 点中约 33 点失效，无法区分来料 vs 焊接 |
| P9 | 无任何回读 / 自检能力 | 595 链单向，U15.9 (QH′) 悬空 | netlist：U15.9 无连接 |
| P10 | 物理装配方向与逻辑方向相反 | 板在手柄内 180° 旋转 → `MODULE_ROT180` 需在三处同步（vision/frame_converter.py、visionss/frame_converter.py、ble_testbench.html），叠加 posToChain 倒序 + 两次 bit remap。**且元件物理位置一并被翻**——SW1 图纸在阵列 −X 侧，实装落在拇指下方 | 已实现但脆弱 |
| P11 | VCC（线圈轨）零本地去耦 | C1–C15 全挂在 FB1 后的 VCC_LOGIC 上，C16–C30 挂 VCCS，VCC 一颗没有 | netlist 网络归属 |

### 1.2 高度怀疑但未证实

| # | 问题 | 依据 | 验证路径 |
|---|---|---|---|
| S1 | 自动布线导致地平面破碎、电源走线过细、去耦被放远 | V1 用嘉立创自动布线；脉冲负载下地弹与压降会放大 P1/P2 | V2 直接手工布电源和地 |
| S2 | 大量死点源于**焊接热损伤**而非来料次品 | SMA 相变温度远低于焊接 250–350°C；热可致记忆形状丧失、锁定机构软化变形卡死；能解释"同模块部分点坏部分点好" | 空间分布分析不可行（靠前编号为旧拆机件、靠后为新件，样本不同质）；替代切分 = 新件 vs 旧件失效率对比；根本验证依赖无界的焊接工艺参数 |
| S3 | VCCS/VCC 峰值电流预算不明 | 无电流采样手段，step 上限只能估算 | **无示波器，板上测不到**；只能向无界索取单点峰值电流规格 |

### 1.3 已排除、不再讨论

- 供电轨压降梯度 / 批次电流下垂
- bit 序映射错误
- VCCS 过压（**2.0V 是设计值，ULN 达林顿压降约 0.9V，SMA 实际得 1.1–1.2V，正确**）
- 线圈欠驱动（3.6V 无变化）
- 时序不足（phaseA/B 扫到 300/200、phaseC 到 500 无效）
- SMA 未解锁（每模块均验证解锁正常）
- 焊点问题（线圈电阻一致、SMA 电阻一致）

**结论：死点为模块内部锁定机构卡死/变形，外部不可恢复。** V2 不做任何软件补偿设计，该问题随模块连接方式一并解决。

---

## 2. V2 电源架构 [必改]

### 2.1 前提修正

**电池是 12V DC 输出（带 DC 公母头，可充可放）**，不是单节锂电。这推翻了 v1/v2 报告中"取消 5V 中间级"的写法——那条结论建立在"电池 3.7–4.2V、5V 需升压"的错误前提上。

12V 母线下，**全部轨均为降压，没有任何升压级**，P1 的成因（LDO 压差 3V 发热）与 5V 轨本身无关。

### 2.2 拓扑

```
12V 电池（DC 公母头，自带充放电）
  │
  └─ [SW2 自锁开关] ──→ [现成 DC-DC 模组 U51，VIN 12V]
                          │
                          ├─→ 5V / 3A ─┬─→ ESP32 DevKit 5V 脚（板载 LDO 兜底）
                          │            ├─→ [同步 Buck U52] VCCS 2.0V  ← SMA，脉冲
                          │            └─→ [同步 Buck U53] VCC  3.2V  ← 线圈，脉冲
                          │
                          └─ 3V3 / 3A ──→ VCC_LOGIC  ← 15× 595 逻辑
```

**为什么 ESP32 走 5V 脚而不是 3V3 脚：** 3V3 脚旁路板载 LDO 直连芯片，会与 USB 供电对顶（§6 要求装配后 USB 可插），且失去对 BLE 发射 300–500mA 台阶的缓冲。5V 脚保留板载 LDO，这两个问题都不存在。

**为什么两颗 Buck 输入取 5V 而不是 12V：** 压差小、电感小、效率高；U51 的 5V/3A 有余量（ESP32 峰值约 0.5A + 两轨折算输入约 1.2A ≈ 1.7A）。
> 需确认 U51 标称 3A 是持续还是峰值。若为峰值，改从 12V 直接给两颗 Buck 供电。

### 2.3 逐轨要求

| 轨 | 电压 | 来源 | 裕量 | 储能 |
|---|---|---|---|---|
| VCCS | 2.0V | **同步 Buck（禁用 AMS1117）** | 峰值按 step=12 约 1.2A → **选 3A 级** | 470–1000µF 低 ESR + 每模块就近 100nF（C16–C30 保留） |
| VCC | 3.2V | 同步 Buck | 3A 起（待线圈电阻实测确认） | 470–1000µF + **新增 15× 100nF 就近去耦（V1 为零，见 P11）** |
| VCC_LOGIC | 3.3V | U51 的 3V3 输出，**独立** | 几十 mA | 每颗 595 就近 100nF（C1–C15 保留，改挂新源） |
| ESP32 | 5V→板载3.3V | U51 的 5V 输出 | — | 模组自带 + 100µF |

**硬性约束：**
1. `VCC_LOGIC` **绝不再从 `VCC` 经磁珠分出**，FB1 删除。
2. 主电源路径**不串磁珠**。
3. 四轨回流在**电池负极单点汇合**，不在板中间共地路径。
4. VCCS 主干走线 ≥ 2mm 或直接铺铜。
5. **现成模组一律焊死**，通孔焊盘直插，禁止排针插接（P4 的直接成因）。

### 2.4 关于"自己画 vs 用成品"

- **U51（12V→5V/3V3）用手头现成模组**，板上画一排 2.54 通孔焊盘让它引脚直插焊死。不飞线。前提是先量准引脚间距与排布，画进封装库。
- **U52/U53（VCCS/VCC）自己画**，但**照数据手册参考设计原样抄**，元件值不做任何"优化"；立创商城对常用型号有验证过的参考电路。风险来自芯片厂而非本项目。

**不做"面积预留"。** 不确定性用器件裕量吸收，不用板上空地吸收。

### 2.5 备忘：电容电感的作用

- **电容 = 本地储能**。线圈瞬间抽 1A，稳压器环路响应需几 µs–几十 µs，这段时间由电容供给。容量够大、位置够近，轨就不塌。
- **电感 = 开关电源必需件**，非可选，值照手册取。
- **堆料不是线性变好**：电容超量后收益趋零，还会带来上电浪涌与环路不稳。稳定来自结构正确（轨分离、地平面完整、去耦就近、稳压器选型对）。

---

## 3. 可测性 [必改，已按"无示波器"砍定]

前提变更：**本项目无示波器，且不为此采购。** 所有依赖动态波形的检查项（电流采样电阻位、分散裸铜探针盘、ULN 输出测试点）**全部删除**——加了也读不出来。

保留四条，全部是万用表或固件能直接用的：

| # | 实物 | 数量 | 干什么 |
|---|---|---|---|
| T1 | U15.9 (QH′) → ESP32 空 GPIO | **1 根走线** | 上电发已知数据再读回，验证 15 颗 595 全焊好、链未断、位序正确 |
| T2 | 板边 2.54 排针 J_TEST | **6P × 1** | VCCS / VCC / VCC_LOGIC / 5V / GND / GND，万用表夹静态电压，也可挂鳄鱼夹 |
| T3 | 电池分压 R6/R7 → ADC | **2× 0603** | 固件持续记录电池电压，串口有时间轴可对 |
| T4 | NTC 热敏 RT1 + R8 → ADC | **2 件** | 贴 ULN 群中央。访谈把"偶尔触发"变成"持续刷新"，ULN 与稳压器从瞬时发热变连续发热，热限制目前空白（§5.4-3 仍挂着问无界）。**这是唯一一个没有仪器也能自己拿到新数据的检查项**，跑一次连续刷新就能测出来 |

> 目标：下一版若仍不稳，**半小时内定位**，而不是排查数周。

**模块焊前预检**不在主板上，见 §5.5。

---

## 4. 布线 [必改]

| 项 | 要求 |
|---|---|
| 布线方式 | **电源与地手工布**。信号可自动布线，但布完人工复查 SPI 时钟、SRCLR#、OE# |
| 层叠 | L1 信号 / **L2 完整 GND 平面（不得切割）** / L3 电源平面（VCC / VCCS / VCC_LOGIC 分区） / L4 信号 |
| 电源线宽 | VCCS、VCC 主干 ≥ 2mm 或铺铜区 |
| 去耦 | 电容紧贴芯片电源脚，到地平面过孔尽可能短 |
| 分区 | **驱动芯片跟着阵列走、电源集中在另一端，这个格局是对的，不动。** 不做任何"左右均衡分布"式的调整——那只会拉长信号线 |
| 方向 | **按最终装配方向布局，取消物理 180° 旋转**。SW1 直接画在拇指位置，不再靠脑内换算 |

**取消 180° 旋转的收益：** 消掉 `MODULE_ROT180` 三处同步、消掉 `posToChain` 倒序、消掉两次 bit remap 中至少一次，并消掉"图纸上是左、手上是右"的元件位置换算。纯布局问题，零成本。

---

## 5. 模块连接方式 [待定 — 唯一悬空项]

**V2 唯一无法在这边定稿的部分，其余章节均可先行画板。**

### 5.1 已知事实
- 模块 12 脚双排直插，间距实测约 **1.25mm**（需重新精确复测）
- **引脚不完全对齐**，部分引脚间距有偏差
- **针本身较软**
- 杜邦转 1.25 端子勉强可插，接触效果差

### 5.2 判断
引脚软 + 位置有偏差 → 该模块很可能本就是设计为焊接使用的。若设计为插接，引脚会做硬、对齐精度高、带防呆。

### 5.3 候选方案

| 方案 | 优点 | 风险 | 状态 |
|---|---|---|---|
| A. 1.25mm 排母 | 标准件、便宜、可换 | 簧片小、容差有限，软针可能插弯 | 值得用报废模块试插，成本几元 |
| B. Pogo pin 压接 | 容忍位置偏差、不插弯软针、完全可插拔 | 需机械压紧结构，窄手柄内难做 | 手柄内否决；**但工装上完全可行，见 §5.5** |
| C. 焊接 + 焊前测试工装 | 现实可行；解决 80% 痛点（怕的不是坏了不能换，是焊完才发现坏） | 单模块仍不可换 | **保底方案** |
| D. 主板/子板分体 | 隔离贵且难焊的部分，报废范围可控 | 切口必须在 **SPI 层**（子板含 15 模块 + 15×595 + 15×ULN，接口收敛到约 9–10 根）；切在模块引脚层需 105 根信号，不可行 | 视 A/B/C 结果决定 |

> 方案 D 的子板**不是"可换模块"，是"可换显示总成"**。若采用，连接器的 VCCS 与 GND 必须各占 3–4 针并联。
> 每模块做独立小板菊花链**不推荐**：15 块小板各自的 Z 向误差会破坏阵列共面度，指腹读取对平面度极敏感。

### 5.4 待现场确认（无界）
1. 模块物理装配方式：定位、共面度、面板开孔尺寸、模块与面板间隙
2. **焊接工艺参数：温度曲线、单点停留时间上限、散热措施** ← 直接决定 S2 与 V2 是否必须弃焊
3. 官方驱动时序：SMA 开启窗口、线圈保持时长、最小间隔、**连续工作热限制**
4. **电流规格：单点峰值、平均、同时可驱动上限** ← 电源预算的地基，且无示波器时只能靠此
5. 是否存在带连接器/座子的模块版本
6. 是否使用分组复用降低驱动芯片数
7. 锁定机构卡死的成因与预防、进料检测方式
8. 模块高度一致性公差

> 完整原理图大概率要不到，也不需要。改问"应用支持 / 参考设计如何处理 XX 问题"，成功率高得多。带上失效模块实物与精确失效档案前往。

### 5.5 焊前预检工装（排在无界调研之后）

**形态：** 独立小板，不上手杖、不进壳，台面夹具。
- 12 个 pogo pin 按模块引脚阵列排布，上方翻盖压板（合页 + 蝶形螺丝）
- 板上焊 1× 595 + 1× ULN + 一个 2.54 排针接口
- 排针接出 SER/SRCLK/RCLK/OE/SRCLR/VCC/VCCS/GND，**直接接主板的 ESP32**，不另配单片机
- 固件不用改，`set 1 3F` / `hold 1 XX` 现成可用

**流程：** 模块放入 → 压下压板 → 串口全点凸起 → **手摸哪几点没起来** → 记录 → 换下一颗。约 30 秒/颗。

**局限：** 无电学回读，只能手摸。SMA 与线圈通断可用万用表测，但"点起不起得来"是机械问题，电阻正常也可能卡死——正是那 33 个死点的形态。此工装价值是筛选，不是自动测试。

**pogo 选型：** 模块软针且位置有偏差，顶针须选**杯型/皇冠型带凹坑**头，套住针头而非顶在针侧面。

**是否做，取决于无界给出的连接方式。** 若最终弃焊，工装作废。
**现在唯一要做的动作：在 V2 板框旁预留一块拼板区位置**（邮票孔/V 割），画不画到时候再定。多花的成本仅为那点面积。

---

## 6. 接口与机械 [必改]

| 项 | 要求 |
|---|---|
| 电源开关 SW2 | 位置在**电池正极之后、U51 之前**；**自锁式**（拨动或按钮，非轻触）；额定 ≥1A；手柄上可盲操作（凸起、有段落感）；**形状/位置必须与 SCAN 键明显区分**；建议凹陷式或加护圈防误触 |
| 电源输入 | **DC 插座**（配电池的 DC 公母头），替代 V1 的 PH2.0 接口 CN1 |
| 充电 | **本版不做。** 电池组自带 DC 公母头可充放电，整组取出外充。板上不留充电电路与开孔 |
| 电池保护 | 确认 12V 电池组自带保护 |
| 调试口 | **装配状态下 USB 口可插**，否则每次改固件都要拆机 |
| 复位/BOOT | 装壳后仍可按到（开孔或引出） |
| 电池仓 | 可开、可换，不得用环氧泥封死。体积已确认可容纳；必要时壳体改扁哑铃型 |
| 机械 | 安装孔/定位柱、按键高度与壳体开孔、USB/开关位置 —— 全部在画板阶段一次定完 |

---

## 7. 用户访谈对硬件的影响

两次访谈（2026-08-10 n=1；第二位半盲受访者）中**真正落到板子上的只有两条**：

1. **实时反馈需求 → 持续刷新** [必改的热预算]
   即便延迟 1s 可接受，"持续刷新"与"偶尔触发"对电源是两种负载。ULN2803A 与稳压器的散热从**瞬时变连续**，热预算必须重做。VCCS 那颗 Buck 的裕量因此更不能省。**→ 这是 T4（NTC）存在的理由。**

2. **保守告警策略 → 同时凸起点数变少**
   电流均值下降，但**电流裕量仍按最坏情况（全阵列凸起）计算**，不得据此缩小。

**明确否决：板上不做音频通路**（无 codec / 功放 / I2S / 喇叭）。用户已是"一手手机、一手手杖、戴半边耳机"，语音必然从手机出；"偏好本地运行"指不上云，手机端即满足。板上加音频等于重复一套硬件，且与两位受访者一致强调的"简化"相悖。

**本版不做的（无 PCB 影响，转视觉/语音/壳体）：** 负障碍（井盖凹陷）检测、台阶提示、眼镜摄像头、伸缩杖、扁平哑铃握把、语音导航系统。

---

## 8. 本版明确不做的事

记录在案，避免下次重新讨论：

| 项 | 决定 | 理由 |
|---|---|---|
| 第 16 颗模块（状态指示） | **不做** | 位置未定，用途未定。位置需实际握持行走后才能定 |
| 振动马达 | **不做** | 同上，与第 16 模块是同一决策 |
| 第二颗辅助按键 | **仅留焊盘，可不贴片** | 功能未定，但按键是事后加不上去的东西 |
| 板上充电电路 | **不做** | 电池自带 DC 充放电 |
| 电流采样电阻位 | **不做** | 无示波器，读不出脉冲峰值；万用表串测只得平均值，无意义 |
| ULN 输出测试点（105 个） | **不做** | T1 自检已覆盖 595→ULN 链路；ULN 之后只能靠模块预检 |
| 板上音频 | **不做** | 见 §7 |

---

## 9. 待补数据

| 数据 | 用途 | 来源 |
|---|---|---|
| 单个线圈实测电阻 | 计算 VCC 轨电流 | 万用表（手上有） |
| 单个 SMA 实测电阻 | 计算 VCCS 轨电流 | 同上 |
| U51 模组引脚间距/排布 | 画通孔焊盘封装 | 游标卡尺 |
| U51 的 5V/3A 是持续还是峰值 | 决定两颗 Buck 输入取 5V 还是 12V | 模组规格书 |
| 模块引脚精确间距 / 两排间距 / 长度 / 直径 | 连接方案选型、pogo 工装 | 游标卡尺 |
| **单点峰值电流规格** | 电源预算（无示波器时的唯一来源） | 无界 |
| **连续工作热限制** | 持续刷新可行性 | 无界（或用 T4 自测） |

---

## 10. 遗留决策

- V1 那两块降压/升压模组是否还在手上？若在，刷新瞬间用万用表量 VCCS，可判断"模组不行"还是"接插不行"——这是"自绘 Buck vs 焊死成品模组"的分水岭
- V2 是继续插 DevKit 还是焊 WROOM 模组？（焊模组则 5V 轨与板载 LDO 一并消失，需自加 USB-UART 与自动下载电路，§6 调试口条目要重算）
- 第二颗按键最终是否贴片、放哪根手指下

---

# 11. 增删清单（相对现有 PCB1）

> **约定：** 删除器件即自然删除其相关网络；新增器件即自然新增其相关网络。只有**不由器件增删自然产生的连线**才在 §11.3 单独列出。

## 11.1 删除

| 位号 | 器件 | 封装 | 删除原因 |
|---|---|---|---|
| U50 | AMS1117-ADJ | SOT-223-3 | P1：压差 3V 热关断。VCCS 改同步 Buck |
| R4 | 620Ω | 0603 | U50 的 ADJ 分压，随 U50 一并删 |
| R5 | 1kΩ | 0603 | 同上 |
| C_LDO_IN | 100nF | 0603 | U50 输入去耦，随 U50 删 |
| C_LDO_OUT1 | 100µF | CAP-SMD_BD6.3 | U50 输出储能，由新 Buck 的储能取代 |
| C_LDO_OUT2 | 100nF | 0603 | 同上 |
| FB1 | GZ1608D601TF 磁珠 | 0603 | P2/P3：VCC_LOGIC 改独立取自 U51 的 3V3 |
| J_BOOST | 2P 排针 | HDR-TH_2P | 取消升压级（12V 母线下无需升压） |
| J_BOOST_IN | 2P 排针 | HDR-TH_2P | 同上 |
| J_BUCK | 2P 排针 | HDR-TH_2P | P4：改焊死通孔焊盘 |
| J_BUCK_IN | 2P 排针 | HDR-TH_2P | 同上 |
| J_TP_BAT | 2P 排针 | HDR-TH_2P | 由 J_TEST 统一取代 |
| J_TP_OUT | 2P 排针 | HDR-TH_2P | 同上 |
| CN1 | B2B-PH-K-S | CONN-TH_B2B-PH-K-S | 电池改 12V DC 公母头，换 DC 插座 |

**删除后自然消失的网络：** `5V`（重建于 U51，见下）、`VBAT`、`VBAT_P`、`$1N1352`（U50 ADJ 分压中点）。

## 11.2 新增

| 位号 | 器件 | 说明 |
|---|---|---|
| J_PWR | DC 电源插座 | 配 12V 电池的 DC 公头。规格待量（推测 DC-005 / 5.5×2.1，需实测） |
| SW2 | 自锁电源开关 | 额定 ≥1A，串在 J_PWR 正极与 U51 之间。盲操作可辨，与 SCAN 键形状/位置明确区分 |
| U51 | 现成 DC-DC 模组 | VIN 12V → 5V/3A + 3V3/3A。**画 2.54 通孔焊盘排，引脚直插焊死，不装排针、不飞线**。封装需按实测引脚间距自建 |
| U52 | 同步 Buck IC | 5V → VCCS 2.0V，3A 级。周边（电感、输入输出电容、反馈分压）**照数据手册参考设计原样抄**，不逐一预编号 |
| U53 | 同步 Buck IC | 5V → VCC 3.2V，3A 起。同上 |
| C_BULK_VCCS | 470–1000µF 低 ESR | VCCS 轨储能 |
| C_BULK_VCC | 470–1000µF 低 ESR | VCC 轨储能 |
| C31–C45 | 100nF × 15 | **VCC 轨本地去耦，每模块就近一颗**。修 P11（V1 此轨零去耦） |
| C_ESP | 100µF | ESP32 5V 轨储能 |
| （空位） | 0805/1206 空电容焊盘 | 每轨 2–3 个，不贴片 |
| J_TEST | 2.54 排针 6P | VCCS / VCC / VCC_LOGIC / 5V / GND / GND，板边 |
| R6, R7 | 0603 分压电阻 | 12V → ESP32 ADC。比值按 ADC 量程定（约 100k / 22k） |
| RT1 | NTC 热敏电阻 | 贴 ULN 群（U16–U30）中央 |
| R8 | 0603 | RT1 的分压搭档 |
| SW3 | 6×6 轻触 **仅留焊盘** | 第二颗按键，功能未定。**可不贴片**，但焊盘与 GPIO 走线必须画 |

**保留不动：** U1–U15（595）、U16–U30（ULN2803A）、U31–U45（模块）、C1–C15（595 去耦）、C16–C30（VCCS 去耦）、SW1（位置改，见 §11.4）、J_ESP_L / J_ESP_R。

## 11.3 需要额外拉的线（不由器件增删自然产生）

| # | 连线 | 说明 |
|---|---|---|
| W1 | **U15.9 (QH′) → ESP32 空 GPIO** | 595 链自检（T1）。V1 中 U15.9 悬空。GPIO 号待固件侧确认，避开 11/12/10/9/8/6 |
| W2 | **`VCC_LOGIC` 改源：U1–U15 的 pin16 与 C1–C15，从 FB1 后端改挂 U51 的 3V3 输出** | 修 P2。器件本身不变，只换上游。**这是本清单里最关键的一条改线** |
| W3 | **R6/R7 分压中点 → ESP32 ADC 脚** | 电池电压监测（T3） |
| W4 | **RT1/R8 分压中点 → ESP32 另一路 ADC 脚** | ULN 群温度监测（T4） |
| W5 | **SW3 一端 → ESP32 空 GPIO，另一端 → GND** | 第二颗按键预留，即使不贴片也要画 |
| W6 | **U52 / U53 的输入端接 U51 的 5V 输出**（而非 12V） | 见 §2.2 注；若 U51 的 3A 为峰值标称，改接 12V |
| W7 | **四轨（VCCS / VCC / VCC_LOGIC / 5V）的 GND 回流各走独立路径，在 J_PWR 负极单点汇合** | 布线约束，非网表连线。网表上仍是同一个 GND 网络，但铜箔路径必须分开 |

## 11.4 位置/布局改动（不涉及增删）

| 项 | 改动 |
|---|---|
| 全板方向 | **按最终装配方向布局**，取消物理 180° 旋转。消掉 `MODULE_ROT180`（三处代码）与 `posToChain` 倒序 |
| SW1 | 直接画在**拇指位置**（实装后拇指上方）。V1 图纸坐标 (−71.4, 51.6) 是旋转前的表述，V2 不再需要换算 |
| 阵列/驱动/电源分区 | **不动**。驱动跟阵列、电源集中在另一端，格局正确 |
| 板框 | 旁侧预留一块**工装拼板区**（邮票孔 / V 割），是否画到无界调研后再定 |

## 11.5 净变化统计

- **删除：** 14 个位号（1 LDO + 2 电阻 + 3 电容 + 1 磁珠 + 6 排针 + 1 电池座）
- **新增：** 约 20 个位号 + 两颗 Buck 的周边件（数量随选型定）
- **额外改线：** 7 条（W1–W7），其中 W2 是修 P2 的核心
- **可测性总增量：** 1 根走线 + 1 排 6 针 + 4 个 0603/热敏 —— 不影响布局

---

## 12. V2 勾选清单

### 电源
- [ ] 删 U50 / R4 / R5 / C_LDO_IN / C_LDO_OUT1 / C_LDO_OUT2
- [ ] 删 FB1 磁珠
- [ ] 删 J_BOOST / J_BOOST_IN / J_BUCK / J_BUCK_IN
- [ ] 删 CN1，改 J_PWR（DC 插座）
- [ ] 加 SW2 自锁电源开关（12V 正极后、U51 前）
- [ ] 加 U51 现成 DC-DC 模组，**通孔直插焊死**
- [ ] 加 U52（VCCS 2.0V 同步 Buck，3A 级）
- [ ] 加 U53（VCC 3.2V 同步 Buck，3A 起）
- [ ] **W2：VCC_LOGIC 改挂 U51 的 3V3**
- [ ] 加 C_BULK_VCCS / C_BULK_VCC（470–1000µF 低 ESR）
- [ ] 加 C31–C45（VCC 轨本地去耦，V1 为零）
- [ ] 每轨 2–3 个空电容焊盘
- [ ] W7：四轨回流单点汇合于 J_PWR 负极

### 可测性
- [ ] W1：U15.9 (QH′) → ESP32 GPIO
- [ ] J_TEST 6P 排针
- [ ] W3：R6/R7 → ADC
- [ ] W4：RT1/R8 → ADC（NTC 贴 ULN 群中央）

### 布线
- [ ] 电源与地手工布
- [ ] L2 完整 GND 平面不切割
- [ ] VCCS/VCC 主干 ≥2mm
- [ ] **按最终装配方向布局，取消 180° 旋转**
- [ ] SW1 画在拇指位置
- [ ] 自动布线结果人工复查 SPI / SRCLR# / OE#

### 接口机械
- [ ] SW3 焊盘 + W5（可不贴片）
- [ ] USB 调试口装配后可达
- [ ] 复位/BOOT 可达
- [ ] 电池可换
- [ ] 安装孔/定位柱/开孔尺寸一次定完
- [ ] 板框旁预留工装拼板区

### 待定
- [ ] **模块连接方式**（依赖无界现场调研）
- [ ] 是否采用主板/子板分体
- [ ] 线圈电阻、SMA 电阻实测值
- [ ] U51 引脚间距实测 + 3A 是持续还是峰值
- [ ] 继续插 DevKit 还是焊 WROOM 模组

---

## 13. 变更日志

| 日期 | 版本 | 内容 |
|---|---|---|
| 2026-08-10 | v1 | 初稿。确立 V2 三大目标（可测/可换/可验证）；定稿电源架构；记录 P1–P10 与 S1–S3；模块连接方式列为唯一悬空项 |
| 2026-08-13 | v2 | 补入第二次访谈；否决板上音频 |
| 2026-08-13 | **v3** | **电源架构按 12V 电池母线重写**（撤销"取消 5V 中间级"的错误结论，ESP32 走 5V 脚保留板载 LDO 兜底）；可测性按"无示波器"砍到四条，新增 NTC 热监测；充电移出本版；新增 P11（VCC 零去耦）；§8 明确本版不做项；**新增 §11 增删清单**（含 W1–W7 额外改线）；工装形态定稿并排到无界调研之后 |

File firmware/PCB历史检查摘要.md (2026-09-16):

# PCB 历史检查摘要

仅对应 2026-09-14～15 的 PCB1_5 导出，不代表当前投产版本。

- 六层分工：内层1 GND、内层4 VCC，其余四层走线。
- 9月15日 Gerber 几何检查未发现298个电路网络短接或断网；不等于载流、温升及实机验证通过。
- 当时主要问题是电源主通路细线：U49→L1→VCC、电池入口、USB→L4；另需关注局部开关/旁路回路及远端供电压降。后续排查以实际生产板和实测为准，勿套用旧版数值。
- 9月13日助手布局候选未采用，已删除。

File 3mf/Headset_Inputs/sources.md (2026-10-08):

# Required model inputs

- Front_CS30_Mount_Final.3mf is Hsinlung's actually printed front, supplied
  on 2026-10-06. SHA256:
  ef1406f50a50c62fd6e395560f89924b7d319fddc9b5e95bdd94fbafb40aea61.
  It contains the finished geometry, baked print pose and printing settings.
- Medium_Symmetry.stl is the unchanged scale-1 NIOSH ISO Medium Symmetry
  headform from RD-10130-2020-0. Dataset source:
  https://data.restoredcdc.org/rd/rd-10130-2020-0.zip
  prepare.py and datums.json regenerate its registered rear reference mesh.
- ../Headset_Rear/inputs/rear_tray.npz and rear_fill.npz preserve the anatomical
  tray and outer connector surface required by the final rear construction.
  Their provenance and expected generated array hashes are retained in
  ../Headset_Rear/source_provenance.json.

The rear/reference axes are X lateral, Y posterior, Z up. The front retains
its own print coordinates; current camera/head registration is not inferred.

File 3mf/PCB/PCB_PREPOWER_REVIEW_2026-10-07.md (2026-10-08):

# PCB1_5 pre-power review — working notes, 2026-10-07

## Next work and current state

- Hsinlung wants to finish assembling and powering the already-manufactured board. No modules, battery, switches, USB connector or ESP are installed; the remaining SMT parts are reportedly soldered. An adjustable bench supply is available. No physical readings have been received.
- Read-only file checks are complete. Hsinlung explicitly corrected the task: identify this board's limits, obstacles, bottlenecks and practical measurements. Do not turn this into reinforcement, microscopic rework or a replacement PCB project. No repair is a prerequisite to controlled no-load bring-up.
- ESP sockets, SW2 and the USB connector can be soldered. Keep connector installation distinct from connecting a powered USB cable or adding loads during bring-up. The earlier blanket instruction to leave these connectors uninstalled was withdrawn.
- Hsinlung rejected the PDF delivery and requested Markdown for the assistant's own record. Explain findings directly in chat; do not make him read this note to obtain an answer.
- Preserve PCB, schematic, firmware, rules and placement. This audit has not changed them. Keep U48 optional/DNP. No solder repair or firmware edit has been carried out.
- Hsinlung supplied further context: two boards are available, and the module supplier's SMA current is approximately 0.08 A, maximum approximately 0.10 A each. Use this supplier budget (1.2–1.5 A for fifteen), while checking its operating conditions in the single-module test. Do not continue claiming the SMA current is wholly unknown or that fifteen SMAs inherently exceed U50's 3 A rating.
- The earlier real-module escalation plan is superseded by power-path screening with dummy loads before installing the full array. A test on board B is evidence about B and the common design; it does not automatically certify board A.

## Evidence and completed checks

Board UUID: `ee18a5fa84dcc341`, 175 components. Use the **September 15 manufacturing Gerber**, not the earlier unrouted `ProDoc` export. Source directory: `C:/Users/Hsinlung/Downloads`.

| Source | SHA256 |
| --- | --- |
| `ProPrj_test_2026-09-14.epro2` | `3baab5a5025d5d3e656917474c9268d36992920da064ea37aa99657b85bb309a` |
| `Gerber_PCB1_5_2026-09-15.zip` | `05ad356413c3d1ee96b63992e6b6c71dc4399a9aab90f99d8689a383c067296d` |
| `InteractiveBOM_PCB1_5_2026-9-15.html` | `292f6bc0e3b4db20478ce4d166884625133faa2de81a93843aaad90f1235474a` |
| `BOM_Board1_PCB1_5_2026-09-15.xlsx` | `835757f2a68c90db508c8f68d1df4ac0ef328deade753dd56c229a862f4b7fb9` |

- All 175 BOM designators, values and manufacturer part numbers match the project schematic. Evaluate tactile modules as custom interfaces; their borrowed BOM connector identity does not describe their function.
- The 298 circuit-net pin partitions match `Netlist_Schematic1_2026-09-12.tel` and the Gerber flying-probe export. Additional `NET_*` labels are artificial NC labels, not additional functional circuit nets.
- Six copper layers and plated drill connections were reconstructed geometrically and associated with component pads: **no missing pad copper, cross-net shorts or disconnected circuit nets found**. Duplicate exported drill records were not treated as extra parallel holes.
- Inner1 is GND and Inner4 is VCC. Both exported planes contain large continuous copper areas. Outer-layer minimum inter-net spacing was approximately 0.108 mm; the scan found no labeled inter-net copper gap below 0.105 mm.
- All 16 HC595/ULN/module groups were checked for supplies, ground, clocks, reset, OE, cascade and seven output connections.
- Geometry used approximately 0.5 µm arc approximation. These checks do not establish actual solder quality, complete native DRC/DFM compliance, current capacity, loop stability, temperature or RF performance. Original file hashes were rechecked unchanged.
- Temporary parsers, downloaded datasheets and analysis dependencies were cleaned up. The working note and measurement image remain.

## Findings that need practical resolution

### Power current paths

- U49 SW → L1 input carries inductor current through approximately **0.18 mm** copper. The VCC plane cannot bypass this different-net series path.
- A cold strip estimate is on the order of **20 mΩ** for the narrow SW route, using nominal 35 µm outer copper. This is not a full parallel-network resistance measurement, pulse-temperature calculation or allowable-current rating. Overlapping Gerber strokes occupy the same copper and are not doubled copper thickness. Do not use this number alone to demand rework or declare the board unusable.
- L1's VCC pad has no local plated-hole array. Copper must reach the plane through external traces/holes. Nearby VCC vias use approximately 0.312 mm drill diameter. Actual finished copper and hole-wall plating have not been measured.
- Battery input, 5 V converter and charger switching paths also contain 0.18/0.23 mm segments. Do not propose reinforcing only SW → L1 and then claim all other high-current paths are cleared.
- Use trace calculations only to select voltage-drop and temperature measurements. They do not establish a safe current limit or prove the board unusable. Reinforcement proposals were outside the requested direction and have been stopped.
- Regulated VCC remaining nominal does not establish low dissipation in the U49 SW-to-L1 series trace. The feedback loop can compensate a resistive loss while the trace heats. Voltage observations are useful for localization after regulation/delivery deteriorates; they are not advance protection against trace failure. Dummy-load screening must also include actual load-current confirmation and local temperature monitoring; absence of a burnt trace is not a sufficient pass criterion.
- Actual Gerber aperture orientation places L1's pad at 4 mm wide by 5 mm high in the top projection. The former 6.87 mm / 18.8 mΩ estimate used the wrong rectangular orientation and was withdrawn. The resistive narrow section is roughly 7–8 mm. A centerline-only subtraction gives 8.37 mm but counts a vertical segment touching the long U49 pad along its edge; this is not a full resistance solution. Avoid false precision from simplified graph models.
- Manufacturing copper includes routes different from the project export. Geometric net association found no cross-net label conflicts. USB VIN_C follows a long 0.18 mm path through internal routing layers; VCCS also follows long fine traces and has no supply plane. Exact network resistance was not established, so do not present shortest-path estimates as complete parallel-network or thermal results.

### SW trace adjacent-plane check and rough thermal estimate

- Latest request: check whether U49 pin20 → L1 has adjacent copper and roughly assess the quoted 30/36/50-coil thermal limits. This does not authorize rework or redesign.
- Both parts and the SW route are on Bottom. The immediately adjacent plane is Inner4 (physical copper layer 5), VCC, not the opposite-side Inner1 GND plane.
- In the target PCB document (`ee18a5fa84dcc341`), select current records by ticket, not the last historical occurrence in the whole EPRU. `LAYER_PHYS` dielectric365 is 3.913 mil = 0.0993902 mm, material 3313 RC57%. Inner4 copper is 0.598 mil = 15.1892 µm; outer copper is 1.378 mil ≈35 µm. These are CAD stack settings, not measured finished-board dimensions.
- Reconstructed manufacturing `Gerber_InnerLayer4.G4` dark-plane region minus clear antipads before isolated pad flashes. The largest connected VCC region is 5852.316 mm². Along the main SW centerline, no missing plane was found. Approximately 97.3% of the 0.18 mm route footprint outside the two large pads overlaps this connected plane. Three antipad circles clip the footprint edges near x=−4.02148, −2.83513 and +0.69276 mm; they do not cut across the route. Nearby plane copper exists; it is not an isolated island or a whole-length keepout. Diagram: `PCB_SW_INNER4_2026-10-07.png`, common TOP projection.
- Using roughly 20 mΩ cold strip resistance and 0.17 A per coil, 24/30/36/50/90 simultaneously active coils draw 4.08/5.10/6.12/8.50/15.30 A. Including nominal 2.31 A p-p inductor ripple gives approximately 0.35/0.54/0.77/1.47/4.75 W ON-time strip loss; 20% duty gives approximately 0.069/0.107/0.153/0.294/0.950 W average, before temperature-driven resistance increase.
- Exploratory strip/FR4 conduction sensitivity used FR4 k=0.25–0.4 W/(m K), copper k=385, FR4 volumetric heat capacity 1.8 MJ/(m³ K) as an assumed typical value, copper temperature coefficient 0.00393/K. With the adjacent plane held at 25°C and ignoring end-pad cooling, 200 ms / 1 Hz pulse hotspot rises were ~42–71 K at 24 coils, ~71–127 K at 30, ~115–221 K at 36. This is a deliberately simplified comparison, not calibrated full-board simulation. End pads reduce these rises; plane/IC/inductor heating and antipads can increase them. Changing copper thickness or actual coil current materially changes the result.
- An infinite-length-strip/full-cross-section model substantially overstates the whole-plane steady heating for this short route; its numerical temperatures were discarded. At high temperatures all linear models also become invalid; their runaway numbers must not be presented as physical fusing temperatures.
- Engineering judgment for the requested rough estimate: thirty coils can plausibly reach about 100°C, with a broad approximate 80–160°C range under nominal 35 µm copper, room temperature, normal 200 ms / ~1 Hz pulses. This is a sensitivity envelope, not a guaranteed bound. Twenty-something coils are a lower-load validation region; thirty is a borderline test candidate. No established lifetime/current rating or sharp 36-coil damage / 50-coil fuse threshold follows. Fifty coils have much higher thermal risk (~2.75 times thirty-coil cold ON-time loss). Continuous-on/hold use is a different, more severe condition.
- Nearby plane copper spreads heat but does not electrically bypass the SW trace. Do not reduce local peak temperature to 20% merely because average duty is 20%; the short trace can heat substantially within 200 ms. Screen increasing dummy-load current while observing local temperature; no physical measurement has yet been received.
- Material references: [TI SNOA967A](https://www.ti.com/lit/an/snoa967a/snoa967a.pdf), [TI SNIA021](https://www.ti.com/lit/an/snia021/snia021.pdf). These support material conductivity / heat-flow considerations, not this board's estimated temperatures or coil-count limit.

### GPIO9 / OE compatibility

- U54 channel 2 connects 595 OE# to an intermediate node; channel 3 connects that node to GND. SEL2 is GPIO9; SEL3 is EN_MAIN. R11 pulls OE# up to VCC_LOGIC.
- With 3.3 V present and EN_MAIN high: **GPIO9 LOW disables outputs; GPIO9 HIGH enables outputs**. EN_MAIN low disables the series path.
- Current [V2.8 firmware](C:/Users/Hsinlung/Desktop/LingTouchCompanion/firmware/braille_15module_prod/braille_15module_prod.ino) sets GPIO9 HIGH in `initGPIO()`, then LOW in `sendRaw()` and at the end of setup. This is opposite to the new hardware's enable polarity. The initial HIGH can enable outputs before the first all-zero latch; actual startup behavior has not been measured.
- A compatible startup must keep output disabled while clearing the shift registers and latching zeros, then enable deliberately. SRCLR clears the shift register, not the output storage register. Firmware adaptation remains pending; no file was edited.
- `refreshGrouped()` enables SMA bit6 for every module in the batch, even if that module's requested coil data is zero. Default batch size is fifteen. `set N XX` therefore does not mean only N is electrically active.
- `moduleMask` is used by status printing and demo selection, but not by `refreshGrouped()`, ordinary `set`/`test`, raw frame processing or BLE refresh. It is not a functioning load-isolation control.
- `cmdHold()` blocks serial processing in second-long delays; `cmdEx()` blocks for its 400/300/600 ms cycles. The serial `stop` command cannot immediately interrupt these functions. Neither existing diagnostic is an appropriate first pulse test.
- Controlled bring-up needs correct OE polarity, disabled startup until zero is latched, actual coil-only/SMA-only/combined short-pulse selection, true module selection and a bounded pulse timeout. This analysis has not implemented those changes. External PSU output OFF remains the physical stop control during bench tests.
- Current firmware does not read PGOOD/GPIO14 or enable/sample the switched battery ADC through GPIO5/GPIO4. Hardware SMA gating still follows PGOOD; these features are not implemented software monitoring.
- The chain is U1 → … → U15 → U46. Groups 1–15 are U1–U15 → U16–U30 → U31–U45; group 16 is U46 → U47 → U48. The existing 15-byte reverse mapping addresses the first 15 groups correctly, but the 16th stage receives prior shifted data on later transfers. Keep U48 uninstalled until explicitly handled.

### Other observations

- U55 nominal startup is about **6.55 V** and falling shutdown about **5.74 V**, including R36 feedback. Do not describe this network as a verified 6 V cutoff or substitute for the external 2S protection board.
- Overlaying the official YD V1.4 dimensions places the antenna over the baseboard. GND/VCC planes occupy most of that projected region. BLE range remains unverified; this does not block no-load rail measurements.
- HC595 is powered at approximately 3.3 V. A 4.5 V per-pin test condition is not a complete 3.3 V loaded-VOH guarantee, nor a whole-chip current limit. Mixic ULN2003A has roughly 1 V saturation drop around 200 mA under the datasheet's drive conditions; actual module current and voltage need measurement.
- U50 RT6253A is a nominal 3 A converter shared by all fifteen SMAs. Hsinlung reports supplier SMA figures of approximately 0.08 A, maximum approximately 0.10 A each, giving 1.2–1.5 A total for fifteen. Rated-current mismatch is therefore not the present primary obstacle. Still check far-position voltage, driver loss, transient behavior and actual mechanical action. The 0.17 A coil budget is separate.
- ULN voltage loss applies to SMA as well as coils. A 3.53 V supply is not 3.53 V across a coil; a 2.00 V supply is not 2.00 V across the SMA. Measure each load between its own positive and switched return terminals. Test successful rise, reset/lock and holding after power is removed, not only a click or movement.
- Each ULN handles six coils plus an SMA, so package dissipation and repeated-pulse heat matter even when every channel is below its individual maximum. Six 0.17 A coils alone give roughly 1 W instantaneous ULN conduction loss if saturation is around 1 V; the intended 200 ms / 1 Hz pattern reduces time average but does not establish temperature.
- U52 is a 1.5 A maximum-continuous-current device on the ESP 5 V path, not a fifteen-module load path. YD's CJ6107 LDO also requires thermal verification; its 1 A typical headline is not a board-level continuous capability. At 0.30 A, an ideal 5-to-3.3 V drop alone dissipates about 0.51 W.
- The charging circuit disables battery-temperature sensing with R22 = 51k. BATM/BAT_GND are not connected for IP2326 cell balancing. The external 2S protection/balancing board must therefore be checked independently; charging to 8.3 V pack voltage does not alone establish safe individual-cell voltages.

## Assembly references and accessible measurement points

- **J3 = BAT+**, **J4 = GND**; both are backside circular solder pads, approximately 4 mm diameter. Main current must not use a single J_test pin.
- SW2: pin 1 GND, pin 2 switched control supply, pin 3 VBAT. Contacts 1–2 mean OFF; 2–3 mean ON. It switches control signals, so battery-input circuitry stays energized in OFF. SW1 is the separate optional button.
- ESP sockets: two 1 × 22, 2.54 mm pitch, 25.4 mm row spacing. USB end faces SW2/baseboard USB; antenna end faces the module area. Verify actual socket height and underside clearance before completing soldering.
- Tactile-module holes: two columns of six, 1.25 mm pitch, 4.96 mm column separation and 0.60 mm stagger. A standard 2.54 mm or aligned 2 × 6 header does not fit.
- C74–C79 pin 1 is VCC positive, pin 2 GND. C80 pin 1 is VBAT positive, pin 2 GND. D1/D2 pin 1 is cathode/GND. Backside viewing mirrors the top projection.
- [Measurement map](PCB_MEASURE_MAP_2026-10-07.png): viewed from TOP; J3/J4 are shown through the board. J_test's rightmost square pad is pin 1; numbers increase leftward.

| J_test | Net | J_test | Net |
| --- | --- | --- | --- |
| 1 | VCC | 12 | GND |
| 2 | GND | 13 | U1.SER |
| 3 | VCCS | 14 | GPIO13 |
| 4 | GND | 15 | GPIO4 / battery ADC |
| 5 | VCC_LOGIC | 16 | RCLK |
| 6 | ESP_3V3, before R19 | 17 | EN_MAIN |
| 7 | VBAT, after Q1 | 18 | 595 OE# |
| 8 | VIN_C, baseboard USB | 19 | GPIO9 / U54 SEL2 |
| 9 | GND | 20 | SRCLR# |
| 10 | V5S | 21 | U49 PGOOD |
| 11 | SRCLK | 22 | GND |

ESP `J_ESP_L`: pins 1/2 = 3.3 V, 12 = GPIO8/SRCLR, 15 = GPIO9/OE control, 16 = GPIO10/RCLK, 17 = GPIO11/SER, 18 = GPIO12/SRCLK, 20 = GPIO14/PGOOD, 21 = V5S, 22 = GND. `J_ESP_R` pin 1 = GND.

Each group: bit0–5 uses HC595 pins 15/1/2/3/4/5 → ULN inputs 1–6 → module pins 2/4/6/8/9/11. Bit6 uses HC595 pin 6 → ULN input 7 → module pin 3, SMA return. Bit7 unused. Module pins 1/5/7/10 = VCC; pin 12 = VCCS. ULN pin 8 = GND, pin 9 COM = VCC.

## Proposed bring-up sequence — no physical results yet

1. Verify solder bridges, fitted-part orientation, polarized parts and persistent near-zero rail-to-ground resistance. A changing resistance or brief continuity beep from charging capacitors is not alone evidence of a hard short.
2. With PSU output OFF, set 7.4 V / 0.10 A and SW2 OFF; connect J3 positive/J4 negative, then enable the supply. Check battery entry and EN_MAIN.
3. Switch PSU output OFF, set 0.30 A and SW2 ON, then enable again. Record steady input current and the rails below. Brief current limiting may be capacitive startup; sustained limiting or supply collapse is unresolved, not proof of a failed chip. Stop for sustained limiting, rapid heating or odor; do not blindly increase the limit.
4. After no-load VCC/V5S checks, power down and insert ESP, still without modules. A proposed 0.50 A input limit allows checking ESP startup, 3.3 V and VCCS. These PSU settings are test limits, not PCB current ratings.
5. Resolve OE startup compatibility before connecting one module. Verify one coil's short pulse, then SMA behavior and voltage drop/temperature. Existing `hold` defaults to 5 s and `ex` uses a 400 ms SMA window; neither is the initial validation command. Full simultaneous loading and charging need separate assessment.

Test objectives after no-load startup:
- A single-group test validates GPIO/OE, shift ordering, ULN outputs and real coil/SMA behavior; it does not prove fifteen-group power delivery.
- Increase coil load in stages using the intended 200 ms / approximately 1 Hz pulse sequence. Observe input collapse, VCC sag at near and far module supply holes, resets and repeated-pulse temperature rise. Add SMA overlap only after coil behavior is established. Do not substitute a prolonged all-on command for the intended duty cycle.
- The 15.3 A coil budget is regulator-output current, not bench-supply input current. Bench display and an ordinary multimeter may miss 200 ms transients; record this measurement limitation rather than claiming full-load validation from a normal average reading.
- Accessible DC comparison points include J3 versus C80 positive for battery-entry delivery and L1 VCC output versus C74 positive for VCC plane entry. Do not ask for live probing of U49's narrow SW pad; a meter reading there would not characterize the switching waveform anyway.
- USB charging is tested separately with a suitable protected 2S battery after basic power behavior is established. Do not connect charging USB while a conventional non-sinking PSU substitutes for the battery.

Nominal load estimates for sizing the test source, not measured or approved limits:
- Six coils per module: 1.02 A on VCC, fifteen modules: 15.3 A, approximately 54 W while energized at 3.53 V.
- Assuming 90% conversion efficiency at 7.4 V, fifteen coils groups alone require about 8.1 A at the battery input; around 5.74 V this becomes about 10.5 A. Add ESP, SMA and other losses. A lower-current bench supply cannot prove fifteen-group capability; its own current limiting must be distinguished from PCB failure.
- At 200 ms every second, ideal coil-rail average power is about 10.8 W. Do not use this average to judge startup, peak current, droop or transient heating.

Practical localization with common ground reference J4 and the same repeated test pattern:
| Observed behavior | Interpretation to investigate |
| --- | --- |
| PSU terminal voltage falls / current limit is reached | Source limit or test leads; not yet evidence of PCB failure |
| J3 remains stable but C80 positive/VBAT falls | Battery-entry/Q1/interconnect delivery path |
| VBAT remains stable but L1 VCC output falls | U49 conversion/input/return path, current limiting or transient response |
| L1 VCC output is stable but C74 positive falls | VCC-plane access path |
| C74 and near module VCC are stable, far module VCC falls | Distribution/connector delivery to the far position |
| Near 2 V falls with VBAT stable | U50 conversion capacity or transient response |
| Near 2 V is stable but far module pin12 falls | VCCS distribution or connector delivery |
| V5S stays stable but ESP 3.3 V falls/resets | Development-board input/LDO/3.3 V load path |
| Supplies are stable but bits or movements are wrong | OE/clock/cascade/mapping, driver voltage loss or module mechanics; isolate these next |

For functional testing, establish one coil and one SMA separately, then a whole six-coil group and the normal combined sequence. Compare near and far positions using a removable known module. Before a full real-module array, screen the power paths with dummy loads at increasing measured currents using the intended 200 ms / approximately 1 Hz pulse sequence. A continuous 15 A test is a different stress condition and cannot replace the intended-duty test.

Dummy-load boundaries:
- At 3.53 V, a nominal fifteen-group coil budget of 15.3 A corresponds to approximately 0.231 ohm and 54 W during ON time. These are sizing calculations, not a recommendation to immediately attach that resistance.
- A resistor alone is a static load. Controlled 200 ms pulses need an external timed load switch or a suitable dynamic electronic load; do not pretend manual contact or repeated PSU soft-start is an equivalent load transient.
- A central load at L1 output tests the converter, SW trace and inductor, but bypasses the VCC-plane entry/distribution paths. Distributed loads at actual supply positions can cover those paths; allocate current across the actual intended pins. Do not run fifteen amperes through one J_test or module pin or impose that current on a single capacitor-pad stub.
- Dummy load connected directly to supply/GND does not validate ULN output loss/heat, load inductance, flyback, SMA mechanics or the real connectors unless those paths are explicitly included.
- B passing does not prove A's solder quality or individual reliability. A also needs power-path screening, followed by real-array verification. Modules connected through sockets are removable; board failure does not inherently trap them, although a supply fault can damage attached modules.
- No dummy-load hardware has been selected, built or tested. Bench PSU capability, controlled pulse generation and suitable local temperature measurement remain unresolved equipment constraints for the full-current screen.

After power-path and real-array verification, finish with reduced battery voltage and the external protection board, then separate charging and finally the intended charging-plus-use condition.

| Point | SW2 OFF, no ESP | SW2 ON, no ESP | ON with ESP, no modules |
| --- | --- | --- | --- |
| J_test 7 VBAT | ~7.4 V | ~7.4 V | ~7.4 V |
| J_test 17 EN_MAIN | ~0 V | ~2.43 V | ~2.43 V |
| J_test 1 VCC | ~0 V after discharge | ~3.53 V | ~3.53 V |
| J_test 10 V5S | ~0 V after discharge | ~5 V | ~5 V |
| J_test 5/6 logic/raw 3.3 V | ~0 V | ~0 V | ~3.3 V |
| J_test 3 VCCS | ~0 V | ~0 V | ~2 V when PGOOD high |
| J_test 21 PGOOD | ~0 V | Usually ~0 V; pull-up unpowered | ~3.3 V when VCC good |

Without ESP, absent VCC_LOGIC/VCCS and an unlit D2 are expected. U54 is powered from ESP's 3.3 V; channel 4 passes PGOOD to EN_SMA only when EN_MAIN is high. D1 is a charging indicator. Keep USB cables disconnected while a normal bench PSU substitutes for the battery: the charger can drive current into BAT+, and the PSU is not known to sink current. USB-OTG and IN-OUT bypasses on the YD board are distinct; do not infer their states from each other.

SW2 OFF stops the enabled converters; it does not disconnect BAT+ from the board. Previously charged VCC/V5S capacitors may retain voltage, especially with no ESP or modules, so nonzero output voltage immediately after switching OFF is not by itself an enable fault. Check EN_MAIN and decay rather than requiring instantaneous zero. Before resistance measurements, confirm supply removal and discharged rails.

For undervoltage validation, start at 7.4 V and reduce the input slowly, recording EN_MAIN/PGOOD shutdown near the nominal 5.74 V falling threshold. Then raise it and record restart near 6.55 V. A fresh startup at 6.0 V is not expected with these thresholds; low-voltage load testing at 6.0 V must be reached by lowering an already-running supply. Use no modules for the first threshold sweep.

## Current electrical settings

| Circuit | Verified file settings / interpretation |
| --- | --- |
| U49 | MP8795HGLE-Z despite borrowed MPQ footprint name; L1 = 1 µH YSPI1365-1R0M; R7/R8 = 82.5k/16.9k, nominal 3.529 V; MODE R38 = 30.1k, about 800 kHz; R1 = 6.65k. Nominal valley OCP ~18 A, not a peak limit or protection for the thin traces. Ideal ripple at 7.4 V ~2.31 A. |
| U50 | RT6253AHGJ6F TSOT, 0.765 V reference; R9/R10 = 16.2k/10k, nominal 2.004 V; L2 = 2.2 µH. |
| U51/U52 | TPS630701 fixed 5 V, L3 = 1 µH; LM66100 reverse blocking, CE tied to V5S is intentional. |
| U55 | R34/R35/R36 = 150k/10k/390k; R6/R3 = 20k/10k; nominal comparator rising/falling thresholds 400/394.5 mV. |
| U53 | IP2326, R20 = 90k → nominal 1 A battery charge; R39 = 120k → ~8.3 V full charge; R21 = 120k → ~12 h timeout; R22 = 51k disables NTC; L4 = 2.2 µH. R23 = 0.5 Ω/0603 is only IC VIN filtering; L4 input directly uses VIN_C. Charging 2S at 1 A can draw about 2 A or more from 5 V, so charger-path capacity remains unresolved. |
| Local bypass | U49 C59/C60/C91; U50 C61/C62; U51 C63/C36. C71 = 1 µF on U49 internal VCC; C82 = 100 nF on U51 VAUX. |
| Bulk caps | Six 6SVPC330M, 330 µF/6.3 V, on VCC; C80 = 100 µF/16 V on VBAT. Nominal capacitance does not establish effective MLCC capacitance under DC bias. |
| Other interfaces | Q1 source = VBAT, drain = BAT+, intentional PMOS reverse-polarity topology. USB CC pull-downs R16/R17 = 5.1k. ADC divider R30/R15 = 100k/39k gives ~2.36 V at 8.4 V; U54 channel 1 controlled by GPIO5, default pulled low. |

## Manufacturer references used in the audit

- [MPS MP8795H](https://www.monolithicpower.com/en/documentview/productdocument/index/version/2/document_type/Datasheet/lang/en/sku/MP8795HGLE-Z/)
- [Richtek RT6253A/B](https://www.richtek.com/assets/product_file/RT6253A=RT6253B/DS6253AB-04.pdf)
- [TI TPS63070/701](https://www.ti.com/lit/ds/symlink/tps63070.pdf), [LM66100](https://www.ti.com/lit/ds/symlink/lm66100.pdf), [TMUX1511](https://www.ti.com/lit/ds/symlink/tmux1511.pdf), [TPS3700](https://www.ti.com/lit/ds/symlink/tps3700.pdf), [SN74HC595](https://www.ti.com/lit/ds/symlink/sn74hc595.pdf)
- [Injoinic IP2326, manufacturer-authored, M5Stack-hosted](https://m5stack-doc.oss-cn-shenzhen.aliyuncs.com/1132/IP2326.pdf)
- [Mixic ULN2003A, manufacturer-authored, LCSC-hosted](https://datasheet.lcsc.com/datasheet/pdf/54105fc0587bc762a1d5c58f9f51fcdc.pdf?productCode=C181730)
- [YJYCOIN YSPI1365, manufacturer-authored, LCSC-hosted](https://atta.szlcsc.com/upload/public/pdf/source/20221123/B5C8ED80AB877E8B7DB1203AF510D731.pdf)
- [TDK SPM5030VT](https://product.tdk.com/system/files/dam/doc/product/inductor/inductor/smd/catalog/inductor_automotive_power_spm5030vt-d_en.pdf)
- [YD-ESP32-S3 official hardware files](https://github.com/vcc-gnd/YD-ESP32-S3/tree/main/5-public-YD-ESP32-S3-Hardware%20info)
- [Espressif antenna/baseboard guidance](https://docs.espressif.com/projects/esp-hardware-design-guidelines/zh_CN/latest/esp32s3/pcb-layout-design.html)

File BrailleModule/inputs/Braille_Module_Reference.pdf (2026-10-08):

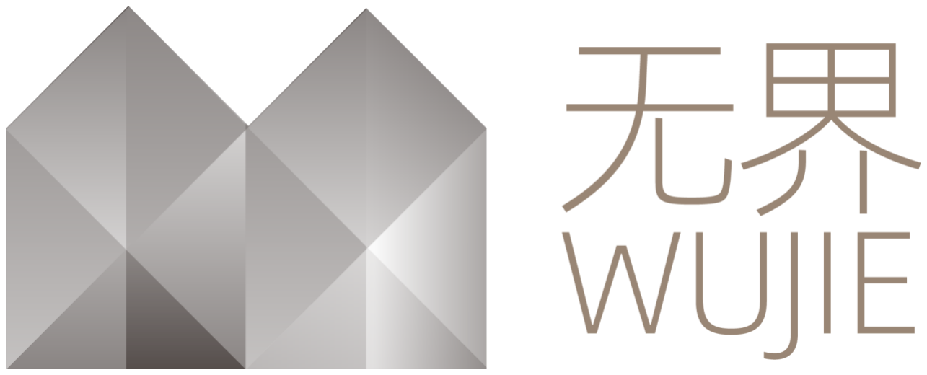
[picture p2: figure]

# 盲文显示模块技术参数和规格 记录人：郦铖

日期：2026/2/24

## 1 产品概述：

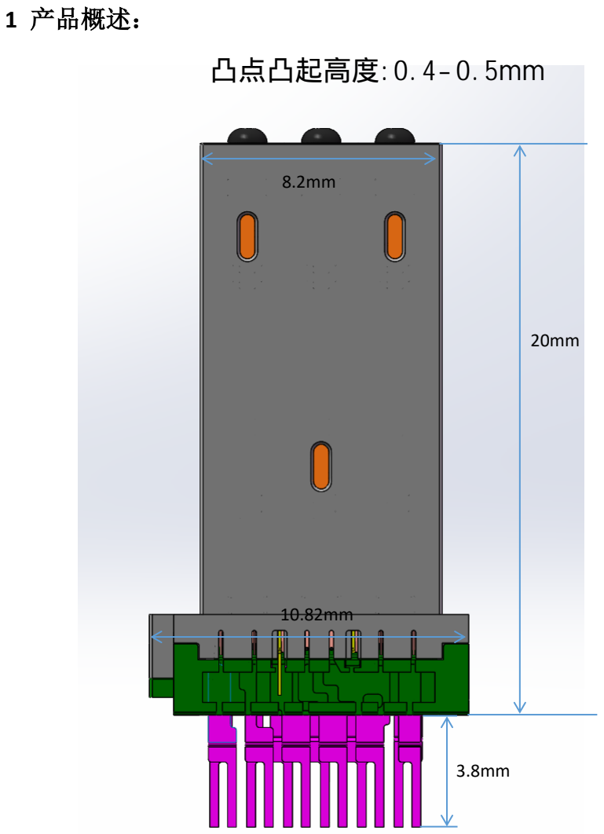
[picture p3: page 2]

20mm

8.2mm

10.82mm

3.8mm

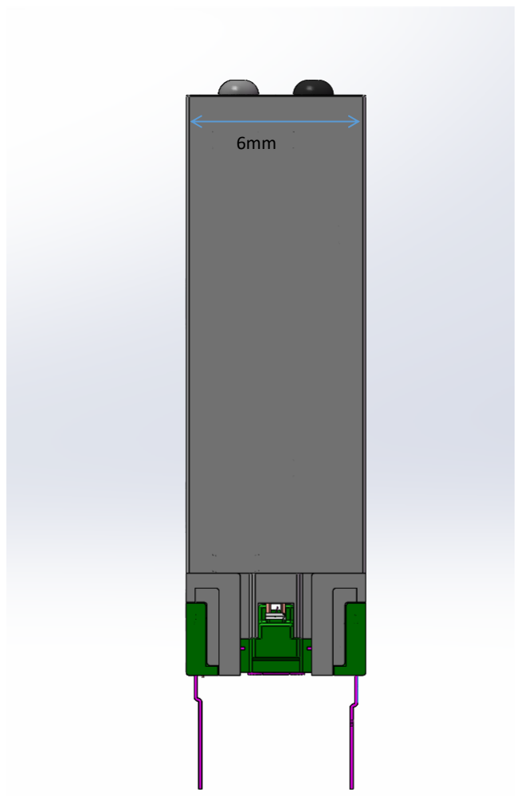
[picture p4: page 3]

6mm

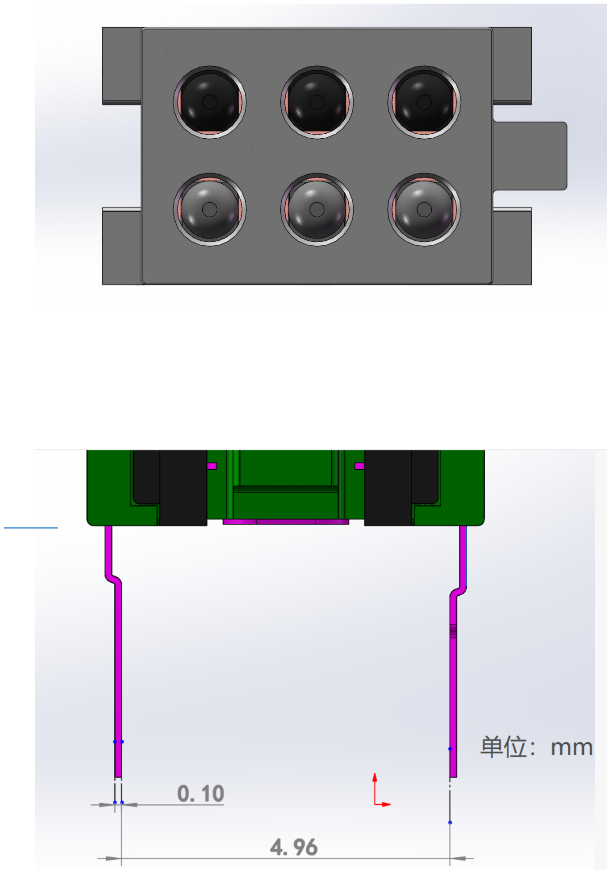
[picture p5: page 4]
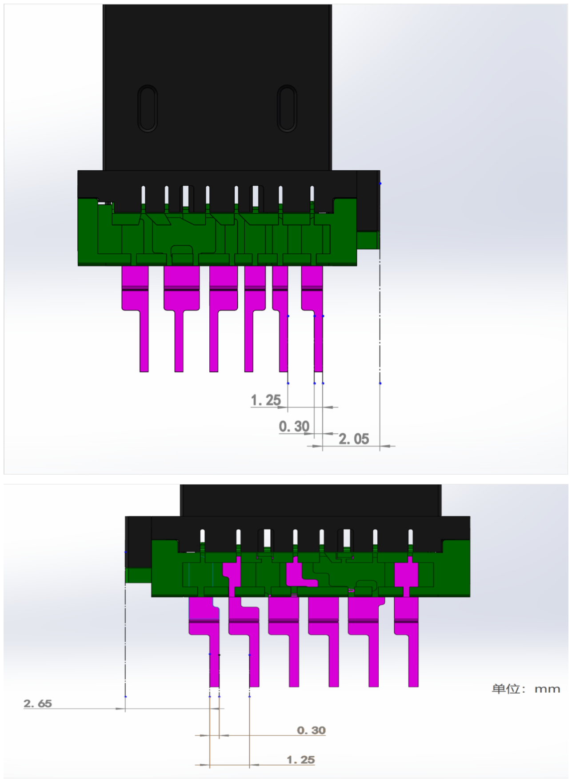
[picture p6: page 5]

1
2

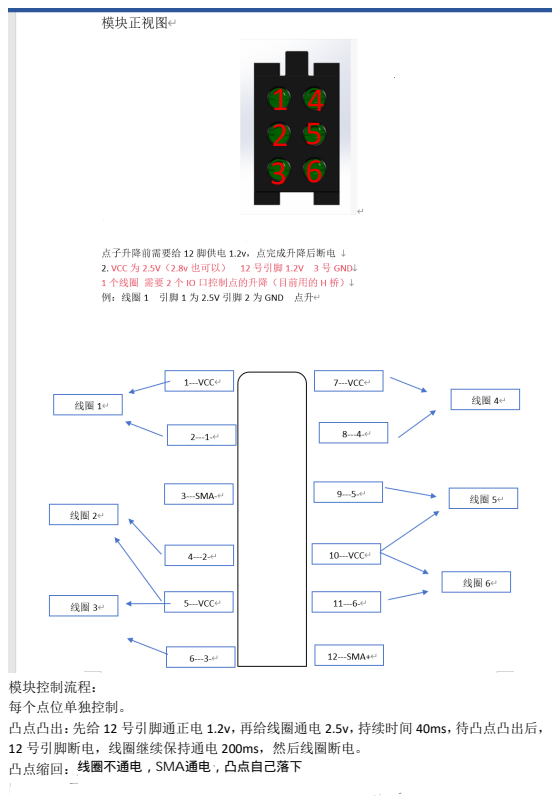
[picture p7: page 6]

模块控制流程：
每个点位单独控制。
凸点凸出：先给 12 号引脚通正电 1.2v，再给线圈通电 2.5v，持续时间 40ms，待凸点凸出后，
12 号引脚断电，线圈继续保持通电 200ms，然后线圈断电。
凸点缩回：先给 12 号引脚通正电 1.2v，再给线圈反向通电 2.5v，持续时间 40ms，待凸点缩
回后，12 号引脚断电，线圈继续保持通电 200ms，然后线圈断电。

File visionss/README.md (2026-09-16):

# 当前实验视觉通路

手机拍摄 → 米制深度 → 地面拟合 → 空间栅格或单点告警 → BLE。两种条件共用 `experiment_server.py`，输出映射分别位于 `topdown_pipeline.py` 和 `single_point/alert_pipeline.py`。

## 准备与启动

Python 依赖包括 PyTorch、NumPy、OpenCV、Pillow、Matplotlib、bleak、cryptography，以及 Depth Anything V2 自身依赖。本机使用 `D:\anaconda\envs\LING\python.exe`。

仓库根目录须另备 `Depth-Anything-V2/metric_depth/` 源码，权重放在：

```text
Depth-Anything-V2/metric_depth/checkpoints/depth_anything_v2_metric_hypersim_vitl.pth
```

以下命令均在仓库根目录执行：

```powershell
python visionss/phone_server.py            # 空间触觉，HTTPS 8760
python single_point/alert_server.py        # 单点告警，HTTPS 8761
```

加 `--no-ble` 可在不连接设备时运行。手机与电脑连接同一局域网，打开终端显示的 HTTPS 地址，接受本地证书并开始预览。

终端命令：`start [标签]` 开始连续试次，`stop` 停止，`snap` 单帧，`export` 保存一帧，`status` 查看状态，`q` 退出。

## 文件与工具

| 文件 | 用途 |
|---|---|
| `depth_runner.py` | 常驻加载深度模型 |
| `phone_camera.html` | 手机拍摄页面，由实验服务提供 |
| `frame_converter.py` / `scan_link.py` | 栅格转15字节、BLE连接与刷新确认 |
| `depth_server.py` | 配合根目录 `depth_preview.html`，默认本机 HTTP 8765 |
| `evaluate_obstacle_scenes.py` | 根据 manifest 重放场景，比较默认映射与指定配置 |
| `profiles/multi_obstacle_preview.json` | 多障碍预览配置；正式入口不自动启用 |

离线评估参数为 `--manifest <文件> --outdir <目录>`，可用 `--profile <文件>` 替换配置、`--infer` 重新推理。空间实验通过 `--topdown-profile <文件>` 显式加载配置。

## 输出与验证

默认周期约1秒；等待固件刷新完成后继续，连续3帧失败自动暂停。日志写入 `experiment_runs/`，默认不保存逐帧大文件。

输出为10行×9列，行从远到近；发送前做穿戴左右镜像。手机上传长边2048，转正后按宽度换算焦距；默认相机高度1.40 m。首次真机使用需核对旋转方向、视场和装配映射，离线回归不代替实机验证。

标定与地面材质限制见 [验证记录](../TOPDOWN_VALIDATION.md)。

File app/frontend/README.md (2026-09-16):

# 手机应用

基于 uni-app（Vue），提供导航、BLE 设备控制、语音交互与诊断页面。

## 运行

用 HBuilderX 打开 `app/frontend/`，选择运行到浏览器或手机；BLE 等设备功能需在支持的平台验证。

- `utils/request.js`：后端地址，默认 `http://localhost:3000`；真机访问需改为电脑可达地址。
- `api/map.js`：高德路线服务配置。
- `pages/navigation/navigation.vue`：高德地图 JS 配置。

两处地图 Key 均为无效占位值（`REPLACE_WITH_YOUR_...`），不能直接调用服务。使用前分别配置自己的高德 Web 服务 Key 和 JS API Key；不要把真实值提交到仓库。

## 页面

| 页面 | 用途 |
|---|---|
| `home` | 首页与入口 |
| `navigation` | 步行导航 |
| `map` | 地图页面 |
| `device` | BLE连接与触觉控制 |
| `diagnostic` | 设备诊断 |

后端说明见 [app/backend](../backend/README.md)。编译输出 `unpackage/` 不提交。

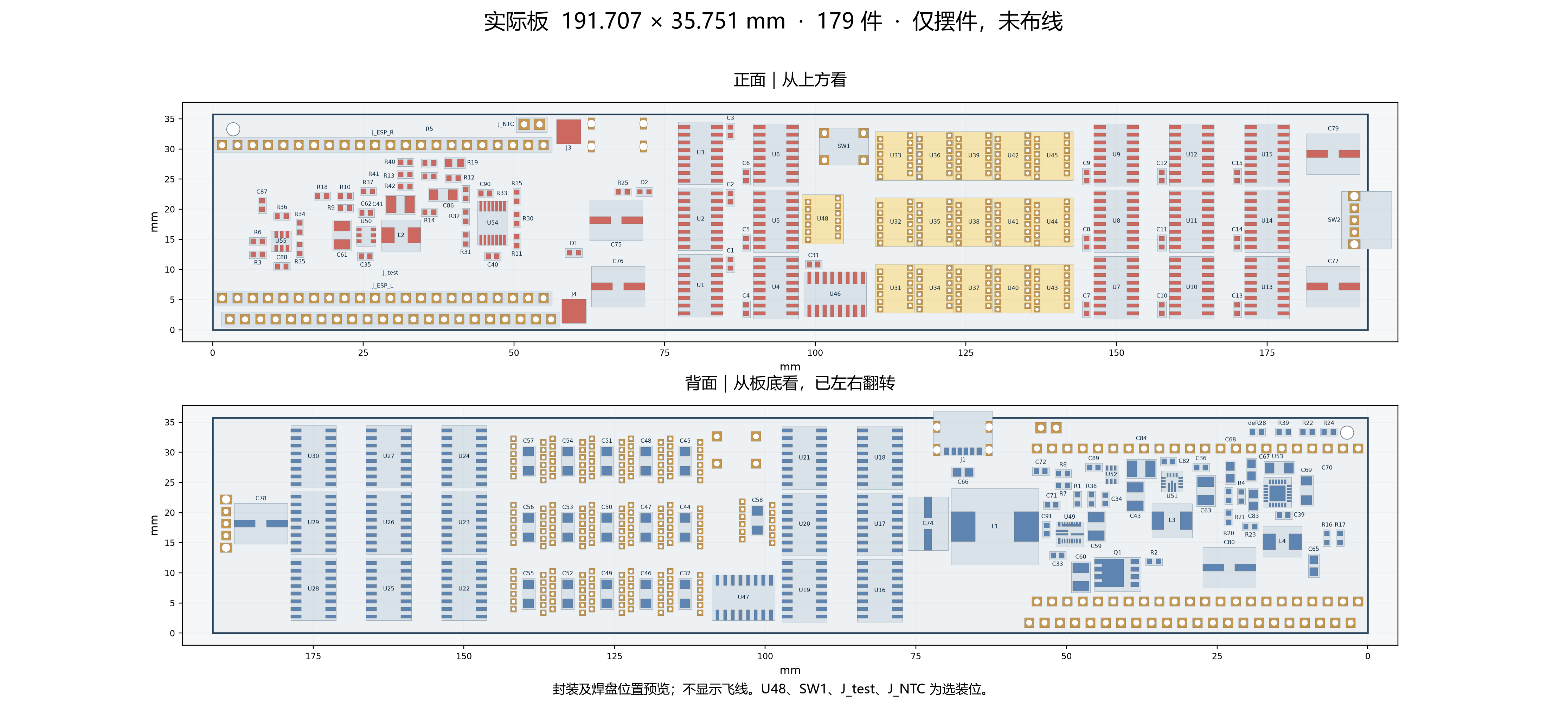
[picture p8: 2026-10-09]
PCB_REDESIGN_2026-10-08/actual_placement.png

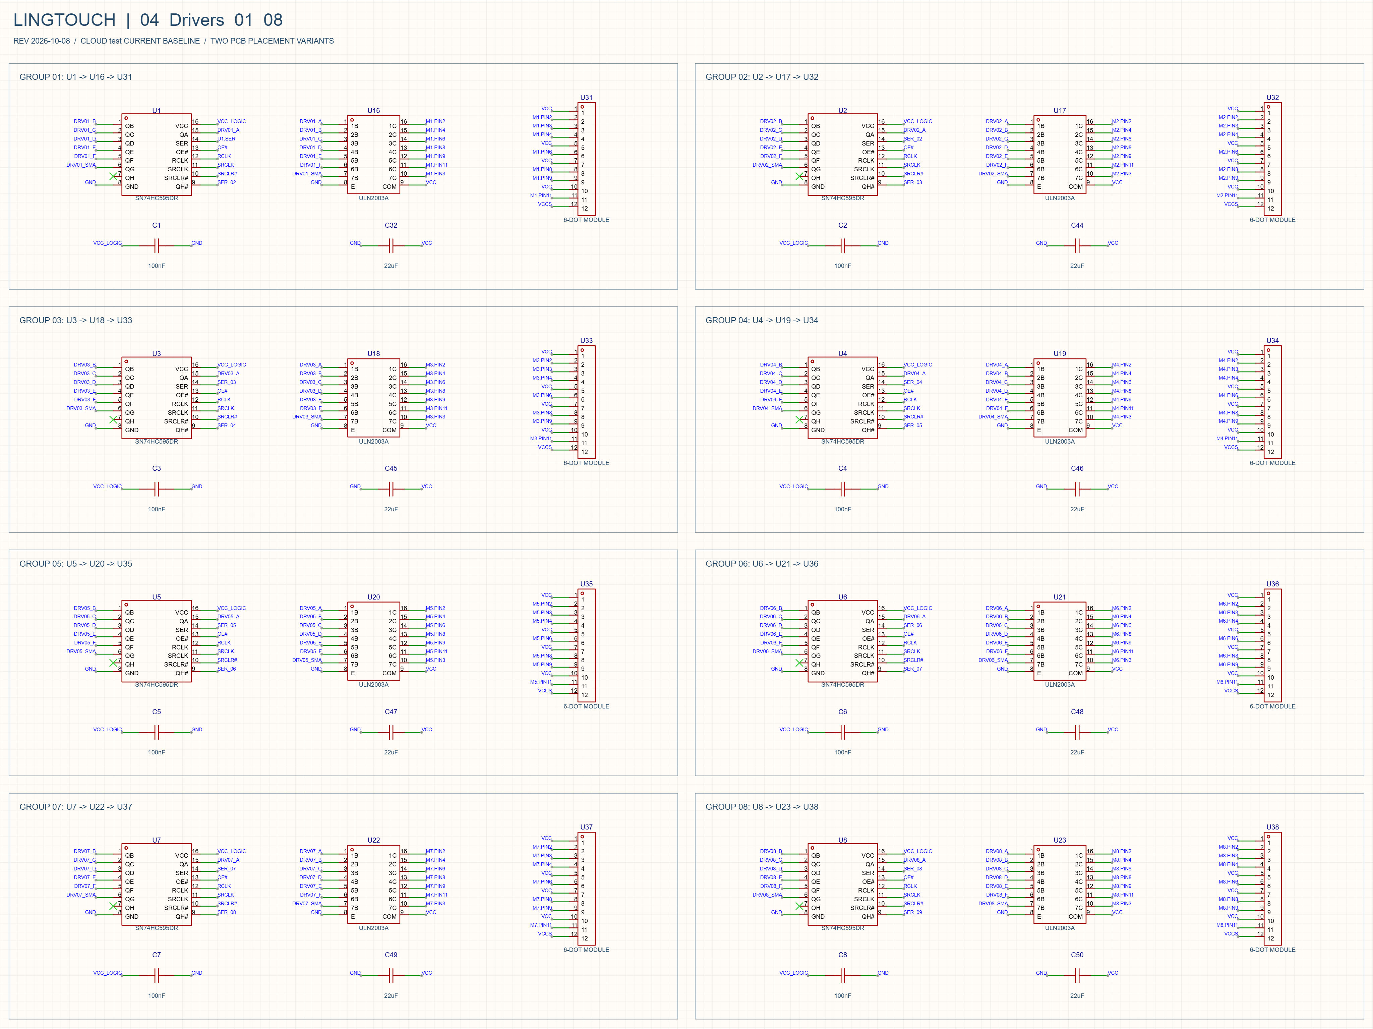
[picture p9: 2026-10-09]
PCB_REDESIGN_2026-10-08/schematic_4-04_Drivers_01_08.png

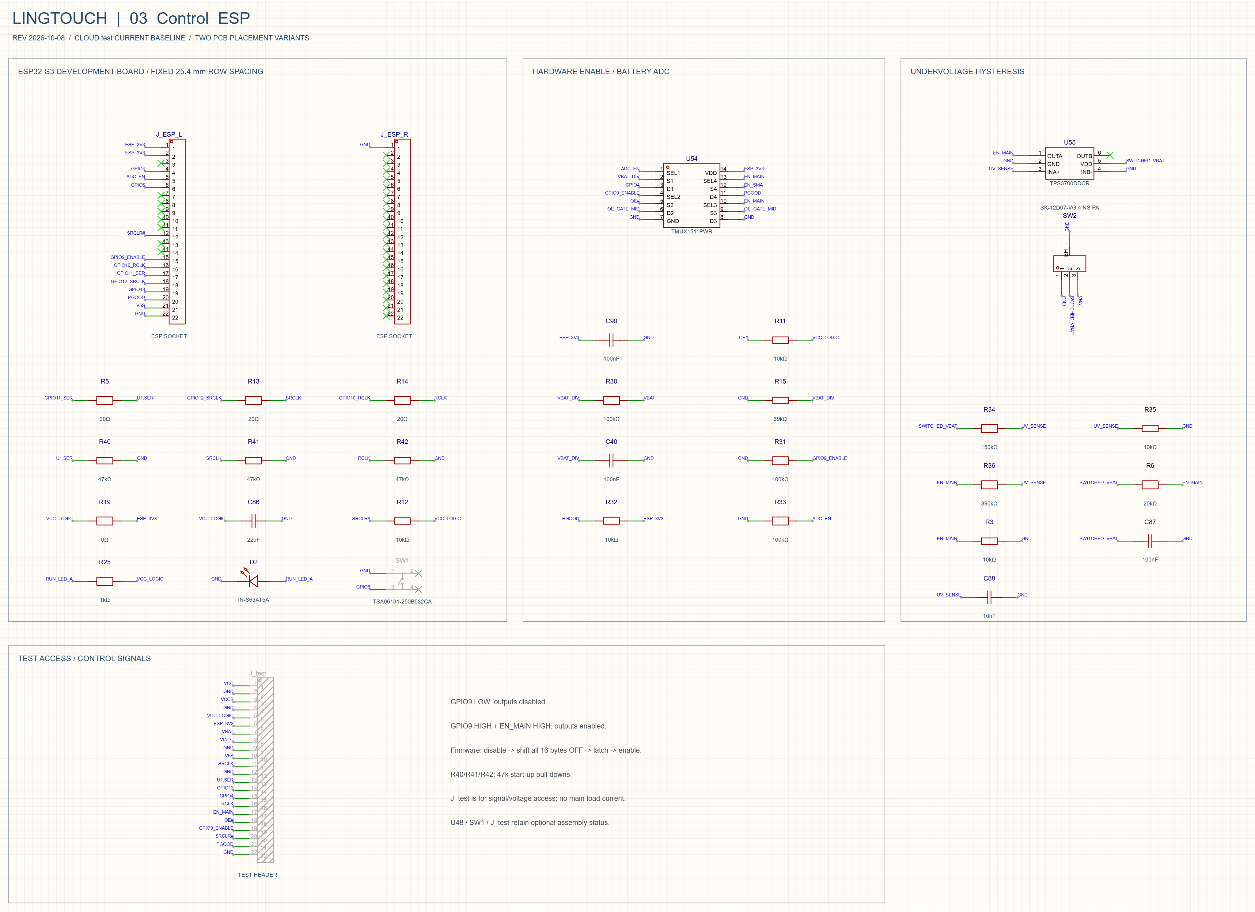
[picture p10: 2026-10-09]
PCB_REDESIGN_2026-10-08/schematic_3-03_Control_ESP.png

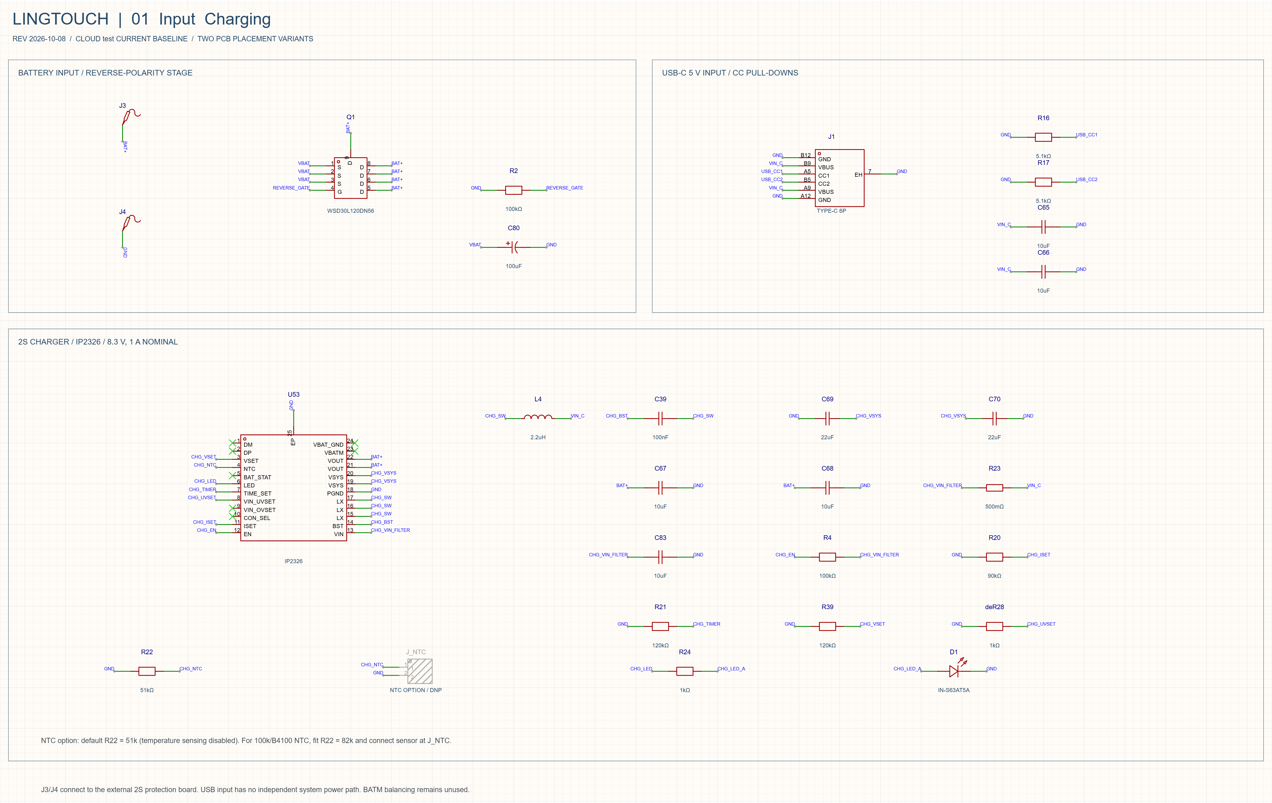
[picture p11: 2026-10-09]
PCB_REDESIGN_2026-10-08/schematic_1-01_Input_Charging.png

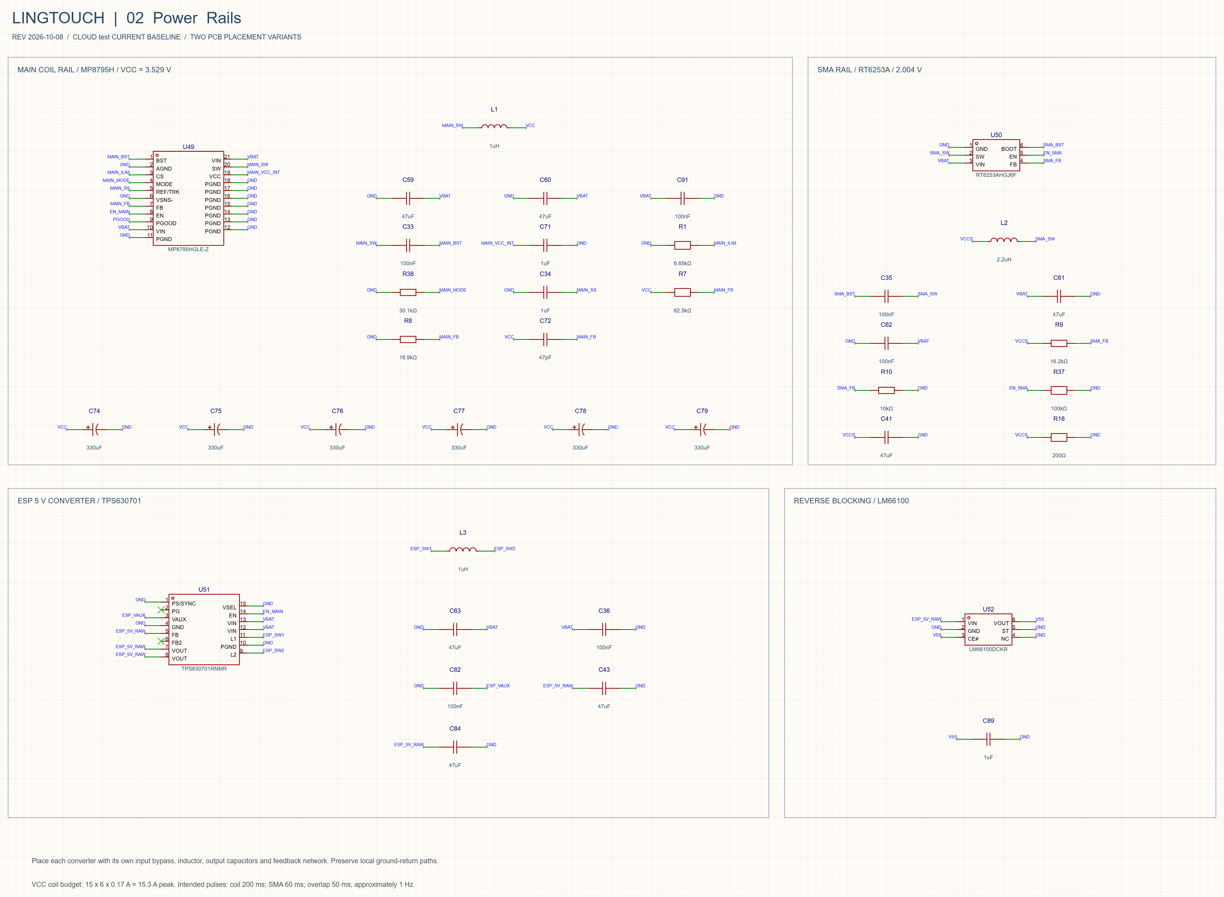
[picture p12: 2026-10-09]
PCB_REDESIGN_2026-10-08/schematic_2-02_Power_Rails.png

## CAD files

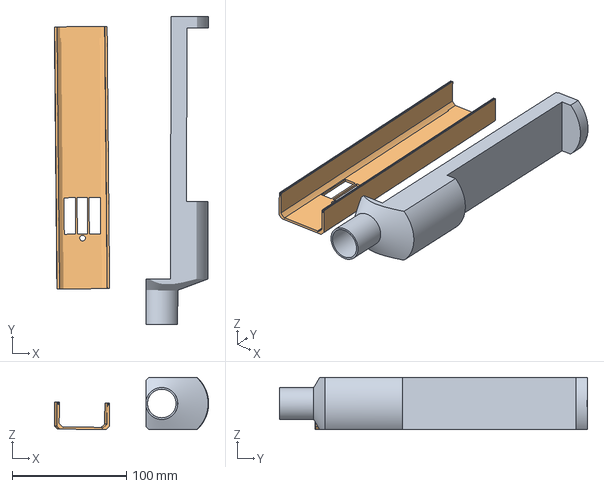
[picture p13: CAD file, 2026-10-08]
3mf/Handle/Handle_Print.3mf
135.3 x 270.2 x 46.0 mm
零件2.STEP
零件1.STEP

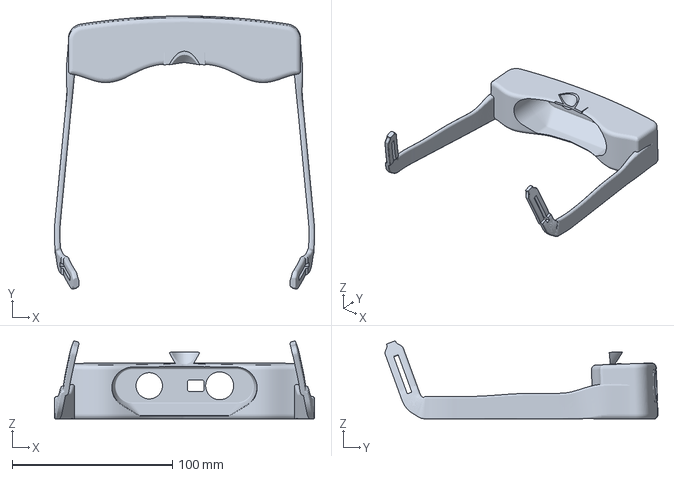
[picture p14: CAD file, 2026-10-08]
3mf/Headset_Inputs/Front_CS30_Mount_Final.3mf
162.5 x 170.5 x 48.6 mm

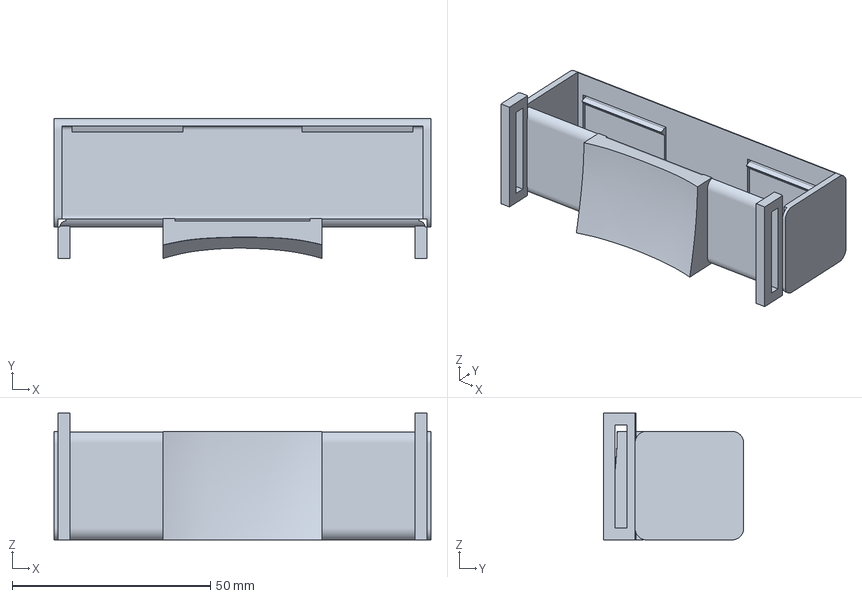
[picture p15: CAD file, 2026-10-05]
3mf/Headset_Rear/revised/Rear_Revised_Print_Ready.3mf
95.0 x 35.4 x 32.0 mm

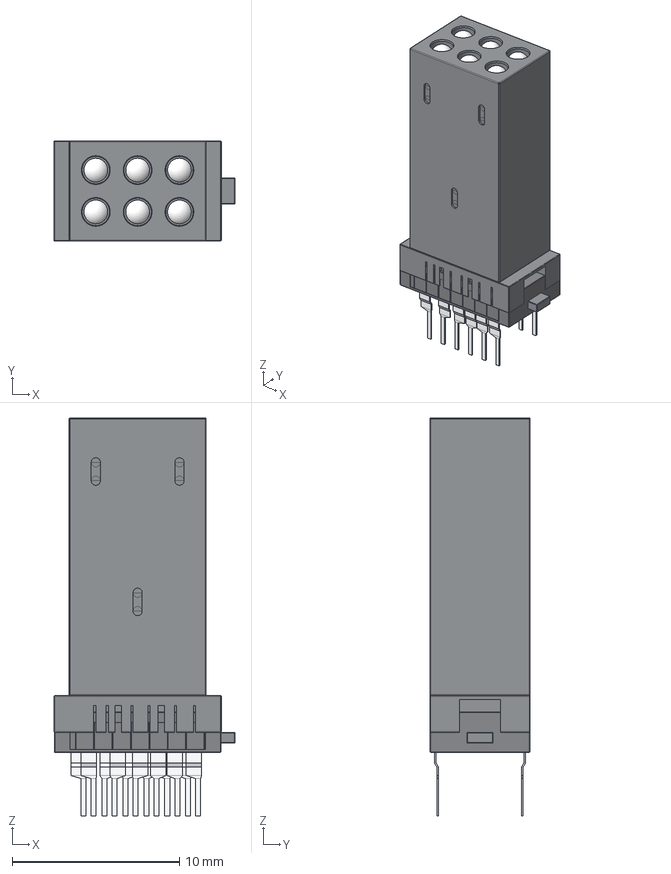
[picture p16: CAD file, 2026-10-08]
BrailleModule/BrailleModule.step
10.8 x 6.00 x 23.8 mm
Housing
Base_Collar
Base_Insert
Orientation_Tab
Pin_01
Pin_02
Pin_03
Pin_04
Pin_05
Pin_06
Pin_07
Pin_08
Pin_09
Pin_10
Pin_11
Pin_12
Dot_1
Dot_2
Dot_3
Dot_4
Dot_5
Dot_6

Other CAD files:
3mf/Headset_Rear/revised/Rear_Revised_Wearing.3mf
BrailleModule/BrailleModule.blend
BrailleModule_Video/ArrayPreview/EnclosedArray.blend
BrailleModule_Video/ArrayPreview/ModuleArray.blend
BrailleModule_Video/BrailleModule.blend
BrailleModule_Video/MotionPreview/AppearanceStudy.blend
BrailleModule_Video/MotionPreview/ModuleMotion.blend
BrailleModule_Video/PhotoStudy/ReferenceStudy.blend

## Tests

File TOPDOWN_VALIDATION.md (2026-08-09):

# 俯视栅格管线 — 标定与验证记录

`topdown_pipeline.py`（核心：backproject → 地面拟合 → 高度过滤 → 10×9俯视栅格）+
`validate_distance.py`（批量跑测试集，对比估距 vs 卷尺真实距离）+
`check_balloon_depth.py`（直接在深度图上采样气球像素区 vs 背景，判断气球是否可辨认）。

用官方 `Depth-Anything-V2/metric_depth/run.py --save-numpy` 产出的米制深度 `.npy` 作为输入。

## 标定

拍一张正对着已知宽度物体（门/柜）、已知距离的照片，量出物体在照片里的像素宽，代入：

```
fx = px × dist(m) / real_width(m)
```

**当前值：fx = 3260px**（复测：门扇 1467px @ 3072宽基准 × 2.0m / 0.90m ≈ 3260px，与 Mate 50 Pro 主摄
27mm 等效焦距理论值偏差约6%，量级吻合，标定已确认，无需重拍）。

## 测试集协议

同一场地、实验用的胸挂高度和角度拍 8-10 张，每张记录真实距离：空场×2、椅子在若干已知距离、
椅子贴墙、悬挂/地面物体×2、混合场景。图片放 `pics/`，跑 `run.py` 前建议先把中文文件名复制成
ASCII 名（`pics/ascii/`）——Git Bash 传中文参数给 Windows Python 会把 argv 乱码掉，`cv2.imread`
读不到文件，且报错信息本身也是乱码，容易误判成别的问题。复制脚本模板见 `prep_new_pics.py`
（在 Python 文件内部写死中文路径字符串再用 `shutil.copy2`，不经过命令行参数，就不会乱码）。

## 地面拟合算法（`ransac_ground`，两轮迭代 → 三轮迭代 + 非对称容差）

1. 取画面底部 `GROUND_IMG_FRAC` 比例的点作候选（**0.45 → 0.25**，比例越大，近距离物体越容易占满候选带底部、被误拟合进地面）。
2. RANSAC 粗定位平面（300次随机3点采样取最大共识）。
3. 最小二乘精修一次（3×3 协方差矩阵最小特征值方向）。
4. **REFIT_ROUNDS=3** 轮迭代剔除+精修：每轮用当前平面重新计算全部候选点的**带符号**残差，非对称剔除——
   地面以下容忍到 **-15cm**（黑布/地毯褶皱），地面以上只容忍 **+5cm** 就剔除（专门甩掉椅子腿这类贴地但更高的点）。

## 尺度锚定（`validate_distance.py`）

胸挂实测高度 `CAM_H_TRUE = 1.40m`。流程：原始深度先拟合一次地面拿到 `cam_h_raw` →
`scale = 1.40 / cam_h_raw` → 深度整体乘 scale → 重新走一遍完整流程（拟合出的 cam_h
应精确回到 1.40，作为交叉验证）。

**健康指标**：每批照片汇总 `scale` 的离散度（CV = std/mean）。同一个地面场景下 scale
理论上应该高度一致——**CV < 10% 才算地面拟合干净**，否则说明不同帧的地面拟合互相不一致
（材质/光照/近处物体污染都可能是原因），后面所有基于该 scale 的结论都不可信。

## 当前结果（黑布地面测试集，8张，fx=3260，两轮→三轮+非对称收紧后）

| 场景 | cam_h_raw | scale | 估距 | 真实 | 误差 |
|---|---|---|---|---|---|
| 空场1/2 | 1.57 | 0.892 | — | — | — |
| 椅子2m | 2.30 | 0.609 | 1.66 | 2.00 | -17.0% |
| 椅子3m | 2.05 | 0.684 | 2.58 | 3.00 | -14.0% |
| 椅子4m | 2.16 | 0.649 | 3.50 | 4.00 | -12.5% |
| 椅子5m | 1.82 | 0.770 | 4.09 | 5.00 | -18.2% |

**`scale` CV = 14.9%，超过10%健康线，判定这批数据的地面拟合不一致。**

**关键发现：把候选带从45%收紧到25% + 非对称[-15,+5]cm剔除 + 3轮迭代，结果几乎没变**
（cam_h_raw 2.31→2.30，2.08→2.05，2.18→2.16，1.85→1.82，全部原地不动，chair_5m
反而从 -9%误差恶化到 -18%）。RANSAC 本身的内点率全程 98-100%——说明候选带里的点
**本来就高度自洽地支持同一个（偏高的）平面**，不是"椅子腿混进候选带被平均掉"这种可以靠
调阈值解决的问题。这把嫌疑从"候选点选取算法"转向"整个候选带的深度值本身就有系统性偏差"，
和气球测试的发现（近距离~1-2m处 metric depth 绝对尺度明显失准，见下）指向同一个方向：
**可能是黑色反光/褶皱塑料布这种材质本身让 Depth Anything V2 在近距离测不准，不是俯视管线算法的锅。**

## 决定性对照实验结果（2026-08-09，结论：黑色材质是主因，基本坐实）

Hsinlung 补拍了3张照片（相机高度同样约1.4m），放进 `pics/`（原文件名带空格和中文，脚本跑之前先用
`prep_new_pics.py` 复制成 ASCII 名进 `pics/ascii/`）：

- `空场 n.jpg` → `empty3.jpg`
- `椅子3m n.jpg` → `chair_3m_plain.jpg`
- `气球1m n.jpg` → `balloon_1m_plain.jpg`

**重要：这三张照片的地面不是均匀的"普通地面"**，实际是浅蓝色环氧地坪（画面中段，反光但不是黑色）+
近处/右侧一块深色橡胶垫（带白色划线标记，肉眼看颜色深、材质和黑布类似）。这个混合场地反而成了
一次很干净的对照实验，因为同一张照片里同时有"浅蓝地坪"和"深色材质"两种区域。

### 结果 1：物体测距精度——浅蓝地坪区域大幅改善

| 场景 | 地面材质 | cam_h_raw | scale | 估距 | 真实 | 误差% |
|---|---|---|---|---|---|---|
| 椅子3m（黑布） | 黑布 | 2.05 | 0.684 | 2.58 | 3.00 | **-14.0%** |
| 椅子3m（新拍） | 浅蓝地坪 | 2.04 | 0.685 | 2.94 | 3.00 | **-2.1%** |

椅子本身落在浅蓝地坪范围内（不挨着深色胶垫），估距误差从 -14% 降到 -2.1%，接近标定/量距误差量级。
`cam_h_raw`/`scale` 数值本身几乎没变（下面第3点解释原因），但这不影响物体本身的测距精度——说明
**只要目标物体所在的地面区域不是深色材质，物体的绝对深度就准。**

### 结果 2：气球测距——数值直接匹配俯仰几何预测，比黑布组好一个量级

气球是躺在地上的长条气球，标称水平距离1m，相机高度1.4m，如果模型深度是"点到相机的直线距离"
（而不是垂直地面的水平距离），几何预测值应该是 √(1.4² + 1²) ≈ **1.72m**，不是1m。

| 场景 | 地面材质 | 气球区中位深度 | 背景中位深度 | vs 1.72m几何预测 |
|---|---|---|---|---|
| 近气球（黑布组，标称1m） | 黑布 | 3.11m | 3.38m | 差 ~1.8x |
| 混合图气球（黑布组，标称1m） | 黑布 | 3.62m | 4.09m | 差 ~2.1x |
| 气球（新拍，标称1m） | 浅蓝地坪 | **1.63m** | 3.74m | **误差仅约-5%，直接对上** |

（bbox 选取：先用颜色阈值 R>G+15 & B>G+5 在原图上定位气球像素，人工核实后专门收在 x<2050 —— 确认
这段气球全程压在浅蓝地坪上、不挨深色胶垫交界处，避免材质混淆。）

浅蓝地坪上的气球深度几乎精确落在纯几何预测值上，这是本次对照实验里最干净的一个信号：
**Depth Anything V2 在浅蓝反光地坪上的绝对尺度是准的，问题确实出在黑色/深色地面材质本身。**

### 结果 3：但 `scale`/`cam_h_raw` 依然没回到 ~1.0——原因已查清，不是新问题

新拍两张的 `cam_h_raw`（2.04-2.11m）、`scale`（0.664-0.685）、CV（14.0%）几乎和黑布组（14.9%）
一样没改善，乍看像是"黑布假设被推翻"，但逐行检查了 `GROUND_IMG_FRAC=0.25` 对应的候选带
（画面底部25%，即 y∈[3072,4096]）在这两张新照片里实际落在什么材质上：

```
y=3000  RGB≈(120,161,185)  浅蓝地坪
y=3100  RGB≈(63,68,84)     已经是深色胶垫
y=3200~4000  RGB≈(60-80, 60-85, 70-90)  全程深色胶垫
```

**候选带的材质分界线正好卡在 y≈3100-3200，几乎等于25%候选带的起点（y=3072）**——也就是说，
这两张"对照组"照片里，RANSAC 用来拟合地面的候选点，几乎**全部落在画面最下方那条深色橡胶垫上**，
和浅蓝地坪基本没关系。黑布组的候选带同样是"最靠近相机的地面条带"，材质也是深色。两组的地面拟合
候选带材质其实是同一类问题（深色反光地面），只是这次深色区域缩小到了画面最下方一条，没有覆盖椅子
和气球所在的浅蓝区域——这正好解释了为什么**物体测距（结果1、2）大幅改善，而 `scale`/`cam_h_raw`
（依赖的是画面最下方candidate带）完全没变**：两者用的是不同区域的深度值，前者干净、后者依然踩坑。

**结论：不是"黑布假设被推翻"，反而是同一个假设在同一批数据里被双重验证**——深色材质区域的深度
不准（候选带→cam_h_raw/scale 依然偏），非深色区域的深度准（椅子、气球→误差大幅下降）。

### 总体判定

**黑色/深色反光地面材质导致 Depth Anything V2 近距离绝对尺度失准，这个假设成立**，俯视管线算法
本身（地面拟合、高度过滤、栅格化）没有问题——只要喂给它的深度输入本身是准的，管线输出就准
（椅子3m误差-2.1%已经证明）。

### 下一步（如果还想彻底坐实/量化，非必须）

1. 补拍一张**从头到尾（包括画面最下方25%候选带）都在浅色/非反光地面上**的照片（人站的位置要让
   深色胶垫完全不入镜，包括脚下），重新验证 `scale` 能否回到 ~1.0——这才是对"地面拟合算法本身"的
   干净测试，目前三次尝试（黑布组、新拍组）候选带都不巧踩在深色材质上。
2. 如果暂时没有更多拍摄机会，现有结果已经足够支撑"以后测试集/实际部署选普通浅色地面拍摄，避开
   黑色反光材质"这个操作结论，可以先按这个结论往下走（比如开始接入俯视栅格到实际胸挂设备），
   不必卡在这里继续拍照验证。

## 气球检测（`check_balloon_depth.py`）

气球是**躺在地上的长条气球**，不是悬挂物——不能用"离地高度窗口"筛选（最早的假设就是错的）。
直接在深度 `.npy` 上采样气球像素区 vs 紧邻背景区的中位深度：

| 场景 | 气球区中位深度 | 背景中位深度 | 差 |
|---|---|---|---|
| 近气球(标称1m) | 3.11m | 3.38m | -0.27m (-8.1%) |
| 远气球(标称2m) | 5.56m | 5.11m | +0.45m (+8.7%，方向反了，测不出来) |
| 混合图气球(标称1m) | 3.62m | 4.09m | -0.47m (-11.4%) |

两个近气球能看出"比背景近"的相对信号，但**绝对深度值离标称值差了约2-3倍**（1m测成3.1-3.6m），
这个量级不是俯仰角几何投影能解释的，指向 metric depth 模型近距离绝对尺度失准——见上面
"决定性对照实验"。

## 环境问题（重要，与算法本身无关，但会让人误判成算法 bug）

`lingtouch` conda 环境的 numpy **LAPACK 库整体损坏**：`np.linalg.{svd,eigh,inv,det}`
或任何 N≳1000 的矩阵-向量乘法（`@`/`np.dot`）调用都会**静默崩溃**（退出码127，无 traceback，
终端啥也不打印）。诊断过程见本文件对应的对话记录，简单说是逐层排除法：先怀疑内存爆炸
（SVD `full_matrices=True` 默认值确实有这个坑，已修），修完还是崩，最后发现连
`np.linalg.inv(np.eye(3))` 都崩，才确认是 LAPACK 本身坏了，跟数组大小/写法无关。

**影响范围不止这两个脚本**——matplotlib 画图（`savefig`）内部要算仿射变换矩阵的逆，
同样会崩，所以 `topdown_pipeline.py` 里 `--outdir` 那段四联图可视化目前跑不通。

**当前绕开方式**（已在 `topdown_pipeline.py` 里实现，不需要每次都注意，但改代码时如果
新加了矩阵运算要记得避开）：
- 大矩阵-向量乘法 → 手写 `matvec()`：`(mat * vec).sum(axis=1)`，逐元素乘加代替 BLAS gemv。
- 3×3 对称矩阵最小特征值方向（原来的 SVD/eigh）→ 手写 Cardano 解析解 `smallest_eigvec_3x3()`。
- 3×3 行列式 → 手写余子式展开 `_det3()`，不用 `np.linalg.det`。
- 小的向量-向量运算（`np.dot`/`np.cross`/`np.linalg.norm` 用在3元素向量上）不受影响，可以正常用。

**建议**：找时间重装这个 conda 环境的 numpy（或换个 BLAS 后端，比如强制装 OpenBLAS 而不是当前
这个坏掉的库），彻底解决，而不是每处新代码都要手写绕开。`np.show_config()` 显示的是
"blas: name blas, openblas configuration: unknown"，装的具体是什么后端没能确认。

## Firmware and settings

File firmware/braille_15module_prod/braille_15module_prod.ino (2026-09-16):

/*
 * 灵触·随行 — ESP32-S3 固件 (15模组正式版)
 * V2.8 — 新增每阶段帧内容串口打印，用于对照示波器核实实际发出的bit值
 *
 * 新增：refreshGrouped 每个阶段(A/B/C/D) sendRaw 之后打印本次实际发送的
 * 15字节帧（十六进制，SPI链序号，非物理位置pos）。用法：
 *   set N XX 触发一次刷新，串口会依次打印4行"[帧] A/B/C/D..."，
 *   对照示波器实测的那一路电压变化时刻，逐阶段核实固件到底发的是什么，
 *   不用再靠代码推理猜。frame[i] 是链序号i(0~14)的字节，某个物理位置pos
 *   对应的字节看 frame[posToChain[pos]]。
 *
 * V2.7 — 四阶段定义按无界人工确认修正
 *
 * 四阶段真实定义（无界确认，非代码字面推断）：
 *   A. 解锁：仅SMA通电，线圈不通
 *   B. 升起：SMA+线圈同时通电
 *   C. 稳定：SMA关闭，仅线圈保持通电
 *   D. 全断：线圈也关闭
 *
 * 变更（相对 V2.8）：
 *   - Phase B 由"仅线圈"改为"SMA+线圈同时"（bit6|0x40）
 *   - Phase C 由"同B"改为"仅线圈，SMA清0"（&0x3F）
 *   - Phase A/D 不变
 *
 * 变更（V2.8，相对 V2.5，仍保留）：
 *   - 删除 changeMask/risingMask 动态挑选变化模组的逻辑，每次触发全量刷新
 *   - refreshStep 默认值 NUM_MODULES(15)，一次性全部一起走完，不分批
 *   - posToChain 映射、bit remap（不需要）、GPIO/BLE/串口命令框架均未改
 *
 * 命令：
 *   hold N XX [T]   位置N(1-15)线圈按0xXX通电T秒(1-10,默认5)，SMA不动
 *   ex N XX [C]     位置N按0xXX做解锁锻炼循环C次(1-30,默认10)
 *   stop            立即全部断电（同 clear 但不改 brailleData）
 *
 * ex 每循环节奏（共1.3秒/次）：
 *   [SMA+线圈 400ms 解锁窗口] [仅线圈 300ms 保持] [全断 600ms 散热]
 */

#include <SPI.h>
#include <BLEDevice.h>
#include <BLEServer.h>
#include <BLEUtils.h>
#include <BLE2902.h>

// ═══════════════════════════════════════
//  硬件引脚
// ═══════════════════════════════════════

#define PIN_SER    11
#define PIN_SRCLK  12
#define PIN_RCLK   10
#define PIN_OE      9
#define PIN_SRCLR   8
#define PIN_BTN     6

// ═══════════════════════════════════════
//  系统参数
// ═══════════════════════════════════════

#define NUM_MODULES     15
#define FRAME_LEN       15
#define PINS_PER_MOD    6

#define DEFAULT_PHASE_A   10
#define DEFAULT_PHASE_B   50
#define DEFAULT_PHASE_C  150
#define DEFAULT_PHASE_D   10

// 默认一次性全部15个一起走完，不分批（对齐"不分批"要求；见文件头说明，需确认）
#define DEFAULT_STEP      NUM_MODULES

#define BTN_DEBOUNCE_MS   200
#define MAX_PHASE_MS      500

// ═══════════════════════════════════════
//  模式定义
// ═══════════════════════════════════════

enum DeviceMode : uint8_t {
  MODE_RAPID_AVOID = 0x01,
  MODE_LOCAL_ZOOM  = 0x02
};

// ═══════════════════════════════════════
//  FFE3 Notify 事件类型
// ═══════════════════════════════════════

#define EVT_REFRESH_DONE  0x01
#define EVT_MODE_SWITCH   0x02
#define EVT_BATTERY       0x03
#define EVT_SCAN_REQUEST  0x04

// ═══════════════════════════════════════
//  物理位置 → SPI字节索引 映射
// ═══════════════════════════════════════

uint8_t posToChain[NUM_MODULES] = {
  14, 13, 12, 11, 10,
   9,  8,  7,  6,  5,
   4,  3,  2,  1,  0,
};

uint8_t deadDots[NUM_MODULES] = {
  0x00,0x00,0x00,0x00,0x00,
  0x00,0x00,0x00,0x00,0x00,
  0x00,0x00,0x00,0x00,0x00,
};

// ═══════════════════════════════════════
//  运行时参数
// ═══════════════════════════════════════

int phaseA = DEFAULT_PHASE_A;
int phaseB = DEFAULT_PHASE_B;
int phaseC = DEFAULT_PHASE_C;
int phaseD = DEFAULT_PHASE_D;
int refreshStep = DEFAULT_STEP;

uint16_t moduleMask = 0x7FFF;

// ═══════════════════════════════════════
//  状态变量
// ═══════════════════════════════════════

uint8_t brailleData[NUM_MODULES] = {0};
uint8_t prevData[NUM_MODULES] = {0};

volatile bool newDataReady = false;
volatile bool forceRefresh = false;
volatile bool refreshComplete = true;

DeviceMode currentMode = MODE_RAPID_AVOID;
bool rawMode = false;

volatile unsigned long lastBtnPress = 0;
volatile bool btnPressed = false;

volatile bool pendingNotify = false;
volatile uint8_t pendingNotifyType = 0;
volatile uint8_t pendingNotifyData = 0;

// ═══════════════════════════════════════
//  SPI
// ═══════════════════════════════════════

SPIClass *hspi = NULL;

void initSPI() {
  hspi = new SPIClass(HSPI);
  hspi->begin(PIN_SRCLK, -1, PIN_SER, -1);
  hspi->setFrequency(1000000);
  hspi->setDataMode(SPI_MODE0);
}

void initGPIO() {
  pinMode(PIN_RCLK,  OUTPUT);
  pinMode(PIN_OE,    OUTPUT);
  pinMode(PIN_SRCLR, OUTPUT);

  digitalWrite(PIN_RCLK,  HIGH);
  digitalWrite(PIN_OE,    HIGH);
  digitalWrite(PIN_SRCLR, HIGH);
}

void sendRaw(uint8_t *frame, size_t len) {
  digitalWrite(PIN_OE, LOW);
  digitalWrite(PIN_RCLK, LOW);
  hspi->transferBytes(frame, NULL, len);
  digitalWrite(PIN_RCLK, HIGH);
}

void allOff() {
  uint8_t f[FRAME_LEN] = {0};
  sendRaw(f, FRAME_LEN);
}

// 打印实际发送的帧内容，逐字节标出 bit6(SMA) 和 bit0-5(线圈)
// frame下标是posToChain之后的SPI链序号，不是物理位置pos；
// 需要看某个物理位置pos的值时，看 frame[posToChain[pos]]
void printFrame(const char *label, uint8_t *frame) {
  Serial.printf("[帧] %s: ", label);
  for (int i = 0; i < FRAME_LEN; i++) {
    Serial.printf("%02X ", frame[i]);
  }
  Serial.println();
}

// ═══════════════════════════════════════
//  分组刷新（V2.8：逐字对齐无界 send_braille_data_grouped）
//
//  与无界原代码的对应关系：
//    posData        ↔ data_array（30字节，此处15字节）
//    sentData[]     ↔ sent_data[]，基线，初始全0
//    offset/step    ↔ offset/step，从数组末端往前分组
//    A/B/C/D 四阶段 ↔ 无界文档 9.3 节 A/B/C/D 完全一致
//    Data_Rev_Finish==true 打断 ↔ newDataReady==true 打断
//  唯一差异：不做 bit remap（已确认板子接线干净，无需 order[]/order_test[]）
// ═══════════════════════════════════════

void refreshGrouped(uint8_t *posData) {
  uint8_t sentData[FRAME_LEN] = {0};   // 对应无界 sent_data[]，初始全0
  uint8_t frame[FRAME_LEN];
  refreshComplete = false;

  int step = min(refreshStep, (int)NUM_MODULES);
  if (step < 1) step = 1;

  int offset = NUM_MODULES - step;   // 从数组末端开始，对应无界逻辑

  while (offset >= 0) {
    if (newDataReady) {
      // 对应无界: Data_Rev_Finish==true → 立即中止本次刷新并返回
      memset(frame, 0x00, FRAME_LEN);
      sendRaw(frame, FRAME_LEN);
      refreshComplete = true;
      return;
    }

    int batchEnd = min(offset + step, (int)NUM_MODULES);

    // A. 解锁：仅打开SMA，线圈不通（本组）
    memset(frame, 0x00, FRAME_LEN);
    for (int i = offset; i < batchEnd; i++) {
      frame[posToChain[i]] = 0x40;
    }
    sendRaw(frame, FRAME_LEN);
    vTaskDelay(pdMS_TO_TICKS(phaseA));

    // B. 升起：SMA+线圈同时通电（本组，bit6|0x40），其余为sentData基线
    memset(frame, 0x00, FRAME_LEN);
    for (int i = 0; i < NUM_MODULES; i++) frame[posToChain[i]] = sentData[i];
    for (int i = offset; i < batchEnd; i++) {
      frame[posToChain[i]] = (posData[i] & 0x3F) | 0x40;
    }
    sendRaw(frame, FRAME_LEN);
    vTaskDelay(pdMS_TO_TICKS(phaseB));

    // C. 稳定：关闭SMA，仅保留线圈通电（本组，&0x3F清bit6）
    memset(frame, 0x00, FRAME_LEN);
    for (int i = 0; i < NUM_MODULES; i++) frame[posToChain[i]] = sentData[i];
    for (int i = offset; i < batchEnd; i++) {
      frame[posToChain[i]] = posData[i] & 0x3F;
    }
    sendRaw(frame, FRAME_LEN);
    vTaskDelay(pdMS_TO_TICKS(phaseC));

    // D. 关闭输出（真发全0帧，V2.5遗漏了这一帧，此处补上）
    memset(frame, 0x00, FRAME_LEN);
    sendRaw(frame, FRAME_LEN);
    vTaskDelay(pdMS_TO_TICKS(phaseD));

    // 本组sentData复位为0（对应无界 sent_data[offset+i]=0x00）
    for (int i = offset; i < batchEnd; i++) {
      sentData[i] = 0x00;
    }

    offset -= step;
  }

  refreshComplete = true;
}

// ═══════════════════════════════════════
//  BLE
// ═══════════════════════════════════════

#define SERVICE_UUID        "0000FFE0-0000-1000-8000-00805F9B34FB"
#define CHAR_BRAILLE_UUID   "0000FFE1-0000-1000-8000-00805F9B34FB"
#define CHAR_STATUS_UUID    "0000FFE3-0000-1000-8000-00805F9B34FB"

BLEServer *pServer = NULL;
BLECharacteristic *pBrailleChar = NULL;
BLECharacteristic *pStatusChar = NULL;
bool deviceConnected = false;
bool oldDeviceConnected = false;

void notifyStatus(uint8_t eventType, uint8_t eventData);

class ServerCB : public BLEServerCallbacks {
  void onConnect(BLEServer *s) override {
    deviceConnected = true;
    Serial.println("[BLE] 已连接");
    notifyStatus(EVT_MODE_SWITCH, currentMode);
  }
  void onDisconnect(BLEServer *s) override {
    deviceConnected = false;
    Serial.println("[BLE] 已断开");
  }
};

class BrailleCB : public BLECharacteristicCallbacks {
  void onWrite(BLECharacteristic *c) override {
    String rx = c->getValue();
    if (rx.length() != NUM_MODULES) {
      Serial.printf("[BLE] 长度错误: %d (需要%d)\n", rx.length(), NUM_MODULES);
      return;
    }
    for (int i = 0; i < NUM_MODULES; i++) {
      brailleData[i] = ((uint8_t)rx[i]) & 0x3F;
    }
    newDataReady = true;
    Serial.println("[BLE] 收到数据帧");
  }
};

void notifyStatus(uint8_t eventType, uint8_t eventData) {
  if (!deviceConnected) return;
  uint8_t payload[2] = {eventType, eventData};
  pStatusChar->setValue(payload, 2);
  pStatusChar->notify();
  Serial.printf("[BLE] notify: type=0x%02X data=0x%02X\n", eventType, eventData);
}

void queueNotify(uint8_t eventType, uint8_t eventData) {
  pendingNotifyType = eventType;
  pendingNotifyData = eventData;
  pendingNotify = true;
}

void dispatchNotify() {
  if (pendingNotify) {
    pendingNotify = false;
    notifyStatus(pendingNotifyType, pendingNotifyData);
  }
}

void initBLE() {
  BLEDevice::init("LingChu-Tactile");
  BLEDevice::setMTU(64);

  pServer = BLEDevice::createServer();
  pServer->setCallbacks(new ServerCB());

  BLEService *svc = pServer->createService(SERVICE_UUID);

  pBrailleChar = svc->createCharacteristic(
    CHAR_BRAILLE_UUID,
    BLECharacteristic::PROPERTY_WRITE |
    BLECharacteristic::PROPERTY_WRITE_NR
  );
  pBrailleChar->setCallbacks(new BrailleCB());

  pStatusChar = svc->createCharacteristic(
    CHAR_STATUS_UUID,
    BLECharacteristic::PROPERTY_NOTIFY
  );
  pStatusChar->addDescriptor(new BLE2902());

  svc->start();

  BLEAdvertising *adv = BLEDevice::getAdvertising();
  adv->addServiceUUID(SERVICE_UUID);
  adv->setScanResponse(true);
  adv->setMinPreferred(0x06);
  adv->setMaxPreferred(0x12);
  BLEDevice::startAdvertising();

  Serial.println("[BLE] 广播中: LingChu-Tactile");
}

// ═══════════════════════════════════════
//  按钮处理
// ═══════════════════════════════════════

void IRAM_ATTR btnISR() {
  unsigned long now = millis();
  if (now - lastBtnPress > BTN_DEBOUNCE_MS) {
    lastBtnPress = now;
    btnPressed = true;
  }
}

void initButton() {
  pinMode(PIN_BTN, INPUT_PULLUP);
  attachInterrupt(digitalPinToInterrupt(PIN_BTN), btnISR, FALLING);
  Serial.println("[BTN] GPIO6 就绪 (内部上拉, 按下拉低)");
}

void handleButton() {
  if (!btnPressed) return;
  btnPressed = false;
  Serial.println("[SCAN]");
  notifyStatus(EVT_SCAN_REQUEST, currentMode);
}

// ═══════════════════════════════════════
//  BLE重连管理
// ═══════════════════════════════════════

void manageBLE() {
  if (!deviceConnected && oldDeviceConnected) {
    delay(500);
    pServer->startAdvertising();
    Serial.println("[BLE] 断连，重新广播");
    oldDeviceConnected = false;
  }
  if (deviceConnected && !oldDeviceConnected) {
    oldDeviceConnected = true;
  }
}

// ═══════════════════════════════════════
//  驱动任务（核心1）
//  V2.8: 不再做changeMask变化检测，每次触发都全量刷新（对齐无界逻辑）
// ═══════════════════════════════════════

void driveTask(void *pvParam) {
  while (true) {
    if (newDataReady) {
      newDataReady = false;
      for (int i = 0; i < NUM_MODULES; i++) brailleData[i] &= ~deadDots[i];

      Serial.println("[刷新] 全量刷新（照抄无界逻辑，不做变化检测）");
      refreshGrouped(brailleData);
      memcpy(prevData, brailleData, NUM_MODULES);

      queueNotify(EVT_REFRESH_DONE, 0x00);
    }

    if (forceRefresh) {
      forceRefresh = false;
      refreshGrouped(brailleData);
      memcpy(prevData, brailleData, NUM_MODULES);
    }

    vTaskDelay(pdMS_TO_TICKS(20));
  }
}

// ═══════════════════════════════════════
//  串口命令
// ═══════════════════════════════════════

void printHelp() {
  Serial.println("=== 灵触·随行 15模组驱动 V2.8 ===");
  Serial.println("命令:");
  Serial.println("  help              显示帮助");
  Serial.println("  test              全部凸起");
  Serial.println("  clear             全部复位");
  Serial.println("  set N XX          位置N(1-15)设为0xXX");
  Serial.println("  row R XX          第R行(1-5)设为0xXX");
  Serial.println("  col C XX          第C列(1-3)设为0xXX");
  Serial.println("  mask 0xNNNN       设模组掩码");
  Serial.println("  step N            设分组步长(1-15，默认15=不分批)");
  Serial.println("  timing A B C D    设四相时序(ms)");
  Serial.println("  mode              查看/切换模式");
  Serial.println("  print             打印当前状态");
  Serial.println("  demo              演示动画");
  Serial.println("  raw on/off        二进制帧模式");
  Serial.println("  refresh           强制重刷");
  Serial.println("--- 诊断命令 ---");
  Serial.println("  hold N XX [T]     线圈通电T秒(默认5,1-10)，SMA不动");
  Serial.println("    例: hold 6 02 8  → M6仅点2线圈通电8秒");
  Serial.println("  ex N XX [C]       解锁锻炼循环C次(默认10,1-30)");
  Serial.println("    例: ex 6 3F 20   → M6全部点锻炼20次");
  Serial.println("    解锁窗口(串口打印'解锁'时)用指腹按压再快速抬起");
  Serial.println("  stop              立即全部断电（不改点阵数据）");
}

void printStatus() {
  Serial.println("--- 当前状态 ---");
  Serial.printf("模式: %s (0x%02X)\n",
    (currentMode == MODE_RAPID_AVOID) ? "RAPID_AVOID" : "LOCAL_ZOOM",
    currentMode);
  Serial.printf("掩码: 0x%04X\n", moduleMask);
  Serial.printf("步长: %d\n", refreshStep);
  Serial.printf("时序: A=%d B=%d C=%d D=%d ms\n", phaseA, phaseB, phaseC, phaseD);
  Serial.printf("BLE: %s\n", deviceConnected ? "已连接" : "未连接");
  Serial.printf("RAW: %s\n", rawMode ? "开启" : "关闭");
  Serial.println("点阵数据:");
  for (int row = 0; row < 5; row++) {
    Serial.print("  ");
    for (int col = 0; col < 3; col++) {
      int pos = row * 3 + col;
      bool active = moduleMask & (1 << pos);
      if (active) {
        Serial.printf("[%2d]=0x%02X  ", pos + 1, brailleData[pos]);
      } else {
        Serial.printf("[%2d]=----  ", pos + 1);
      }
    }
    Serial.println();
  }
}

void runDemo() {
  Serial.println("[DEMO] 逐模组点亮...");
  for (int i = 0; i < NUM_MODULES; i++) {
    if (!(moduleMask & (1 << i))) continue;
    memset(brailleData, 0x00, NUM_MODULES);
    brailleData[i] = 0x3F;
    newDataReady = true;
    while (!refreshComplete) vTaskDelay(pdMS_TO_TICKS(10));
    vTaskDelay(pdMS_TO_TICKS(300));
  }

  Serial.println("[DEMO] 逐行点亮...");
  for (int row = 1; row <= 5; row++) {
    memset(brailleData, 0x00, NUM_MODULES);
    for (int col = 0; col < 3; col++) {
      int pos = (row - 1) * 3 + col;
      if (moduleMask & (1 << pos)) {
        brailleData[pos] = 0x3F;
      }
    }
    newDataReady = true;
    while (!refreshComplete) vTaskDelay(pdMS_TO_TICKS(10));
    vTaskDelay(pdMS_TO_TICKS(500));
  }

  Serial.println("[DEMO] 全部凸起");
  for (int i = 0; i < NUM_MODULES; i++) brailleData[i] = 0x3F;
  newDataReady = true;
  while (!refreshComplete) vTaskDelay(pdMS_TO_TICKS(10));
  vTaskDelay(pdMS_TO_TICKS(1000));

  memset(brailleData, 0x00, NUM_MODULES);
  newDataReady = true;
  Serial.println("[DEMO] 结束");
}

// ── 诊断：hold ──
// 阻塞执行，完成后 allOff()，不修改 brailleData/prevData
void cmdHold(int pos, uint8_t val, int sec) {
  uint8_t frame[FRAME_LEN] = {0};
  frame[posToChain[pos - 1]] = val & 0x3F;
  sendRaw(frame, FRAME_LEN);
  Serial.printf("M%d 线圈=0x%02X 通电中... %d秒\n", pos, val & 0x3F, sec);
  for (int s = sec; s > 0; s--) {
    Serial.printf("  %d\n", s);
    delay(1000);
  }
  allOff();
  Serial.println("已断电");
}

// ── 诊断：ex ──
// 阻塞执行，完成后 allOff()，不修改 brailleData/prevData
void cmdEx(int pos, uint8_t val, int cycles) {
  uint8_t frame[FRAME_LEN];
  Serial.printf("M%d 锻炼 0x%02X × %d次\n", pos, val & 0x3F, cycles);
  for (int c = 0; c < cycles; c++) {
    // 阶段1: SMA+线圈, 400ms
    memset(frame, 0, FRAME_LEN);
    frame[posToChain[pos - 1]] = (val & 0x3F) | 0x40;
    sendRaw(frame, FRAME_LEN);
    Serial.printf("  [%d/%d] 解锁 ← 现在按压抬起\n", c + 1, cycles);
    delay(400);
    // 阶段2: 仅线圈, 300ms
    frame[posToChain[pos - 1]] = val & 0x3F;
    sendRaw(frame, FRAME_LEN);
    delay(300);
    // 阶段3: 全断, 600ms
    allOff();
    delay(600);
  }
  allOff();
  Serial.println("锻炼完成，已断电");
}

void processSerial() {
  if (!Serial.available()) return;

  if (rawMode) {
    if (Serial.available() >= NUM_MODULES) {
      Serial.readBytes(brailleData, NUM_MODULES);
      for (int i = 0; i < NUM_MODULES; i++) brailleData[i] &= 0x3F;
      newDataReady = true;
    }
    while (Serial.available() && Serial.peek() == '\n') Serial.read();
    return;
  }

  String line = Serial.readStringUntil('\n');
  line.trim();
  if (line.length() == 0) return;

  Serial.printf("> %s\n", line.c_str());

  if (line == "help") {
    printHelp();
  }
  else if (line == "test") {
    for (int i = 0; i < NUM_MODULES; i++) brailleData[i] = 0x3F;
    newDataReady = true;
    Serial.println("全部凸起");
  }
  else if (line == "clear") {
    memset(brailleData, 0x00, NUM_MODULES);
    newDataReady = true;
    Serial.println("全部复位");
  }
  else if (line == "stop") {
    allOff();
    Serial.println("已全部断电");
  }
  else if (line == "refresh") {
    forceRefresh = true;
    Serial.println("强制刷新");
  }
  else if (line == "print") {
    printStatus();
  }
  else if (line == "demo") {
    runDemo();
  }
  else if (line == "mode") {
    if (currentMode == MODE_RAPID_AVOID) {
      currentMode = MODE_LOCAL_ZOOM;
    } else {
      currentMode = MODE_RAPID_AVOID;
    }
    const char *modeName = (currentMode == MODE_RAPID_AVOID) ? "RAPID_AVOID" : "LOCAL_ZOOM";
    Serial.printf("模式切换 → %s\n", modeName);
    notifyStatus(EVT_MODE_SWITCH, currentMode);
  }
  else if (line.startsWith("set ")) {
    int pos; unsigned int val;
    if (sscanf(line.c_str(), "set %d %x", &pos, &val) == 2) {
      if (pos >= 1 && pos <= NUM_MODULES) {
        brailleData[pos - 1] = val & 0x3F;
        newDataReady = true;
        Serial.printf("位置%d = 0x%02X\n", pos, val & 0x3F);
      } else {
        Serial.println("位置范围: 1-15");
      }
    } else {
      Serial.println("格式: set N XX");
    }
  }
  else if (line.startsWith("row ")) {
    int row; unsigned int val;
    if (sscanf(line.c_str(), "row %d %x", &row, &val) == 2) {
      if (row >= 1 && row <= 5) {
        for (int col = 0; col < 3; col++) {
          brailleData[(row - 1) * 3 + col] = val & 0x3F;
        }
        newDataReady = true;
        Serial.printf("第%d行 = 0x%02X\n", row, val & 0x3F);
      } else {
        Serial.println("行范围: 1-5");
      }
    } else {
      Serial.println("格式: row R XX");
    }
  }
  else if (line.startsWith("col ")) {
    int col; unsigned int val;
    if (sscanf(line.c_str(), "col %d %x", &col, &val) == 2) {
      if (col >= 1 && col <= 3) {
        for (int row = 0; row < 5; row++) {
          brailleData[row * 3 + (col - 1)] = val & 0x3F;
        }
        newDataReady = true;
        Serial.printf("第%d列 = 0x%02X\n", col, val & 0x3F);
      } else {
        Serial.println("列范围: 1-3");
      }
    } else {
      Serial.println("格式: col C XX");
    }
  }
  else if (line.startsWith("mask ")) {
    unsigned int val;
    if (sscanf(line.c_str(), "mask %x", &val) == 1) {
      moduleMask = val & 0x7FFF;
      Serial.printf("掩码 = 0x%04X\n", moduleMask);
      printStatus();
    } else {
      Serial.println("格式: mask 0xNNNN");
    }
  }
  else if (line.startsWith("step ")) {
    int val;
    if (sscanf(line.c_str(), "step %d", &val) == 1 && val >= 1 && val <= NUM_MODULES) {
      refreshStep = val;
      Serial.printf("步长 = %d\n", refreshStep);
      if (refreshStep < NUM_MODULES) {
        Serial.println("ℹ 提示: 步长<15会分批处理，各批之间D阶段会全部断电（含已抬起的批次），不再是全部同时通电");
      }
    } else {
      Serial.println("格式: step N (1-15)");
    }
  }
  else if (line.startsWith("timing ")) {
    int a, b, c, d;
    if (sscanf(line.c_str(), "timing %d %d %d %d", &a, &b, &c, &d) == 4) {
      a = min(a, (int)MAX_PHASE_MS);
      b = min(b, (int)MAX_PHASE_MS);
      c = min(c, (int)MAX_PHASE_MS);
      d = min(d, (int)MAX_PHASE_MS);
      phaseA = max(1, a); phaseB = max(1, b); phaseC = max(1, c); phaseD = max(1, d);
      Serial.printf("时序 = A:%d B:%d C:%d D:%d ms\n", phaseA, phaseB, phaseC, phaseD);
    } else {
      Serial.println("格式: timing A B C D");
    }
  }
  else if (line == "raw on") {
    rawMode = true;
    Serial.println("进入 raw 模式 (15字节二进制帧)");
  }
  else if (line == "raw off") {
    rawMode = false;
    Serial.println("退出 raw 模式");
  }
  // ── 诊断命令 ──
  else if (line.startsWith("hold ")) {
    int pos; unsigned int val; int sec = 5;
    int n = sscanf(line.c_str(), "hold %d %x %d", &pos, &val, &sec);
    if (n >= 2 && pos >= 1 && pos <= NUM_MODULES) {
      sec = constrain(sec, 1, 10);
      cmdHold(pos, (uint8_t)val, sec);
    } else {
      Serial.println("格式: hold N XX [T]");
    }
  }
  else if (line.startsWith("ex ")) {
    int pos; unsigned int val; int cycles = 10;
    int n = sscanf(line.c_str(), "ex %d %x %d", &pos, &val, &cycles);
    if (n >= 2 && pos >= 1 && pos <= NUM_MODULES) {
      cycles = constrain(cycles, 1, 30);
      cmdEx(pos, (uint8_t)val, cycles);
    } else {
      Serial.println("格式: ex N XX [次数]");
    }
  }
  else {
    Serial.printf("未知命令: %s (输入help查看)\n", line.c_str());
  }
}

// ═══════════════════════════════════════
//  setup / loop
// ═══════════════════════════════════════

void setup() {
  Serial.begin(115200);
  delay(500);

  Serial.println();
  Serial.println("================================");
  Serial.println("  灵触·随行 15模组盲文驱动");
  Serial.println("  V2.8 — refreshGrouped逐字对齐无界结构");
  Serial.println("================================");

  initGPIO();
  initSPI();

  digitalWrite(PIN_SRCLR, LOW);
  delayMicroseconds(10);
  digitalWrite(PIN_SRCLR, HIGH);
  uint8_t zeroFrame[FRAME_LEN] = {0};
  sendRaw(zeroFrame, FRAME_LEN);
  digitalWrite(PIN_OE, LOW);
  Serial.println("[HW] 上电安全序列完成，输出已使能");

  initButton();
  initBLE();

  xTaskCreatePinnedToCore(
    driveTask,
    "DriveTask",
    4096,
    NULL,
    2,
    NULL,
    1
  );

  printHelp();
  Serial.println();
  Serial.printf("当前模式: RAPID_AVOID (0x%02X)\n", currentMode);
  Serial.printf("模组掩码: 0x%04X\n", moduleMask);
  Serial.printf("分组步长: %d (默认不分批)\n", refreshStep);
  Serial.println("按物理按钮触发扫描 | 串口输入 mode 切换模式");
  Serial.println();
}

void loop() {
  processSerial();
  handleButton();
  manageBLE();
  dispatchNotify();
  delay(10);
}

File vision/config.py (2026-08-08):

"""
LingTouch Companion — Vision Pipeline Configuration

Camera → Depth Estimation → Grid Mapping → Braille Frame
"""

# ── Camera ──────────────────────────────────────────────
CAMERA_INDEX = 0            # USB camera device index
CAMERA_WIDTH = 640
CAMERA_HEIGHT = 480
CAMERA_FPS = 15

# ── Depth Anything V2 ──────────────────────────────────
DEPTH_MODEL_SIZE = "small"  # "small" | "base" | "large"
# small: ~25M params, best for RPi 4/5
# base:  ~98M params, balanced
# large: ~335M params, best accuracy but needs GPU
DEPTH_INPUT_SIZE = (518, 518)  # model input resolution
USE_GPU = False             # True for CUDA, False for CPU (RPi default)

# ── Grid mapping ───────────────────────────────────────
# 9 cols × 10 rows = 90 cells = 15 modules × 6 SMA dots per module
# Each cell maps to one SMA dot (on/off)
GRID_COLS = 9               # horizontal: 9 SMA dot columns
GRID_ROWS = 10              # vertical: 10 SMA dot rows (top=farther → bottom=nearer)

# Region of Interest for image-plane pipeline
# (ignore sky at top, feet at bottom)
ROI_TOP_RATIO = 0.2
ROI_BOTTOM_RATIO = 0.1

# 设备贴身佩戴、摄像头朝外时，触点面朝向使用者，
# 和摄像头拍到的画面左右相反，需要镜像一次抵消。
MIRROR_HORIZONTAL = True

# ── XY Ground-plane projection ──────────────────────────
# Camera
CAM_HEIGHT_M = 1.20         # camera height above ground (meters)
CAM_FOV_H_DEG = 65          # horizontal field of view (degrees)
GROUND_CLEARANCE_M = 0.10   # obstacle = point is above ground + clearance (meters)

# XY grid cell size
XY_CELL_M = 0.50            # 50cm × 50cm per cell
XY_Y_NEAR_M = 0.3           # nearest forward distance
# XY_Y_FAR derived: XY_Y_NEAR + GRID_ROWS × XY_CELL_M
# X range derived: ±0.5 × GRID_COLS × XY_CELL_M

# ── Obstacle detection ──
# 曾经把这个从 85 降到 75 想压反光噪声，但代价太大：细长障碍物（比如实测用
# 的长条气球）本来就只占格子宽度一小部分，P75 要求 25% 的像素偏近，反而先
# 把这类物体自己的信号滤没了（扫参数验证：10px 宽气球在 P75 完全测不到，
# P85 才能稳定测到 4/90 点；同时 P85 下反光噪声场景仍然是 0/90，没有倒退）。
# 真正压反光噪声靠的是 grid_mapper.py 里更大的 OBSTACLE_MARGIN / 更高的
# 双阈值 Q85-Q72 / OBS_FLOOR，这几个不依赖"物体占格子多少比例"，所以放心
# 把这个改回 85。
CELL_OBS_PERCENTILE = 85
MIN_CELL_COVERAGE = 0.30
# 22 太多：同时凸起这么多点画面/触感都乱。配合 grid_mapper.py 里新加的
# 行跨度压缩（MAX_CLUSTER_ROW_SPAN），单个长条物体现在最多也就占几个格，
# 22 的上限基本用不到；调到 12 是给"椅子+气球同时出现"这种多目标场景留
# 余量，正常单目标场景实际激活数会远低于这个上限。
MAX_ACTIVATIONS = 12        # cap total activated dots (90 total)

# Absolute fallback thresholds (used when depth IS in real meters, e.g. stereo cam)
DANGER_NEAR_M = 0.5
WARNING_MEDIUM_M = 1.0
ATTENTION_FAR_M = 2.0

# ── Braille dot patterns ───────────────────────────────
# Each module: 2 cols × 3 rows of SMA dots, bit0~bit5
# Bit layout (ESP32 convention): bit0=col1-top, bit1=col1-mid, bit2=col1-bot,
#                                bit3=col2-top, bit4=col2-mid, bit5=col2-bot
BRAILLE_ALL_ON  = 0x3F   # ▓▓▓ (all 6 dots)
BRAILLE_NEAR    = 0x2F   # dots: col1-bot, col2-all (bottom-heavy warning)
BRAILLE_MEDIUM  = 0x1B   # dots: col1-all, col2-mid
BRAILLE_FAR     = 0x09   # dots: col1-mid, col2-top (light touch)
BRAILLE_NONE    = 0x00   # clear

# ── Dual-mode thresholds ───────────────────────────────
# MODE_RAPID_AVOID: fast obstacle detection, wider FOV
RAPID_AVOID_STEP_MS = 100       # frame interval

# MODE_LOCAL_ZOOM: detailed near-field, narrower FOV
LOCAL_ZOOM_RANGE_M = 1.5        # only show obstacles within 1.5m
LOCAL_ZOOM_STEP_MS = 200        # frame interval

# ── Alternative: Edge-based pipeline (paper method) ────
# Lightweight fallback when Depth Anything is too heavy
EDGE_BINARY_THRESHOLD = 90      # grayscale → binary threshold
EDGE_GAUSSIAN_KERNEL = (5, 5)   # blur kernel
EDGE_CANNY_LOW = 50
EDGE_CANNY_HIGH = 150
EDGE_MIN_CONTOUR_AREA = 1000    # px², paper used 1000 for 640×480

# ── Output ─────────────────────────────────────────────
# Serial to ESP32 (UART)
SERIAL_PORT = "/dev/ttyUSB0"  # or /dev/serial0 for RPi GPIO UART
SERIAL_BAUDRATE = 115200

# Frame format: 90 bytes, one per SMA dot (9 cols × 10 rows)
# Each byte: 0 or 1 (single dot on/off)
FRAME_LEN = 90

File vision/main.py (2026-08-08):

#!/usr/bin/env python3
"""
LingTouch Companion — Vision Pipeline Entry Point

Camera → Depth Estimation / Edge Detection → Grid Mapping → Braille Frame → Output

Usage:
  # Depth-based (primary, requires PyTorch + Depth Anything V2)
  python main.py --mode depth --camera 0 --output serial

  # Edge-based (lightweight fallback, runs on any hardware)
  python main.py --mode edge --camera 0 --output serial

  # Test with image file
  python main.py --mode edge --image path/to/test.jpg --output file

  # Visual debug window
  python main.py --mode edge --camera 0 --debug

Reference:
  Depth mode: Depth Anything V2 monocular depth estimation
  Edge mode:  CHI '25 "Seeing with the Hands" contour-based method (Teng et al.)

Architecture:
  ┌──────────┐     ┌──────────────┐     ┌───────────┐     ┌──────────┐
  │  Camera  │────▶│  Processor   │────▶│  Mapper   │────▶│  Sender  │
  │ (USB/RPi)│     │ depth/edge   │     │ depth→grid│     │serial/   │
  └──────────┘     └──────────────┘     └───────────┘     │BLE/file  │
                                                           └──────────┘
"""

import argparse
import sys
import time
import signal
import numpy as np

from camera import USBCamera, FileSource
from depth_estimator import DepthEstimator, SimpleDepthEstimator
from edge_detector import EdgePipeline
from grid_mapper import (
    depth_map_to_braille_frame,
    edge_cells_to_braille_frame,
    apply_rapid_avoid_mode,
    apply_local_zoom_mode,
    mirror_frame_horizontal,
    visualize_frame,
)
from output_sender import create_sender
from config import (
    FRAME_LEN,
    RAPID_AVOID_STEP_MS,
    LOCAL_ZOOM_STEP_MS,
    MIRROR_HORIZONTAL,
)

# Global flag for graceful shutdown
_running = True


def signal_handler(sig, frame):
    global _running
    _running = False
    print("\n[Vision] Shutting down...")


signal.signal(signal.SIGINT, signal_handler)
signal.signal(signal.SIGTERM, signal_handler)


# ═══════════════════════════════════════════════════════════
#  Pipeline runners
# ═══════════════════════════════════════════════════════════

def run_depth_pipeline(camera, sender, mode="rapid_avoid", debug=False):
    """Depth Anything V2 pipeline."""
    print("[Vision] Initializing Depth Anything V2 pipeline...")
    try:
        estimator = DepthEstimator(model_size="small", use_gpu=False)
        estimator.load()
    except Exception as e:
        print(f"[Vision] Depth model load failed: {e}")
        print("[Vision] Falling back to SimpleDepthEstimator (heuristic).")
        estimator = SimpleDepthEstimator()

    step_ms = RAPID_AVOID_STEP_MS if mode == "rapid_avoid" else LOCAL_ZOOM_STEP_MS
    print(f"[Vision] Depth pipeline running. Mode={mode}. Ctrl+C to stop.")

    while _running:
        frame_bgr, ts = camera.read()
        if frame_bgr is None:
            print("[Vision] Camera read failed, retrying...")
            time.sleep(0.5)
            continue

        # Depth estimation
        depth_map = estimator.estimate(frame_bgr)

        # Depth → braille frame (摄像头视角)
        braille = depth_map_to_braille_frame(depth_map, frame_bgr=frame_bgr)

        # Apply mode-specific processing
        if mode == "rapid_avoid":
            braille = apply_rapid_avoid_mode(braille)
        elif mode == "local_zoom":
            braille = apply_local_zoom_mode(braille, depth_map)

        # Send — 镜像只在打包发给设备这一步做，触点朝向使用者
        if sender:
            sender.send(mirror_frame_horizontal(braille) if MIRROR_HORIZONTAL else braille)

        # Debug display — 保持摄像头视角，方便和实际画面对照
        if debug:
            print(f"\r[Vision] Frame @ {ts:.1f}  ", end="")
            print(visualize_frame(braille))

        # Frame rate control
        elapsed = (time.time() - ts) * 1000
        sleep_ms = max(1, step_ms - elapsed)
        time.sleep(sleep_ms / 1000.0)


def run_edge_pipeline(camera, sender, mode="rapid_avoid", debug=False):
    """Edge/contour-based pipeline (CHI '25 paper method)."""
    print("[Vision] Initializing edge-detection pipeline...")
    pipe = EdgePipeline()

    step_ms = RAPID_AVOID_STEP_MS if mode == "rapid_avoid" else LOCAL_ZOOM_STEP_MS
    print(f"[Vision] Edge pipeline running. Mode={mode}. Ctrl+C to stop.")

    while _running:
        frame_bgr, ts = camera.read()
        if frame_bgr is None:
            print("[Vision] Camera read failed, retrying...")
            time.sleep(0.5)
            continue

        # Edge detection + grid projection
        if debug:
            activated, debug_data = pipe.process(frame_bgr, return_debug=True)
        else:
            activated = pipe.process(frame_bgr)

        # Edge cells → braille frame (摄像头视角)
        braille = edge_cells_to_braille_frame(activated)

        # Send — 镜像只在打包发给设备这一步做，触点朝向使用者
        if sender:
            sender.send(mirror_frame_horizontal(braille) if MIRROR_HORIZONTAL else braille)

        # Debug display
        if debug:
            print(f"\r[Vision] Frame @ {ts:.1f}  activated={len(activated)} cells  ", end="")
            print(debug_data)

        # Frame rate control
        elapsed = (time.time() - ts) * 1000
        sleep_ms = max(1, step_ms - elapsed)
        time.sleep(sleep_ms / 1000.0)


# ═══════════════════════════════════════════════════════════
#  Test mode: single image
# ═══════════════════════════════════════════════════════════

def run_single_test(image_path, use_depth=False):
    """Process a single image and print the braille frame."""
    import cv2

    frame = cv2.imread(image_path)
    if frame is None:
        print(f"[Vision] Cannot read image: {image_path}")
        return

    print(f"[Vision] Processing: {image_path} ({frame.shape[1]}×{frame.shape[0]})")

    if use_depth:
        try:
            estimator = DepthEstimator(model_size="small", use_gpu=False)
            estimator.load()
        except Exception as e:
            print(f"[Vision] Real model unavailable: {e}")
            print("[Vision] Falling back to SimpleDepthEstimator.")
            estimator = SimpleDepthEstimator()
        depth_map = estimator.estimate(frame)
        braille = depth_map_to_braille_frame(depth_map, frame_bgr=frame)
    else:
        pipe = EdgePipeline()
        activated = pipe.process(frame)
        braille = edge_cells_to_braille_frame(activated)
        print(f"  Activated cells: {activated}")

    print("\n  Braille Frame (hex):")
    print(f"  {' '.join(f'{b:02X}' for b in braille)}")
    print()
    print(visualize_frame(braille))
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

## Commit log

2026-07-20 Initial commit: LingTouch Companion (灵触·随行)
    Four-layer assistive navigation system:
    - vision/ — Depth Anything V2 + CHI '25 edge detection pipeline
    - app/backend/ — Node.js Express API (map, assistant, vision relay)
    - app/frontend/ — uni-app (Vue 3) mobile app
    - firmware/ — ESP32-S3 SMA braille module driver
2026-07-20 vision: fix depth direction, add dual-threshold + bottom penalty for 9x10 grid
    - Invert depth to disparity (higher=closer) in grid_mapper
    - Per-row P25 baseline replaces broken perspective model
    - Dual-threshold binarization (Q78 strong / Q65 weak+neighbour)
    - Linear bottom penalty to suppress floor fill
    - Cap at 30 activations, small-cluster filter
    - 9x10 dot frame protocol (90 bytes)
    [config.py, grid_mapper.py, output_sender.py]
2026-07-21 vision: fix depth direction, per-row P25 baseline + dual-threshold + bottom penalty
    - Cap at 25 activations, small-cluster filter
    - 9×10 SMA dot frame protocol (90 bytes)
    - Add live_preview.py (webcam real-time)
    - Add generate_comparison.py (static image comparison)
    - Add phone_camera.html + phone_server.py (phone camera relay)
    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
    [config.py, generate_comparison.py, grid_mapper.py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]
2026-08-02 vision: BLE control link + on-body mirror fix
    - scan_link.py (renamed from scna_link.py): drop all serial trigger
    logic, connect directly via bleak, subscribe FFE3, write 15-byte
    frame to FFE1 on EVT_SCAN_REQUEST (0x04) — matches sth2.html's
    Web Bluetooth implementation
    - Fix deadlock in scan_link._write(): BLE notify callbacks run on the
    event loop's own thread, so blocking there on
    run_coroutine_threadsafe(...).result() was waiting on itself and
    timing out every write, eventually dropping the connection
    - phone_server.py: switch CLI from --serial-port/--no-serial to
    --ble-device/--no-ble; fix preview window reopening after being
    closed (cv2.getWindowProperty check)
    - requ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
    [bench_test.py, braille_15module_prod.ino, config.py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]
2026-08-11 feat: merge local voice-assistant features into LingTouchCompanion
    - 地图切换为百度地图方案:JS API key 统一配置于 config/baidu.js,
    REST 接口经后端 /api/map/* 代理调用,AK 不暴露前端
    - 新增危险播报系统:utils/hazardEngine.js(分级播报/去重/优先级)
    + utils/hazardMockSource.js(演示数据源)+ components/hazard-banner.vue,
    App.vue 启动时注册并常驻监听
    - 新增语音播报模块 utils/tts.js(优先级控制/开关持久化/返回 Promise)
    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
2026-10-08 Consolidate 3D model sources under 3mf and add Braille module models
    - Move headset front/rear inputs and generators into self-contained 3mf/,
    dropping superseded intermediates; add Handle and PCB STEP sources.
    - Add BrailleModule static model and BrailleModule_Video preview work
    (iteration snapshots in Archives/ kept local via .gitignore).
    - File PCB1_5 pre-power review notes and diagrams under 3mf/PCB.
    [AppearanceStudy.blend, BTTF_Glasses.3mf, BrailleModule.blend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]
2026-10-09 Add PCB review drafts and Cycles array rendering handoff
    Retain the five-page schematic, two unrouted placement drafts, native exports and verification records. Document the latest layout deficiencies and pending firmware compatibility work for Claude revi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
    Migrate array production output to the saved Cycles scene with 90 animated dots, review stills and selected material sources. Mark realism as unresolved and record the revised single-module compariso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
    [EnclosedArray.blend]
2026-11-05 安卓端 CS30：开流前检查配置、失败复位重试、断开重连后重开、界面显示诊断日志
    Claude-Session: https://claude.ai/code/session_013PZTDqB6yyyz344UPvHSdq
2026-11-06 视觉处理+安卓端
2026-11-10 core: define IMU (BWT901BLECL5.0) interface: ImuSample, ImuAdapter, factory
    App pushes raw BLE notify bytes via ImuAdapter::push_notify; the core
    parses the default 0x55 0x61 packet and calls back with ImuSample.
    Interface only, not implemented.
    Claude-Session: https://claude.ai/code/session_013PZTDpGF1Ytzd2pqSa3zAB
2026-11-11 feat: 接入 BWT901BLECL5.0 IMU 接收与解析
